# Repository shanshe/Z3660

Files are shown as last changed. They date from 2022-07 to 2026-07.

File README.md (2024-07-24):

# Z3660 by sHaNsHe (Double H Tech)

<br>Z3660 is an Amiga 4000 CPU accelerator board based on A3660 and Z-turn FPGA board.
<br>
<br>Compared to A3660, Z3660 has some key differences:
<br><p style="margin-left:1em;">
<br><b>1</b>. Z3660 accelerator board can only use 060 CPUs. This could be changed in the future, but at this time, only 060 is supported.
<br>
<br><b>2</b>. If Z-turn FPGA board is <b>NOT</b> used, then you get a simple A3660. The only difference is that all A3660 PLDs are replaced by a XC95144XL-10TQ144 CPLD. It could be possible to use 060 up to 100MHz, but only 50 MHz and 64 MHz has been tested. A board with 128 MB of CPU RAM is in the works (to be connected at Z-turn sockets).
<br>
<br><b>3</b>. If you <b>use a Z-turn FPGA board</b>, then you can add 128 MB of CPU RAM (DMA compatible), 256 MB of Z3 RAM (not DMA compatible), RTG 16bit, Ethernet, AHI and MHI. Also there is a SD to SCSI emulation for using raw RDB disk images (USB storage maybe in the future). And of course, you can use a 68060 rev6 at 100 MHz.
<br><p style="margin-left:0em;">
<br><b>Main branch. Z3660 with Z-turn FPGA</b>
<br>
<br>This main branch has everything you need to build a Z3660 with Z-turn FPGA.
<br>If you want to build Z3660 without Z-turn FPGA, please go to wo_FPGA branch. The board is the same, but the CPLD firmware and BOM are obviously different.
<br>
<br>Current version of Schematics is v021. It has all fixes needed by v02 to have DMA compatibility (tested with ReA4091 as bus master), so you can build it.
<br>
<br>The exact model of Z-Turn board you will need is: MYS-7Z020-V2 ( [mouser](https://www.mouser.com/c/?q=MYS-7Z020-V2-0E1D-766-C) (C or C-S. C-S has restrictions on EU - UK) ).

<br>
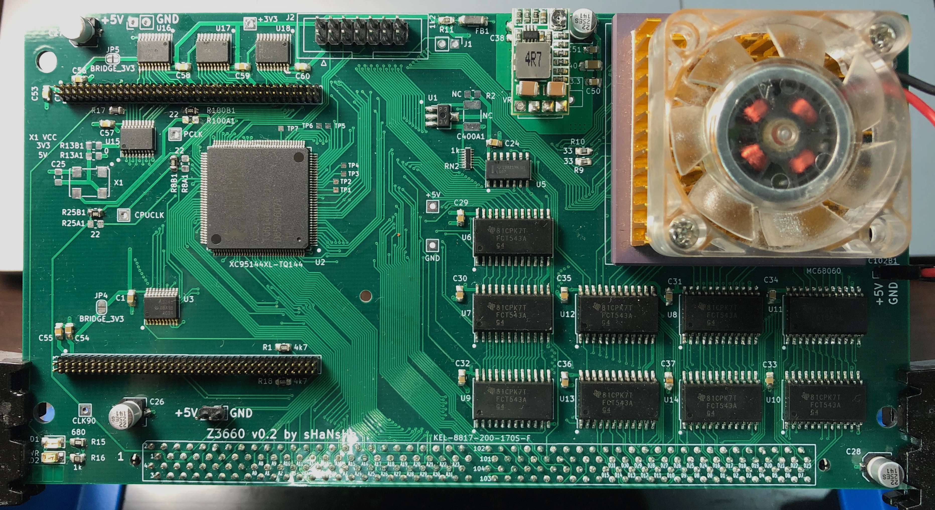
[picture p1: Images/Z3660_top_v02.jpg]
<br><p style="text-align:center;"><br>v0.2 Z3660 without FPGA</br></p>
<br>
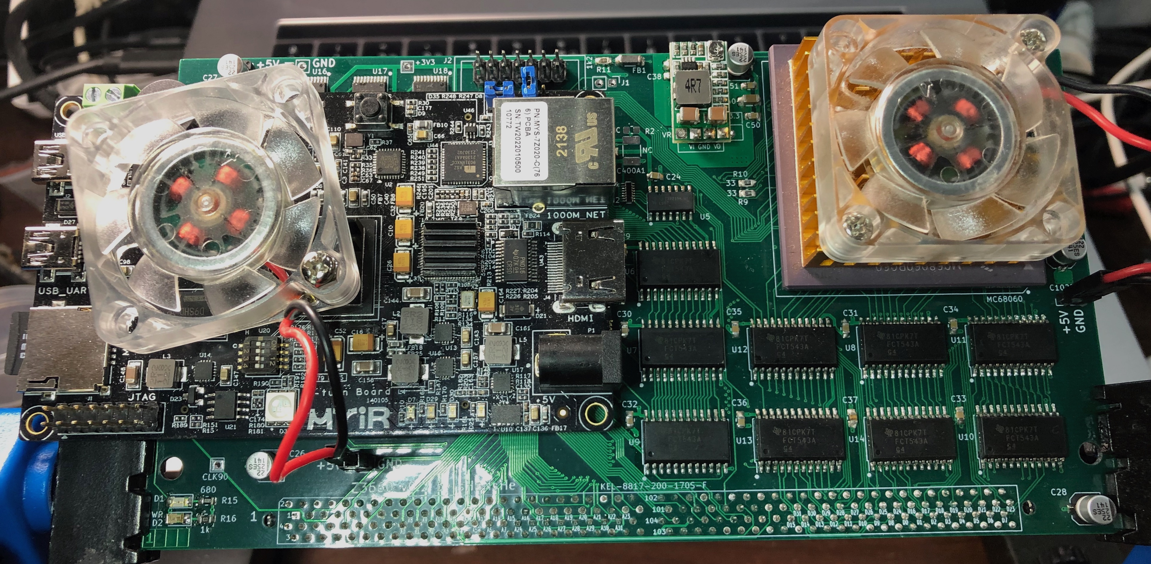
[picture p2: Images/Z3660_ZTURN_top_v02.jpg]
<br><p style="text-align:center;"><br>v0.2 Z3660 with FPGA</br></p>
In this version you can see that I have used a 3V3 DCDC converter, instead of old linear regulator on VR1. Board has both footprints in one. Please be careful with its connection.
<br>
<br>Note on RTG status: RTG is full working now. It has all features that ZZ9000 has (except obviously scandoubler). Due limitations of Z-turn, output video is limited to 16 bit.
<br>Manufacturer ID was asigned to 5195 decimal, 0x144B hexadecimal (thanks to Olaf Barthel).
<br>All RTG, AHI and MHI are based on [ZZ9000 RTG](https://source.mnt.re/explore).
It has the same band-pass filters as the AX module, but made in software by one of the ARMs.
<br>
<br><b>And finally, a checkmate move...</b>
<br>
<br><i>Don't have a 060 rev6 CPU, and still want to try Z3660 with a Z-turn?</i>
<br><i>sHaNsHe to the rescue!!! :P</i>
<br>
<br>One of the Z-turn ARM CPU can run the emulation code of a 68040 CPU with JIT that reaches up to 120 MIPS!!!<br>It is based on Amiberry CPU code (for 32bit ARM). (And yes, I know, but Emu68 no longer supports 32 bit ARM).
<br>You can even switch between the real 060 CPU and the emulation by clicking on an app (and rebooting).
<br>
<br><b>Discord channel link:</b>
<br><br>https://discord.gg/ua4u6SzyHf
<br>
<br><b>Documents to read before using your Z3660</b><br>
<br> You should read the "KNOWN_ISSUES.md" and "CHANGES.md" files to know the latest news.
<br> Thanks to ByteMavericks we have now the [wiki](https://github.com/shanshe/Z3660/wiki)

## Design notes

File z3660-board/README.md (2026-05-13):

# Z3660 PCB

In this folder are the fabrication files (Gerber) I have sent to JLCPCB.

I have built the first prototype of version v0.21 and it is working as expected.

# BOM revisions
v0.21
 * 08/04/2023: First version uploaded.

 * 08/11/2023: C27 capacitor has been removed from BOM because it is under Z-turn and there is no enough space for an electrolytic capacitor. You can use another 10uF SMD capacitor, or simply ignore it, we have a lot of capacitors in this board...

 * 08/13/2023: Updated BOM with I2C LTC2990 (tested today). It measures 5V, 3V3 and 060 THERM resistor.

v0.21a
 * 01/07/2024: Updated resistor network footprints to 4x (instead of 8x).
 * 01/07/2024: Updated electrolytic capacitor footprints to bigger ones.
 * 01/08/2024: Updated led values to differentiate green and red.
 * 01/08/2024: Uploaded BOM and CPL files for JLCPCB (thanks to @kavanoz64).
 
 v0.21b
 * 09/02/2024: Updated 060 footprint to 18x18 array pins (full 4 rows and columns).
 
 v0.21c
 * Invalid version - this was a misnamed upload during v0.21a release and should be disregarded.
 
 v.021d
 * 03/03/2024 Changed the footprints for two fans to 3-pin right-angle connectors.
 * 04/10/2024 Z3660_CPLD_prog is a tiny PCB to provide a CPLD programmer for v0.21x versions.
 
 v.022
 * 04/10/2024 Added an I2C gpio expander (PCF8574) to program the CPLD from the ARM.
 * 04/10/2024 Added optional onboard voltage regulator based on torsti76's <span>&#181;</span>VRM v0.1 design.
 
 v.023 (Contributed by @kavanoz)
 * 05/13/2026 Connected BOSS to DBG3 to allow motherboard CPU option.
 * 05/13/2026 Moved ZTurn 5mm towards the 060.
 * 05/13/2026 Removed voltage detector alternatives to save space for moving components.
 * 05/13/2026 Added a shunt for 3.34V solder jumper to set it as default. It needs to be cut before changing the onboard voltage regulator output.

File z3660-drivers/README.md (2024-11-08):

# Z3660 drivers

To build all these drivers, you will need vbcc and m68k-amigaos-gcc compilers. Also you will need a NDK (I'm using NDK from OS3.9).
<br>To build ZTop app you will need SASC under vamos emulation.
<br>See Makefile in order to adjust your paths.
<br>With the command line:
<br>`make all`
<br>you will compile all necessary drivers.
<br>If you have xdftool installed, then you can create an adf file that contains all drivers to be copied to your Amiga:
<br>`make adf`
<br>This will create an adf file called "0_Z3660.adf".
<br>The "z3660_scsi.rom" file (scsi directory) must be copied to the second partition of the SD (the exFAT formatted partition).

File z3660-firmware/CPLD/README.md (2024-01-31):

# Z3660 CPLD

Two versions here:

 * <b>DMA_WIP</b> is a "work in progress" (WIP) version, which works with Z3 DMA masters. Right now has some problems to boot, as it may need some reset before boot (maybe even power off-on cycles). This version only works with real cpus. CPU emulation has nothing to do with DMA (need some missing functions on emulation and a lot of test), so don't even try it...

 * <b>MASTER_no_DMA</b> version works with both, 060 and CPU emulation. Real cpu should be a 060 rev 6 as all firmware here is working only at 100 MHz. I have tried other frequencies, but only some "magic" frequencies work. ZTop app (z3660-drivers) will have some kind of frequency adjusment but right now this adjusment is internally disabled in this application. WIP.
 
Version History:
 * <b>v1.01</b>: First "official" version
 * <b>v1.02</b>: Update no_DMA version to get close to DMA branch (but still is a no_DMA version).
<br>
<br>

Important Note:
<br>
<br>You <b><i>should</i></b> use the vX.XX version with the same version numbers of BOOT.bin and drivers!!!

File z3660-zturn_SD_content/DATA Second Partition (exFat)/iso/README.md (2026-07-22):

# SCSI - CDROM Image files
Put in this directory all iso images that you want to mount with SD SCSI emulation (you can use up to 7 hdfs/isos).

Remember their names, you will need to name them exactly (with path: iso/image.iso) in the z3660cfg.txt file.

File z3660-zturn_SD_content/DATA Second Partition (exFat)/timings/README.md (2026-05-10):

# TIMING FILES
## Beta 18 and beta 19 versions:
The <b>timings.txt</b> is a text file with the name of the timings file that the ARM of the ZTurn board will use to generate all clocks needed for the Z3660.<br>

For now, we have only two sets of timings: A4000 and AA3000 (the systems that I own).<br>
The idea is that those files can be adapted to different systems, and if a user discovers that some different phases work better than others, the user can share those files and more users can benefit from it.
<br>
Starting version 1.03 BETA 18, the clock system has been changed so when an EMU is used, then the 060 is clocked to 50 MHz or less. For this reason the CPLD now needs to be programmed with the jed BETA 18 version.
<br>
## Beta 20 version:
The <b>timings.txt</b> is a text file with the name of the timings file that the ARM of the ZTurn board will use to generate all clocks needed for the Z3660.<br>

In this beta 20 version, we go back to CPLD beta 12 timings. We have a default timings file that work for A4000 and AA3000 (the systems that I own).<br>
The user can adapt the timings to different systems using the Ztop ARM app.<br>

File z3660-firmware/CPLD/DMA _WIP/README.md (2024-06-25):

# Z3660 CPLD

To build CPLD XC95144XL, I use ISE 13.1. Also I use IMPACT to flash the device, with a platform cable from Xilinx (use "JTAG" labeled connector of the PCB).
<br>Optionally, there are people flashing these CPLDs using a Raspberry Pi... google for it if you need it.
<br>The "z3660.jed" file is what you flash into the CPLD.

## NOTE WIP
This is a WIP version that is compatible with Z3 DMA devices. As it stated here, this firmware is under construction. WIP.

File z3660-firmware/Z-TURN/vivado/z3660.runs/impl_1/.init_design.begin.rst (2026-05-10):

<?xml version="1.0"?>
<ProcessHandle Version="1" Minor="0">
    <Process Command=".planAhead." Owner="shanshe" Host="COREBOX-X" Pid="1084">
    </Process>
</ProcessHandle>

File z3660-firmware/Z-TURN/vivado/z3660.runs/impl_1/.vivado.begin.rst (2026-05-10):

<?xml version="1.0"?>
<ProcessHandle Version="1" Minor="0">
    <Process Command="vivado.bat" Owner="shanshe" Host="COREBOX-X" Pid="10788" HostCore="4" HostMemory="017054048256">
    </Process>
</ProcessHandle>
<?xml version="1.0"?>
<ProcessHandle Version="1" Minor="0">
    <Process Command="vivado.bat" Owner="shanshe" Host="COREBOX-X" Pid="11004" HostCore="4" HostMemory="017054048256">
    </Process>
</ProcessHandle>
<?xml version="1.0"?>
<ProcessHandle Version="1" Minor="0">
    <Process Command="vivado.bat" Owner="shanshe" Host="COREBOX-X" Pid="15328" HostCore="4" HostMemory="017054048256">
    </Process>
</ProcessHandle>

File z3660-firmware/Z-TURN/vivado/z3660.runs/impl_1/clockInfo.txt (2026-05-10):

-------------------------------------
| Tool Version : Vivado v.2023.2
| Date         : Wed May  6 09:28:42 2026
| Host         : CoreBox-X
| Design       : design_1
| Device       : xc7z020-clg400-3--
-------------------------------------

For more information on clockInfo.txt clock routing debug file see https://support.xilinx.com/s/article/000035660?language=en_US

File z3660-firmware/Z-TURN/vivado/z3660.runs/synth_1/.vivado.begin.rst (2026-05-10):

<?xml version="1.0"?>
<ProcessHandle Version="1" Minor="0">
    <Process Command="vivado.bat" Owner="shanshe" Host="COREBOX-X" Pid="13924" HostCore="4" HostMemory="017054048256">
    </Process>
</ProcessHandle>

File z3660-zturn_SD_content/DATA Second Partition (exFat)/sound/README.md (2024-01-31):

# SOUND FILES
These are mp3 files with Siri/Alexa voices-like, to be played when you maintain reset more than 4 seconds.
<br>Just copy all these files.
<br>When you maintain reset you will hear, at the HDMI audio output, a voice telling you what is selected in this moment. The 4 files are for "060 CPU", "MUSASHI EMULATION", "UAE EMULATION" and "UAE JIT EMULATION" (in this order).
<br>
<br>Important Note:
<br>
<br>Right now only the "spa" (spanish voice) directory is played (it is hard coded in the ARM sources), so if you want to play the "eng" (english voice) files you should copy them to the "spa" directory.

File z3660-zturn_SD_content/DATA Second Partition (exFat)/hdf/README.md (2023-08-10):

# SCSI - Hard Disk Image files
Put in this directory all hdf images that you want to mount with SD SCSI emulation (you can use up to 7 hdfs).

Remember their names, you will need to name them exactly (with path: hdf/image.hdf) in the z3660cfg.txt file.

SD SCSI emulation <b>DO NOT</b> work with UAE single partition disk images. You can check what type the disk image is using a hex editor: if it starts with "RDSK", it is a full drive RDSK/RDB image and will work here. If it starts with "DOS" it is most likely a UAE single partition disk image and will not work.

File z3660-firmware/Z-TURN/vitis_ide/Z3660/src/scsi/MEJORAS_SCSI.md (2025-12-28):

# Mejoras del módulo SCSI (Z3660/src/scsi)

Fecha: 2025-08-24
Ámbito: scsi.c, scsi.h, hunk-reloc.c, hunk-reloc.h, z3660_scsi_enums.h

Objetivo: Recopilar y priorizar mejoras de robustez, seguridad, rendimiento y mantenibilidad en el subsistema SCSI del proyecto Z3660.

Resumen de prioridades
- Alta: correcciones que previenen fallos, desbordamientos, fugas y corrupción de datos.
- Media: robustez, validaciones, consistencia de API, tratamiento de errores y límites.
- Baja: rendimiento fino, ordenamiento del código, mejoras de logging y observabilidad.

Prioridad alta (bugs y riesgos)
1) Índice de unidad fuera de rango
- Problema: en piscsi_map_drive(), el control usa if (index > NUM_SCSI_UNITS_MAX). Permite index == NUM_SCSI_UNITS_MAX, fuera de rango.
- Mejora: cambiar a if (index >= NUM_SCSI_UNITS_MAX) y devolver error claro.
- Ficheros: scsi.c

2) Valor inválido de piscsi_cur_drive (255) y accesos no validados
- Problema: PISCSI_CMD_DRVNUM puede asignar 255; varias lecturas usan devs[piscsi_cur_drive] sin validar.
- Mejora: no asignar valores inválidos; si la entrada es inválida, conservar el valor actual y devolver 0/ERR. Alternativamente, validar piscsi_cur_drive >= NUM_SCSI_UNITS_MAX en cada uso y abortar segura/rápidamente.
- Ficheros: scsi.c

3) Fugas de memoria en piscsi_find_filesystems()
- Problema: se hace malloc de fhb_block en el bucle y no siempre se libera (leak); sólo algunas copias se guardan en filesystems[].fhb.
- Mejora: usar un buffer de escaneo único (malloc una vez), y cuando se deba persistir un FSHD, copiarlo explícitamente a filesystems[i].fhb (malloc + memcpy). Liberar el buffer de escaneo al final.
- Ficheros: scsi.c

4) Tamaño y límites de relocalización (HUNK_RELOC)
- Problema: piscsi_hreloc es 2048 pero filesystems[i].relocs es 4096; hunk-reloc no limita el número de entradas y puede sobrescribir memoria si hay muchas relocs.
- Mejora: definir una constante global MAX_HUNK_RELOCS (por ejemplo, 4096) y:
  - Dimensionar piscsi_hreloc a MAX_HUNK_RELOCS.
  - En HUNKTYPE_HUNK_RELOC32, cortar si se supera MAX_HUNK_RELOCS y devolver error.
  - Propagar el error a quien llama.
- Ficheros: scsi.c, hunk-reloc.c, scsi.h (si se expone la constante)

5) Validación de block_size
- Problema: d->block_size proviene del RDB sin validar y se usa en malloc y lecturas.
- Mejora: validar 0 < block_size <= PISCSI_MAX_BLOCK_SIZE y que sea múltiplo de 512. Si no, decidir política: fijar 512 o abortar.
- Ficheros: scsi.c

6) Persistencia tras escrituras (f_sync)
- Problema: tras f_write no se llama a f_sync; riesgo de pérdida de datos en reset/cortes.
- Mejora: llamar a f_sync(d->fd) al finalizar operaciones de escritura de alto nivel o según umbral de bytes acumulados; opcionalmente controlable por configuración.
- Ficheros: scsi.c

7) Lecturas/escrituras RAW SD no alineadas a bloque
- Problema: en backend RAW (disk_read/disk_write) se calcula blocks = bytes / block_size y se ignora el resto.
- Mejora: definir política clara: o rechazar tamaños no alineados con error, o manejar el remanente con buffer temporal.
- Ficheros: scsi.c

8) Límite de particiones
- Problema: d->pb[16]; al seguir la lista enlazada PARTITIONLIST no se corta explícitamente tras 16.
- Mejora: si cur_partition alcanza 16, dejar de cargar y avisar.
- Ficheros: scsi.c

Robustez y corrección
1) Inclusión circular innecesaria
- Problema: hunk-reloc.h incluye scsi.h y scsi.h incluye hunk-reloc.h.
- Mejora: eliminar include de scsi.h en hunk-reloc.h (no es necesario); si se requieren tipos, reubicar typedefs o usar forward declarations.
- Ficheros: hunk-reloc.h

2) Firmas const-correct
- Mejora: io_cmd_name() y scsi_cmd_name() deben devolver const char*.
- Ficheros: scsi.c

3) Límite de filesystems
- Problema: piscsi_num_fs puede exceder NUM_FILESYSTEMS si hay demasiados FSHD.
- Mejora: comprobar y dejar de cargar (con log) al alcanzar NUM_FILESYSTEMS.
- Ficheros: scsi.c

4) Control de errores más consistente
- Observación: a veces se imprime error tras f_read/f_write/disk_read pero no se propaga y se continúa.
- Mejora: unificar estrategia: si un acceso a disco falla, propagar el error y abortar la operación (evitar relocalizaciones/copias con datos incompletos). Añadir códigos de retorno o enum de errores.
- Ficheros: scsi.c, hunk-reloc.c

5) Validación de punteros mágicos en backend
- Problema: se usa (FIL*)1 para distinguir RAW SD vs archivo.
- Mejora: añadir campo backend en PISCSI_DEV (FILE/HDF vs RAW_SD) y evitar comparaciones de punteros. Centralizar lógica de IO.
- Ficheros: scsi.h (enum/flag), scsi.c

6) Nombres de partición y límites de buffer
- Problema: al renombrar particiones duplicadas se puede exceder pb_DriveName[32].
- Mejora: usar snprintf y validar longitud; no exceder 31 chars + NUL. Actualizar pb->pb_DriveName[0] coherentemente.
- Ficheros: scsi.c

7) Validación de punteros/offsets de FSHD
- Mejora: validar que fhb->fhb_Next y rdb->rdb_FileSysHeaderList estén dentro del tamaño del dispositivo. Si se sale, abortar con aviso.
- Ficheros: scsi.c

8) Valores CHS fabricados
- Mejora: al inventar CHS en falta de RDB, evitar overflow y documentar el cálculo. Considerar 255 heads/63 secs si el tamaño es grande (compatibilidad común), o usar LBA puro en capas superiores.
- Ficheros: scsi.c

Rendimiento
1) Flushing/invalidating por rango
- Mejora: usar Xil_L1DCacheFlushRange/InvalidateRange con puntero + tamaño cuando se conoce el buffer, en lugar de flush global. Reduce latencias.
- Ficheros: scsi.c

2) Reutilización de buffers
- Mejora: reservar buffers reutilizables (p. ej., para bloques de tamaño d->block_size y para FSHD) y evitar malloc/free repetido en bucles.
- Ficheros: scsi.c

3) Tamaño de ráfagas de IO
- Mejora: MAX_BLOCKS_AT_ONCE a una constante configurable en cabecera. Ajustar a límites del controlador y tamaño de caché.
- Ficheros: scsi.c, scsi.h (si procede)

4) memcpy_neon firma y fallback
- Mejora: declarar extern void* memcpy_neon(void* restrict dst, const void* restrict src, uint32_t n); usar memcpy para tamaños pequeños o no alineados. Evitar u32 si no está definido.
- Ficheros: scsi.c (declaración);

Mantenibilidad
1) Helpers de mapeo de memoria
- Mejora: extraer helpers:
  - bool is_fpga_mapped_addr(uint32_t a, const CONFIG* cfg)
  - uint32_t translate_fpga_to_arm(uint32_t a)
  - bool in_cpu_ram_range(uint32_t a), bool in_autoconfig_ram_range(uint32_t a)
- Beneficio: eliminar duplicación y errores (p. ej. restar 0x20000000 para 0x40000000–0x4fffffff).
- Ficheros: scsi.c (nuevas funciones estáticas)

2) API de backend de IO unificada
- Mejora: crear piscsi_seek_bytes(), piscsi_read_bytes(), piscsi_write_bytes(), piscsi_read_blocks(), piscsi_write_blocks() que internen la diferencia FILE vs RAW SD.
- Beneficio: simplifica el manejo de errores, f_sync y métricas.
- Ficheros: scsi.c, scsi.h (si se expone)

3) Tipos y casts explícitos
- Mejora: usar size_t/FSIZE_t donde corresponda; añadir casts explícitos 32↔64 para offsets.
- Ficheros: scsi.c, hunk-reloc.c

4) Logging y rutas del usuario
- Mejora: centralizar DEBUG/printf bajo función que permita, opcionalmente, volcar a archivos de log del usuario:
  - /Volumes/datos/log.txt
  - /Volumes/datos/log_arm.txt
  - /Volumes/datos/log_trident.txt
- Añadir niveles (INFO/WARN/ERR/DEBUG) y toggles vía debug_console.
- Ficheros: scsi.c (envoltorio de logging)

5) Unificación de macros endian
- Mejora: unificar BE, BE16, etc., en una cabecera común y usar consistentemente.
- Ficheros: scsi.c, hunk-reloc.c, scsi.h

Calidad de parsing (RDB/FS)
1) Verificación de checksums
- Mejora: comprobar rdb_ChkSum/pb_ChkSum/fhb_ChkSum cuando sea viable para detectar corrupción.
- Ficheros: scsi.c

2) Límites de recorrido
- Mejora: límite superior en RDB_BLOCK_LIMIT configurable; detener si se encuentran valores improbables.
- Ficheros: scsi.h (const), scsi.c

3) Manejo de errores en LSEG
- Mejora: en load_lseg/process_hunks, propagar errores de I/O y truncar con mensajes claros.
- Ficheros: hunk-reloc.c

Quick wins (bajo riesgo, alto valor)
- [ ] Cambiar if (index > NUM_SCSI_UNITS_MAX) por if (index >= NUM_SCSI_UNITS_MAX) en piscsi_map_drive().
- [ ] Validar piscsi_cur_drive antes de acceder a devs[]. Si inválido, devolver 0/ERR y log.
- [ ] io_cmd_name()/scsi_cmd_name() → const char*.
- [ ] Eliminar include de scsi.h en hunk-reloc.h (evitar inclusión circular).
- [ ] Unificar MAX_HUNK_RELOCS a 4096 y dimensionar piscsi_hreloc con ese valor.
- [ ] Añadir guardas en HUNKTYPE_HUNK_RELOC32 para no exceder MAX_HUNK_RELOCS.
- [ ] Llamar a f_sync(d->fd) tras escrituras grandes o al finalizar comandos de escritura.
- [ ] Validar y normalizar block_size tras parsear RDB (múltiplo de 512 y ≤ PISCSI_MAX_BLOCK_SIZE); fallback a 512 o abortar.
- [ ] Límite de 16 particiones: cortar recorrido y avisar si se excede.
- [ ] Comprobar piscsi_num_fs contra NUM_FILESYSTEMS en piscsi_find_filesystems().
- [ ] Rechazar o manejar remanentes en RAW SD si bytes % block_size != 0.

Observabilidad (opcional pero útil)
- [ ] Contadores: bytes leídos/escritos, errores de I/O, tiempos por operación (medidos), número de flushes de caché.
- [ ] Traces de comandos: BeginIO, SCSICMD, READ/WRITE con tamaños y tiempos cuando el debug esté activo.

Plan sugerido de adopción por fases
Fase 1 (1–2 commits rápidos)
- Quick wins anteriores (validaciones, límites, const-correct, include, MAX_HUNK_RELOCS + guardas, block_size, f_sync). Riesgo bajo.

Fase 2 (robustez de I/O y parsing)
- Backend explícito en PISCSI_DEV y helpers de I/O.
- Reutilización de buffers + corrección de fugas en piscsi_find_filesystems().
- Validaciones extra de RDB/FS (offsets, checksums, límites de partición/FS).

Fase 3 (rendimiento y limpieza)
- Cache flush por rango, unificación de macros endian, logging configurable, métricas.

Notas de implementación y ubicación
- Validaciones de índice/cur_drive: scsi.c (handlers de lectura/escritura y piscsi_map_drive()).
- f_sync: scsi.c (ruta de WRITE/WRITE64/WRITEBYTES; un posible “end of command” natural tras completar la escritura).
- MAX_HUNK_RELOCS: definir en scsi.h o nueva cabecera; usar en scsi.c y hunk-reloc.c.
- Guardas en relocalización: hunk-reloc.c (HUNKTYPE_HUNK_RELOC32, cortar y retornar error si se excede el límite).
- Backend explícito: añadir enum/flag en PISCSI_DEV (scsi.h) y setearlo en piscsi_map_drive().
- Reutilización de buffers: scsi.c (buffers estáticos o miembros en PISCSI_DEV si conviene).
- Eliminación de include circular: hunk-reloc.h (quitar include de scsi.h).

Fragmento clave (selección del usuario)
- Control de errores más consistente
  • A veces se imprime error tras f_read/f_write/disk_read pero no se propaga el fallo ni se aborta la operación. Conviene unificar: si un acceso a disco falla, devolver error hacia arriba y no continuar con copias/relocs.

Checklist global
- [ ] Validar índices y estados antes de acceder a devs[] (incluyendo piscsi_cur_drive).
- [ ] Normalizar block_size y rechazar valores inválidos.
- [ ] Límite de particiones y filesystems respetados.
- [ ] Guardas de relocalización implementadas y tamaño de buffers consistente.
- [ ] Fugas de memoria eliminadas (buffers de escaneo FSHD, devs[i].pb[j]).
- [ ] Política de I/O RAW para tamaños no alineados decidida e implementada.
- [ ] f_sync aplicado donde corresponda.
- [ ] Cache flush por rango aplicado donde es posible.
- [ ] Backend explícito y helpers de I/O creados.
- [ ] Logging centralizado con niveles y posibilidad de volcar a rutas del usuario.

Notas finales
- Estas mejoras están pensadas para minimizar riesgos en datos y facilitar diagnóstico, manteniendo la compatibilidad.
- Las “quick wins” son seguras y recomendadas para aplicar primero.
- Las fases 2 y 3 pueden hacerse de forma incremental con pruebas entre cada cambio.

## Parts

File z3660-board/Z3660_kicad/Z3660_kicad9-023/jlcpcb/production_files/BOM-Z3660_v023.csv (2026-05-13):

Comment | Designator | Footprint | LCSC | Quantity
100k | R31 | R_0603_1608Metric_Pad0.98x0.95mm_HandSolder | C25803 | 1
100nF | C67 | C_0603_1608Metric_Pad1.08x0.95mm_HandSolder | C14663 | 1
100nF | C1,C10,C11,C12,C13,C14,C15,C16,C17,C18,C19,C2,C20,C21,C22,C23,C24,C25,C29,C3,C30,C31,C32,C33,C34,C35,C36,C37,C38,C4,C44,C45,C46,C47,C48,C49,C5,C50,C51,C52,C53,C54,C55,C56,C57,C58,C59,C6,C60,C63,C64,C7,C8,C9 | C_0805_2012Metric_Pad1.18x1.45mm_HandSolder | C49678 | 54
10k | R34 | R_0603_1608Metric_Pad0.98x0.95mm_HandSolder | C25804 | 1
10nF | C65 | C_0603_1608Metric_Pad1.08x0.95mm_HandSolder | C57112 | 1
10uF | C39,C40,C42,C43 | C_1206_3216Metric_Pad1.33x1.80mm_HandSolder | C13585 | 4
10uF | C68 | C_0805_2012Metric_Pad1.18x1.45mm_HandSolder | C440198 | 1
10uH | L1 | L_Bourns_SRP7028A_7.3x6.6mm | C128692 | 1
120 | R19 | R_0805_2012Metric_Pad1.20x1.40mm_HandSolder | C17437 | 1
1k | R14,R16,R20,R21,R5,R6,R7,R8 | R_0805_2012Metric_Pad1.20x1.40mm_HandSolder | C17513 | 8
1k | RN1,RN11,RN12,RN13,RN14,RN15,RN16,RN17,RN18,RN19,RN2,RN20,RN21,RN22 | R_Array_Convex_4x0603 | C20197 | 14
1k 0.1% | R23,R24,R25 | R_0805_2012Metric_Pad1.20x1.40mm_HandSolder | C110774 | 3
1k2 | R11 | R_0805_2012Metric_Pad1.20x1.40mm_HandSolder | C17379 | 1
22 | RN10,RN3,RN4,RN5,RN6,RN7,RN8,RN9 | R_Array_Convex_4x0603 | C12008 | 8
22uF | C27 | CP_Elec_6.3x3.9 | C2761583 | 1
22uF | C26,C28,C41,C61,C62 | CP_Elec_6.3x5.4 | C445045 | 5
22uF | C69 | C_0805_2012Metric_Pad1.18x1.45mm_HandSolder | C45783 | 1
26.1k* | R32 | R_0603_1608Metric_Pad0.98x0.95mm_HandSolder | C23356 | 1
27.0k | R35 | R_0603_1608Metric_Pad0.98x0.95mm_HandSolder | C22967 | 1
27.4k | R36 | R_0603_1608Metric_Pad0.98x0.95mm_HandSolder | C2933186 | 1
28.0k | R37 | R_0603_1608Metric_Pad0.98x0.95mm_HandSolder | C22989 | 1
3.9nF | C66 | C_0603_1608Metric_Pad1.08x0.95mm_HandSolder | C1618 | 1
33 | R10,R28,R29,R9 | R_0805_2012Metric_Pad1.20x1.40mm_HandSolder | C17634 | 4
4k7 | R1,R13,R17,R18,R3 | R_0805_2012Metric_Pad1.20x1.40mm_HandSolder | C17673 | 5
6.8k | R33 | R_0603_1608Metric_Pad0.98x0.95mm_HandSolder | C23212 | 1
680 | R15 | R_0805_2012Metric_Pad1.20x1.40mm_HandSolder | C17798 | 1
7407 | U5 | SOIC-14_3.9x8.7mm_P1.27mm | C40481 | 1
74FCT543A | U10,U11,U12,U13,U14,U6,U7,U8,U9 | SOIC-24W_7.5x15.4mm_P1.27mm | C2863309 | 9
9k 0.1% | R22,R26,R27,R30 | R_0805_2012Metric_Pad1.20x1.40mm_HandSolder | C868262 | 4
BU4942 | U1B1 | TSOP-5_1.65x3.05mm_P0.95mm | C2067989 | 1
Conn_02x40_Odd_Even | CN2,CN3 | PinHeader_2x40_P1.27mm_Vertical | C7470095 | 2
Ferrite_Bead_Small | FB1 | Fuse_1806_4516Metric_Pad1.57x1.80mm_HandSolder | C88998 | 1
JTAG | J2 | PinHeader_1x06_P2.54mm_Vertical | C6332199 | 1
Jumper_2_Open | J1 | PinHeader_1x02_P2.54mm_Vertical | C358684 | 1
Jumper_3_Open | JP2,JP6,JP7 | PinHeader_1x03_P2.54mm_Vertical | C429954 | 3
Jumper_NO_Small | JP1,JP3 | PinHeader_1x03_P2.54mm_Horizontal | C722746 | 2
LED_Small_Green | D1 | LED_1206_3216Metric_Pad1.42x1.75mm_HandSolder | C434442 | 1
LED_Small_Red | D2 | LED_1206_3216Metric_Pad1.42x1.75mm_HandSolder | C434438 | 1
LTC2990 | U1 | MSOP-10_3x3mm_P0.5mm | C683931 | 1
MC68060 | U4 | PGA226 | C9900095602 | 1
MP2307 | U20 | SOIC-8-1EP_3.9x4.9mm_P1.27mm_EP2.514x3.2mm | C18921 | 1
PCF8574TS | U19 | TSSOP-20_4.4x6.5mm_P0.65mm | C57790 | 1
SN74CB3T3245PW | U15,U16,U17,U18,U3 | TSSOP-20_4.4x6.5mm_P0.65mm | C15298 | 5
XC95144XL-TQ144 | U2 | TQFP-144_20x20mm_P0.5mm | C1521137 | 1

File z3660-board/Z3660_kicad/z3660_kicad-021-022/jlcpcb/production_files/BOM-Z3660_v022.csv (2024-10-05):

Comment | Designator | Footprint | LCSC
LTC2990 | U1 | MSOP-10_3x3mm_P0.5mm | C107804
1k 0.1% | R23,R24,R25 | R_0805_2012Metric_Pad1.20x1.40mm_HandSolder | C110774
22 | RN10,RN3,RN4,RN5,RN6,RN7,RN8,RN9 | R_Array_Convex_4x0603 | C12008
Conn_02x40_Odd_Even | CN2,CN3 | PinHeader_2x40_P1.27mm_Vertical | C124356
Conn_02x07_Odd_Even | J2 | IDC-Header_2x07_P2.54mm_Vertical | C132432
10uF | C39,C40,C42,C43 | C_1206_3216Metric_Pad1.33x1.80mm_HandSolder | C13585
100nF | C67 | C_0603_1608Metric | C14663
XC95144XL-TQ144 | U2 | TQFP-144_20x20mm_P0.5mm | C1521137
SN74CB3T3245PW | U15,U16,U17,U18,U3 | TSSOP-20_4.4x6.5mm_P0.65mm | C15298
10µF | C68 | C_0805_2012Metric | C15850
3.9nF | C66 | C_0603_1608Metric | C1618
1k2 | R11 | R_0805_2012Metric_Pad1.20x1.40mm_HandSolder | C17379
100 | R13 | R_0805_2012Metric_Pad1.20x1.40mm_HandSolder | C17408
10k | R2 | R_0805_2012Metric_Pad1.20x1.40mm_HandSolder | C17414
120 | R19 | R_0805_2012Metric_Pad1.20x1.40mm_HandSolder | C17437
1k | R14,R16,R20,R21,R5,R6,R7,R8 | R_0805_2012Metric_Pad1.20x1.40mm_HandSolder | C17513
33 | R10,R28,R29,R9 | R_0805_2012Metric_Pad1.20x1.40mm_HandSolder | C17634
4k7 | R1,R17,R18,R3,R4 | R_0805_2012Metric_Pad1.20x1.40mm_HandSolder | C17673
680 | R15 | R_0805_2012Metric_Pad1.20x1.40mm_HandSolder | C17798
MP2307 | U20 | SOIC-8-1EP_3.9x4.9mm_P1.27mm_EP2.514x3.2mm | C18921
1k | RN1,RN11,RN12,RN13,RN14,RN15,RN16,RN17,RN18,RN19,RN2,RN20,RN21,RN22 | R_Array_Convex_4x0603 | C20197
BU4942 | U1B1 | TSOP-5_1.65x3.05mm_P0.95mm | C2067989
10µH | L1 | L_Bourns_SRP7028A_7.3x6.6mm | C208101
27.0k | R35 | R_0603_1608Metric | C22967
28.0k | R37 | R_0603_1608Metric | C22989
6.8k | R33 | R_0603_1608Metric | C23212
26.1k* | R32 | R_0603_1608Metric | C23356
100k | R31 | R_0603_1608Metric | C25803
10k | R34 | R_0603_1608Metric | C25804
22uF | C27 | CP_Elec_6.3x3.9 | C2761583
9k 0.1% | R22,R26,R27,R30 | R_0805_2012Metric_Pad1.20x1.40mm_HandSolder | C2828721
74FCT543A | U10,U11,U12,U13,U14,U6,U7,U8,U9 | SOIC-24W_7.5x15.4mm_P1.27mm | C2863309
27.4k | R36 | R_0603_1608Metric | C321828
Jumper_2_Open | J1 | PinHeader_1x02_P2.54mm_Vertical | C358684
7407 | U5 | SOIC-14_3.9x8.7mm_P1.27mm | C40481
Jumper_NO_Small | JP2,JP6,JP7 | PinHeader_1x03_P2.54mm_Vertical | C429954
LED_Small_Red | D2 | LED_1206_3216Metric_Pad1.42x1.75mm_HandSolder | C434438
LED_Small_Green | D1 | LED_1206_3216Metric_Pad1.42x1.75mm_HandSolder | C434442
22uF | C26,C28,C41,C61,C62 | CP_Elec_6.3x3.9 | C445045
22µF | C69 | C_0805_2012Metric | C45783
100nF | C1,C10,C11,C12,C13,C14,C15,C16,C17,C18,C19,C2,C20,C21,C22,C23,C24,C25,C29,C3,C30,C31,C32,C33,C34,C35,C36,C37,C38,C4,C44,C45,C46,C47,C48,C49,C5,C50,C51,C52,C53,C54,C55,C56,C57,C58,C59,C6,C60,C63,C64,C7,C8,C9 | C_0805_2012Metric_Pad1.18x1.45mm_HandSolder | C49678
10nF | C65 | C_0603_1608Metric | C57112
PCF8574TS | U19 | TSSOP-20_4.4x6.5mm_P0.65mm | C57790
Jumper_NO_Small | JP1,JP3 | PinHeader_1x03_P2.54mm_Horizontal | C722746
Ferrite_Bead_Small | FB1 | Fuse_1806_4516Metric_Pad1.57x1.80mm_HandSolder | C88998
MC68060 | U4 | PGA226 | C9900095602
RH5VA43A | U1A1 | SOT-89-3_Handsoldering
IQXO-70 | X1 | Oscillator_SMD_IQD_IQXO70-4Pin_7.5x5.0mm
MountingHole | H1 | MountingHole_4mm
MountingHole | H2 | MountingHole_4mm
MountingHole | H4 | MountingHole_4mm
MountingHole | H5 | MountingHole_2.2mm_M2
MountingHole | H6 | MountingHole_2.2mm_M2
MountingHole | H3 | MountingHole_4mm
+3V3 | TP1 | TestPoint_THTPad_2.0x2.0mm_Drill1.0mm
GND | TP8 | TestPoint_THTPad_2.0x2.0mm_Drill1.0mm
PCLK | TP9 | TestPoint_THTPad_2.0x2.0mm_Drill1.0mm
CLK90 | TP10 | TestPoint_THTPad_2.0x2.0mm_Drill1.0mm
CPUCLK | TP11 | TestPoint_THTPad_2.0x2.0mm_Drill1.0mm
BRIDGE_3V3 | JP4 | SolderJumper-2_P1.3mm_Open_RoundedPad1.0x1.5mm
SolderJumper_3_Bridged12 | JP9 | SolderJumper-3_P1.3mm_Bridged12_RoundedPad1.0x1.5mm_NumberLabels
SolderJumper_3_Bridged12 | JP10 | SolderJumper-3_P1.3mm_Bridged12_RoundedPad1.0x1.5mm_NumberLabels
PCLK | DBG2 | TestPoint_THTPad_2.0x2.0mm_Drill1.0mm
SolderJumper_3_Bridged12 | JP8 | SolderJumper-3_P1.3mm_Bridged12_RoundedPad1.0x1.5mm_NumberLabels
SolderJumper_3_Bridged12 | JP11 | SolderJumper-3_P1.3mm_Bridged12_RoundedPad1.0x1.5mm_NumberLabels
MountingHole | H7 | MountingHole_2.2mm_M2
MountingHole | H8 | MountingHole_2.2mm_M2
PCLK | DBG3 | TestPoint_THTPad_2.0x2.0mm_Drill1.0mm
LT1084-3.3_EXTENDED | VR1 | Regulador_DCDC
BRIDGE_3V3 | JP5 | SolderJumper-2_P1.3mm_Open_RoundedPad1.0x1.5mm
PCLK | DBG1 | TestPoint_THTPad_2.0x2.0mm_Drill1.0mm
+5V | TP4 | TestPoint_THTPad_2.0x2.0mm_Drill1.0mm
KEL-8817-200-170S-F | CN1 | xIP-200
SolderJumper_3_Bridged12 | JP12 | SolderJumper-3_P1.3mm_Bridged12_RoundedPad1.0x1.5mm_NumberLabels
NC | R12 | R_0805_2012Metric_Pad1.20x1.40mm_HandSolder
SolderJumper_2_Open | JP13 | small_SolderJumper-2_P1.3mm_Open_RoundedPad1.0x1.5mm
SolderJumper_2_Open | JP16 | small_SolderJumper-2_P1.3mm_Open_RoundedPad1.0x1.5mm
SolderJumper_2_Open | JP14 | small_SolderJumper-2_P1.3mm_Open_RoundedPad1.0x1.5mm
SolderJumper_2_Open | JP15 | small_SolderJumper-2_P1.3mm_Open_RoundedPad1.0x1.5mm

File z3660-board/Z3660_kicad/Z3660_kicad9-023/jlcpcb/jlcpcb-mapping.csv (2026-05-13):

Footprint | Part Value | LCSC Part
0603@3 | 100nF | C14663
0805 | 0Ohm | C17477
0805 | 100nF | C49678
0805 | 100Ohm | C17408
0805 | 1k | C17513
0805 | 22Ohm | C17561
0805 | 33Ohm | C17634
0805 | 3k16 | C52603
1206 | 40R 6A | C357018
1206 | 48R 6A | C357018
BGA-169_11.0x11.0mm_Layout13x13_P0.8mm_Ball0.5mm_Pad0.35mm_NSMD | 10M02SCU169C8G | C1521951
C1210K | 22uF/10V | C2918510
C1210K | 22uF/16V | C2918510
CP_Elec_6.3x3.9 | 22uF | C2761583
CP_Elec_6.3x5.4 | 22uF | C445045
C_0603_1608Metric_Pad1.05x0.95mm_HandSolder | 0.01uF | C57112
C_0603_1608Metric_Pad1.05x0.95mm_HandSolder | 0.1uF | C14663
C_0603_1608Metric_Pad1.08x0.95mm_HandSolder | 100nF | C14663
C_0603_1608Metric_Pad1.08x0.95mm_HandSolder | 10uF | C96446
C_0603_1608Metric_Pad1.08x0.95mm_HandSolder | 1uF | C15849
C_0603_1608Metric_Pad1.08x0.95mm_HandSolder | 3.9nF | C1618
C_0603_1608Metric_Pad1.08x0.95mm_HandSolder | 4.7uF | C19666
C_0805_2012Metric_Pad1.15x1.40mm_HandSolder | 0.1uF | C49678
C_0805_2012Metric_Pad1.15x1.40mm_HandSolder | 1uF | C28323
C_0805_2012Metric_Pad1.18x1.45mm_HandSolder | 100nF | C49678
C_0805_2012Metric_Pad1.18x1.45mm_HandSolder | 10µF | C15850
C_0805_2012Metric_Pad1.18x1.45mm_HandSolder | 22µF | C45783
C_1206_3216Metric | 100uF | C24497
C_1206_3216Metric_Pad1.33x1.80mm_HandSolder | 10uF | C13585
C_1206_3216Metric_Pad1.42x1.75mm_HandSolder | 10uF | C13585
C_Elec_5x5.4 | 22uF | C401783
Fuse_1806_4516Metric_Pad1.57x1.80mm_HandSolder | Ferrite_Bead_Small | C88998
IDC-Header_2x07_P2.54mm_Vertical | Conn_02x07_Odd_Even | C132432
LED_1206_3216Metric_Pad1.42x1.75mm_HandSolder | LED_Small | C434438
LED_1206_3216Metric_Pad1.42x1.75mm_HandSolder | LED_Small_Green | C434442
L_0603_1608Metric_Pad1.05x0.95mm_HandSolder | FerriteBead | C88974
L_Bourns_SRP7028A_7.3x6.6mm | 10µH | C208101
MINIMELF | 1N4148 | C183025
MSOP-10_3x3mm_P0.5mm | LTC2990 | C107804
MSOP10 | LTC 2990 | C107804
PGA226 | MC68060 | C9900095602
PinHeader_1x02_P2.54mm_Vertical | Jumper_2_Open | C358684
PinHeader_1x03_P2.54mm_Horizontal | Jumper_NO_Small | C722746
PinHeader_1x03_P2.54mm_Vertical | Jumper_3_Open | C429954
PinHeader_1x06_P2.54mm_Vertical | JTAG | C6332199
PinHeader_2x20_P2.54mm_Horizontal | A500 MEM EXP | C22373943
PinHeader_2x40_P1.27mm_Vertical | Conn_02x40_Odd_Even | C7470095
R-NETZ@2 | 1k | C160614
R-NETZ@2 | 33Ohm | C25508
R0805 | 1.0K 0 1% | C309081
R0805 | 1.0K 0,1% | C309081
R0805 | 10.0K 0 1% | C406725
R0805 | 10.0K 0,1% | C406725
R0805 | 470Ohm | C17710
R0805 | 470Ohm 0 1% | C706281
R0805 | 470Ohm 0,1% | C706281
RESCAF80P320X160X60-8N | 10k | C29718
R_0603_1608Metric_Pad0.98x0.95mm_HandSolder | 100k | C25803
R_0603_1608Metric_Pad0.98x0.95mm_HandSolder | 10K | C25804
R_0603_1608Metric_Pad0.98x0.95mm_HandSolder | 26.1k* | C23356
R_0603_1608Metric_Pad0.98x0.95mm_HandSolder | 27.0k | C22967
R_0603_1608Metric_Pad0.98x0.95mm_HandSolder | 27.4k | C321828
R_0603_1608Metric_Pad0.98x0.95mm_HandSolder | 28.0k | C22989
R_0603_1608Metric_Pad0.98x0.95mm_HandSolder | 6.8k | C23212
R_0805_2012Metric_Pad1.20x1.40mm_HandSolder | 33 | C17634
R_0805_2012Metric_Pad1.20x1.40mm_HandSolder | 100 | C17408
R_0805_2012Metric_Pad1.20x1.40mm_HandSolder | 120 | C17437
R_0805_2012Metric_Pad1.20x1.40mm_HandSolder | 680 | C17798
R_0805_2012Metric_Pad1.20x1.40mm_HandSolder | 10k | C17414
R_0805_2012Metric_Pad1.20x1.40mm_HandSolder | 1k | C17513
R_0805_2012Metric_Pad1.20x1.40mm_HandSolder | 1k 0.1% | C110774
R_0805_2012Metric_Pad1.20x1.40mm_HandSolder | 1k2 | C17379
R_0805_2012Metric_Pad1.20x1.40mm_HandSolder | 4k7 | C17673
R_0805_2012Metric_Pad1.20x1.40mm_HandSolder | 9k 0.1% | C2828721
R_Array_Convex_4x0603 | 22 | C12008
R_Array_Convex_4x0603 | 68 | C458667
R_Array_Convex_4x0603 | 1k | C20197
SO-8 | ICS570A/B | C9900074873
SO-8 | ICS570BLFT | C9900074873
SOIC-14_3.9x8.7mm_P1.27mm | 7407 | C40481
SOIC-24W_7.5x15.4mm_P1.27mm | 74FCT543A | C2863309
SOIC-8-1EP_3.9x4.9mm_P1.27mm_EP2.514x3.2mm | MP2307 | C18921
SOJ-42 | 1MX16_DRAM_SOJ-42 | C9900245332
SOJ-42 | 1MX16_DRAMJ | C9900245332
SOT-223 | LM1117-3.3 | C6186
SOT-223-3_TabPin2 | AMS1117-3.3 | C6186
SOT23-5 | 74AHCT1G04DBV | C30326
SOT23-5 | SN74AHCT1G04DBVR | C30326
TQFP-100 | XC95144XL-TQ100-10 | C45126
TQFP-100_14x14mm_P0.5mm | XC95144XL-TQ100 | C45126
TQFP-144_20x20mm_P0.5mm | XC95144XL-TQ144 | C1521137
TQFP144 | XC95288XL-TQ144-10 | C569037
TSOP-5_1.65x3.05mm_P0.95mm | BU4942 | C2067989
TSOP-II-40 | MSM514260C-60TK | C9900240804
TSOP2-54@2 | WINBOND W9825G6KH-5 | C62246
TSOP2-54@2 | WINBOND W9825G6KH-6 | C62246
TSSOP-20_4.4x6.5mm_P0.65mm | PCF8574TS | C57790
TSSOP-20_4.4x6.5mm_P0.65mm | SN74CB3T3245PW | C15298
TSSOP-48_6.1x12.5mm_P0.5mm_padLength_1mm | SN74CBTD16210 | C2674762
TSSOP56@2 | 74LVTH16543 | C2867248

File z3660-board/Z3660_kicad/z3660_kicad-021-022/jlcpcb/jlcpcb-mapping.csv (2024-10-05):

Footprint | Part Value | LCSC Part
0603-ARC-LONG | 180 | C11998
6410-04 | 22-27-2041 | C2935910
C0603 | 1uF | C15849
CP_Elec_6.3x3.9 | 22uF | C445045
CP_Elec_8x10 | 150uF/16V | C3274604
C_0603_1608Metric | 3.3nF | C1613
C_0603_1608Metric | 10nF | C57112
C_0603_1608Metric | 3.9nF | C1618
C_0603_1608Metric | 100nF | C14663
C_0805_2012Metric | 100nF | C49678
C_0805_2012Metric | 470pF | C1743
C_0805_2012Metric | 1uF | C28323
C_0805_2012Metric | 22pF | C1804
C_0805_2012Metric | 10µF | C15850
C_0805_2012Metric | 22µF | C45783
C_0805_2012Metric_Pad1.18x1.45mm_HandSolder | 100nF | C49678
C_1206_3216Metric | 10uF | C13585
C_1206_3216Metric_Pad1.33x1.80mm_HandSolder | 10uF | C13585
C_Elec_5x5.4 | 22uF | C401783
FanPinHeader_1x04_P2.54mm_Vertical | FAN 12V PWM | C240840
Fuse_1806_4516Metric_Pad1.57x1.80mm_HandSolder | Ferrite_Bead_Small | C88998
Fuse_1812_4532Metric_Pad1.30x3.40mm_HandSolder | Fuse | C516067
IDC-Header_2x07_P2.54mm_Vertical | Conn_02x07_Odd_Even | C132432
ISA-16_S | ~ | C2922447
JTAG-Header_2x05_P2.54mm_Vertical | 2x05 | C429962
LED_1206_3216Metric_Pad1.42x1.75mm_HandSolder | LED_Small | C434438
LED_1206_3216Metric_Pad1.42x1.75mm_HandSolder | LED_Small_Green | C434442
LED_1206_3216Metric_Pad1.42x1.75mm_HandSolder | LED_Small_Red | C434438
L_Bourns_SRP7028A_7.3x6.6mm | 10µH | C208101
MSOP-10_3x3mm_P0.5mm | LTC2990 | C107804
MSOP-10_3x3mm_P0.5mm | LTC 2990 | C107804
Molex_Mini-Fit_Jr_5566-24A_2x12_P4.20mm_Vertical | ATX Power | C492538
Molex_Mini-Fit_Jr_5566-24A_2x12_P4.20mm_Vertical | ATX Power (alt) | C492538
Oscillator_SMD_EuroQuartz_XO91-4Pin_7.0x5.0mm | 12MHz / 5V | C386965
PGA226 | MC68060 | C9900095602
PinHeader_1x01_P2.54mm_Vertical | /FAIL | C492400
PinHeader_1x02_P2.54mm_Vertical | TEMP1 | C358684
PinHeader_1x02_P2.54mm_Vertical | 5V | C358684
PinHeader_1x02_P2.54mm_Vertical | 12V | C358684
PinHeader_1x02_P2.54mm_Vertical | Disable_ICY | C358684
PinHeader_1x02_P2.54mm_Vertical | PS_ON | C358684
PinHeader_1x02_P2.54mm_Vertical | Jumper_2_Open | C358684
PinHeader_1x03_P2.54mm_Horizontal | Jumper_NO_Small | C722746
PinHeader_1x03_P2.54mm_Vertical | POWER_I2C1 | C7430359
PinHeader_1x03_P2.54mm_Vertical | POWER_I2C2 | C7430359
PinHeader_1x03_P2.54mm_Vertical | PWR_SW_Select | C7430359
PinHeader_1x03_P2.54mm_Vertical | Jumper_NO_Small | C429954
PinHeader_1x03_P2.54mm_Vertical | Jumper_3_Open | C429954
PinHeader_2x40_P1.27mm_Vertical | Conn_02x40_Odd_Even | C124356
PinHeader_2x40_P1.27mm_Vertical_CN3 | Conn_02x40_Odd_Even | C124356
QSOP-16_3.9x4.9mm_P0.635mm | MAX31760 | C3031567
R_0603_1608Metric | 100k | C25803
R_0603_1608Metric | 26.1k* | C23356
R_0603_1608Metric | 6.8k | C23212
R_0603_1608Metric | 10k | C25804
R_0603_1608Metric | 27.0k | C22967
R_0603_1608Metric | 27.4k | C321828
R_0603_1608Metric | 28.0k | C22989
R_0805_2012Metric | 470 (DNP w/ fixed reg) | C17710
R_0805_2012Metric | 600 (0 w/ fixed reg) | C17777
R_0805_2012Metric | 4.7k | C17673
R_0805_2012Metric | 1k | C17513
R_0805_2012Metric | 30,1k 0,1% | C2984455
R_0805_2012Metric | 10.0k 0.1% | C406725
R_0805_2012Metric | 10k | C17414
R_0805_2012Metric | 20k | C4328
R_0805_2012Metric | 330 | C17630
R_0805_2012Metric | 470 | C17710
R_0805_2012Metric_Pad1.20x1.40mm_HandSolder | 4k7 | C17673
R_0805_2012Metric_Pad1.20x1.40mm_HandSolder | 10k | C17414
R_0805_2012Metric_Pad1.20x1.40mm_HandSolder | 1k | C17513
R_0805_2012Metric_Pad1.20x1.40mm_HandSolder | 33 | C17634
R_0805_2012Metric_Pad1.20x1.40mm_HandSolder | 1k2 | C17379
R_0805_2012Metric_Pad1.20x1.40mm_HandSolder | 100 | C17408
R_0805_2012Metric_Pad1.20x1.40mm_HandSolder | 680 | C17798
R_0805_2012Metric_Pad1.20x1.40mm_HandSolder | 120 | C17437
R_0805_2012Metric_Pad1.20x1.40mm_HandSolder | 9k 0.1% | C2828721
R_0805_2012Metric_Pad1.20x1.40mm_HandSolder | 1k 0.1% | C110774
R_1206_3216Metric | 60Ohm@100Mhz | C74489
R_Array_Concave_4x0603 | 4.7k | C1980
R_Array_Concave_4x0603 | 180 | C102652
R_Array_Concave_4x0603 | 1k | C20197
R_Array_Convex_4x0603 | 1k | C20197
R_Array_Convex_4x0603 | 22 | C12008
R_Array_Convex_4x0603 | 1nF | C62856
SLOTVIDEOAGACN621 | SLOT_36 | C5173302
SLOTVIDEOAGACN622_56Pin | SLOT_54 | C5173309
SLOT_100 | ~ | C5173320
SO-14_3.9x8.65mm_P1.27mm | 74HCT32 | C6781
SOIC-14_3.9x8.7mm_P1.27mm | 7407 | C40481
SOIC-20W_7.5x12.8mm_P1.27mm | PCF8584T | C7442
SOIC-24W_7.5x15.4mm_P1.27mm | 74FCT543A | C2863309
SOIC-8-1EP_3.9x4.9mm_P1.27mm_EP2.514x3.2mm | MP2307 | C18921
SOT-223 | LD117AS33TR | C115288
SOT-23 | MMBT3904 | C20526
SOT-23-5 | VRH2851NTX | C697994
SOT-23-6 | 74LVC2G17 | C7394037
TO-252-3_TabPin2 | NCP1117-2.85/-ADJ | C233409
TQFP-144_20x20mm_P0.5mm | XC95144XL-TQ144 | C1521137
TSOP-5_1.65x3.05mm_P0.95mm | BU4942 | C2067989
TSSOP-20_4.4x6.5mm_P0.65mm | SN74CB3T3245PW | C15298
TSSOP-20_4.4x6.5mm_P0.65mm | PCF8574TS | C57790
TSSOP-8_3x3mm_P0.65mm | 74LVC1G74 | C458768
VQFP64 | XC9572XL-VQ64 | C90569

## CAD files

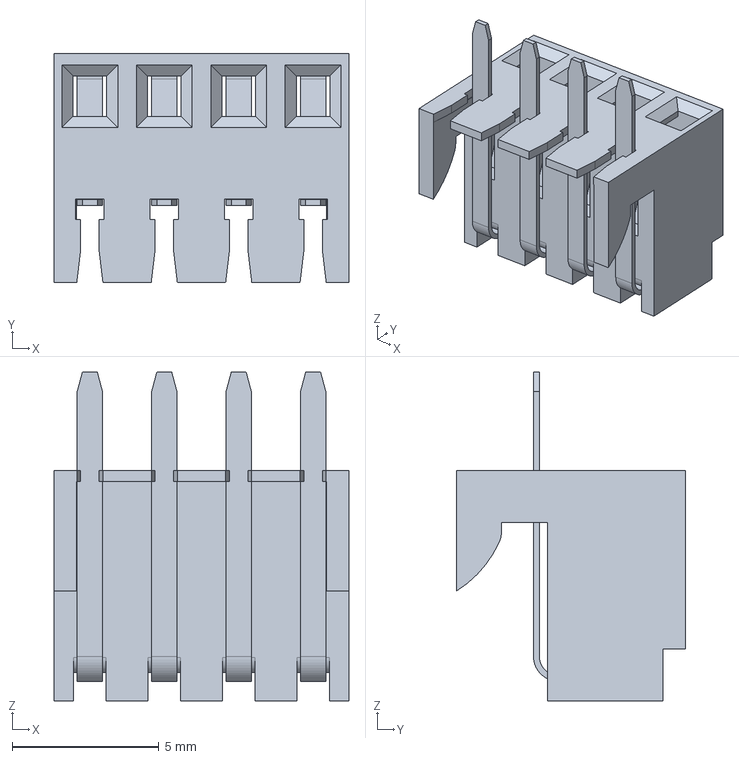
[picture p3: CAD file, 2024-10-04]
z3660-board/Z3660_CPLD_prog/22-14-2044.stp
10.1 x 7.80 x 11.2 mm

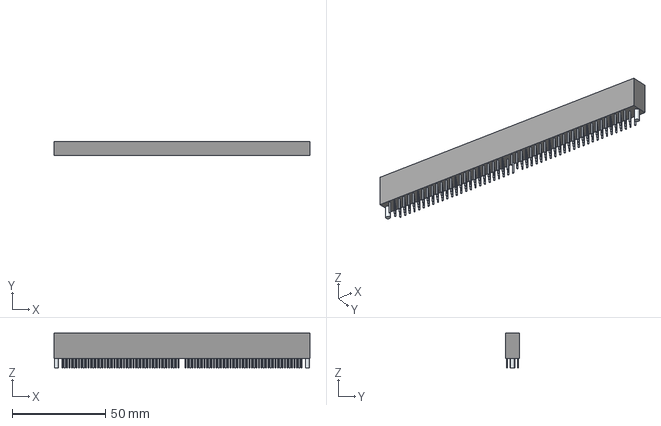
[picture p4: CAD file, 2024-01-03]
z3660-board/Z3660_kicad/z3660_kicad-021-022/8817-200-170S-F.stp
137.3 x 7.70 x 18.5 mm
Leads

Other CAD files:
z3660-board/Z3660_kicad/Z3660_kicad9-023/8817-200-170S-F.stp

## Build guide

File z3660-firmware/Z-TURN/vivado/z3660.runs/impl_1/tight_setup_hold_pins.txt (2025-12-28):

+==============================+===================+=========================================================+
| Launch Setup Clock           | Launch Hold Clock | Pin                                                     |
+==============================+===================+=========================================================+
| AXI_clk_design_1_clk_wiz_0_0 | clk_fpga_1        | design_1_i/z3660_0/inst/nTA_IOBUF_inst_i_1/D            |
| AXI_clk_design_1_clk_wiz_0_0 | clk_fpga_1        | design_1_i/z3660_0/inst/FSM_onehot_RAM_state_reg[26]/CE |
| AXI_clk_design_1_clk_wiz_0_0 | clk_fpga_1        | design_1_i/z3660_0/inst/FSM_onehot_RAM_state_reg[16]/CE |
| AXI_clk_design_1_clk_wiz_0_0 | clk_fpga_1        | design_1_i/z3660_0/inst/FSM_onehot_RAM_state_reg[29]/CE |
| AXI_clk_design_1_clk_wiz_0_0 | clk_fpga_1        | design_1_i/z3660_0/inst/FSM_onehot_RAM_state_reg[2]/CE  |
| AXI_clk_design_1_clk_wiz_0_0 | clk_fpga_1        | design_1_i/z3660_0/inst/FSM_onehot_RAM_state_reg[3]/CE  |
| AXI_clk_design_1_clk_wiz_0_0 | clk_fpga_1        | design_1_i/z3660_0/inst/FSM_onehot_RAM_state_reg[0]/CE  |
| AXI_clk_design_1_clk_wiz_0_0 | clk_fpga_1        | design_1_i/z3660_0/inst/FSM_onehot_RAM_state_reg[7]/CE  |
| AXI_clk_design_1_clk_wiz_0_0 | clk_fpga_1        | design_1_i/z3660_0/inst/FSM_onehot_RAM_state_reg[21]/CE |
| AXI_clk_design_1_clk_wiz_0_0 | clk_fpga_1        | design_1_i/z3660_0/inst/FSM_onehot_RAM_state_reg[10]/CE |
+------------------------------+-------------------+---------------------------------------------------------+

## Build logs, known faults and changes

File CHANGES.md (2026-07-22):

# Z3660 Changes

## v1.01
 * First public version

## v1.02
 * SCSI SD emulation first steps.
 * The CPLD firmware doesn't implement DMA accesses, so you can't use busmaster Zorro III boards (like the A4091).
Also A4000T and A3000(T) will not work with any SCSI attached unit.
<br>A4000T can boot, but not use the internal SCSI, if you use the A4000D kickstart.

## v1.03 beta 1
 * Fixed some troubles with 8 bit modes and miniterm 12 (copy_rect_nomask).
 * Added pre-alfa version of warp3d.library. There is too much work to be done here... but... I want to show you this... Warning: the addresses are hardcoded and you will need to have Z3 RAM enabled (autoconfigured RTG has to be at $50000000)!!!!
 * I2C measures are now controlled by a state machine. If I2C get stuck, then I2c measures are stopped (and don't affect to general behavior...).
 * Added new commands to console, so you can increment or decrement some "adjustment parameters" like EMU read/write delays, and ethernet nag delay.
 * ZTop app adjustments for different fonts. And now shows the Beta version.
 * As RTG driver has changed, you need to delete your devs:Picasso96Settings and start again with p96prefs... 
 * SCSI stability fixes<br>
 * The kickstart load has been changed in z3660cfg.txt. You firstly declare upto 9 different kickstarts, and finaly you select one of them using a index. Now you can change between kickstarts in Ztop application.
 * Also, it has been implemented the extended kistart load, in the same way than current kickstarts (they load at $00F00000).
 * The reset behavor has also changed:
<br> 1. If you maintain the reset for 4 seconds, then the CPU will cycle between 060, Musashi, UAE and UAEJIT. 
<br> 2. But if you maintain the reset for 8 seconds, then all env files will be deleted (the configuration used will be what you declared in z3660cfg.txt file as default).

## v1.03 beta 2
 * New config variable "enable_test". You can force a intensive test to CHIP RAM from ARM bus. This will be useful for testing purposes.
 * Update system. After turning on your Amiga, you can press 'C' in the Amiga keyboard to access to a BOOT.bin update system. It is not silly-proof, so don't expect now too much info for now. The sequence of keys you should press should be: 'C', 'I', 'U', 'R'. That is: enable 'C'onsole on HDMI, connect to 'I'nternet, 'U'pdate the Z3660.bin file, and finally 'R'eboot the system. Please wait until some message appears into the HDMI screen... It can take up to 20 seconds for some timeout (USB serial console shows more info).
Now BOOT.bin will search for the file Z3660.bin to boot from it (instead of BOOT.bin). If Z3660.bin is not correct, damaged or has something wrong, then BOOT.bin should continue to boot from itself. So, this should be somehow secure... but please take in mind that I have tried this only for two days...
For this you will need the new CPLD firmware, if you don't update it, then 060 will not boot because in the previous firmware the SNOOP signal was not activated when ARM makes bus accesses...
I think I haven't to say it but... obviously, you will need to connect an ethernet cable to the z-turn...
 * From serial console, you can select different phase for clocks. The setting can't be stored, this is only for my own tests.
 * Warp3D working in 060 and EMU, you will need the Wazp3D-Prefs and set Renderer to "Soft to Bitmap"

## v1.03 beta 3
 * SCSI SD emulation had two main issues.
<br> 1. The first one was that when copying a lot of data sometines the change between units was no applied, so the destination hdf had a bad write to a unknown block sector... this made the hdf corruption.
<br> 2. The second issue was a bug in the relocation of the filesystems. Even with the fixed code, I had a partition that was not working. When I debugged the problem I could see that the loaded filesystem had a bigger size than it should. It had in the hdf two repeated blocks. When I deleted the filesystem and back to write it (using FSUAE), then the problem went away. So be careful with the filesystems. Corrupted filesystems can't be repaired easily and posibly will make something wrong with the SD...
Finally, I have working and booting several hdf and partitions with PFS3
 * Warp3D should work now with and without Zorro3 RAM. It had some addreses hardcoded in beta 2, now all addresses are calculated in the system boot.
 * I have been working on the reset of 060 and ARM (I always reseted the ARM when Amiga was reseted, and this made that "Boot with no Startup-Sequence" didn't work). Now the reset of ARM is not attached to the reset of the Amiga, but sometimes the ARM doesn't reinit the Amiga autoconfig (that is done in FPGA when using the 060. EMU is not affected) so sometimes you will not see the SCSI, Z3 RAM and RTG boards... WIP...

## v1.03 beta 4
 * Ethernet driver got statistics and then apps like netmon now shows info about your network (thanks to @Stefan R )
 * New Boot screen showing a new logo, and info about version and options loaded. You need a new folder named images in exFAT partition.
 * RTG now has different MMU configurations in its different memory zones. So, the cache activity of the ARM RAM is not seen as RTG glitches, but without loosing the acceleration of the cache.
 
## v1.03 beta 5
 * Ethernet address can be selected from z3660_cfg.fiile. But lwip (BOOT.BIN update tool) refuses the new values, I'm still investigating it...
 * Ethernet amiga driver is now compiled with gcc. Thanks to @Stefan R
 * As the ARM code has been growing a lot, and I needed some more state machines. So I have been translating almost all switch case structures to the pt_thread library
 * Restored the initialization of the LTC chip, so now all analog measures are done.
 * Added to the ARM boot, the ZTop app (you need to press 'Z' after power ON). It seems an Amiga app, but it is not... :)
 * Added an icon to the ZTop app, that has the look of the Z3660 logo. 

## v1.03 beta 6
 * [EMU] Restored mother board RAM access
 * [EMU] Defaulting bank adresses with no RAM zones to invalid zones
 * [ZTOP ARM] Fix all resolutions (only 800x600 was tested before). 

## v1.03 beta 7
 * Restored Mother Board RAM access on EMU.
 * Added to env and Ztop ARM the configuration of MAC address in a new tab. (Amiga ZTop hasn't this new tab).
 * Slightly modified the ethernet driver (Amiga and ARM), with double space for incoming frames, and some fix so it seems that it doesn't stops suddenly
 * Added some more video modes (1280x800, 1920x1200 not tested, 1600x900 and 1680x1050). Added a p96 configuration file "p96-z3660-hdmi". Monitor file points to this file in devs:
 * Reworked the IPL read interrupt (it could interfere with other read/writes to other ARM registers). 

## v1.03 beta 8
 * Added more video resolutions 1280x800 1920x1200 1600x900 1680x1050
 * CPU frequency is now selectable between 50 and 100 MHz in 5 MHz steps. (Please report, as I only tested all frequencies on AA3000 and mobo SCSI)

## v1.03 beta 9
 * Added MHI support to OGG and FLAC files (using miniaudio library). AmigaAMP needs 1/2secs of buffer to play ogg files. Also ogg files are fully scanned so they are delayed when startinng playing (probably MHI or AmigaAMP issue)
 * Added a patch to the httpclient autoupdate code (thanks to @apolkosnik ). Under test. 

## v1.03 beta 10
 * Now the RTG autoconfig has two options (selected by a new checkbox in ZTop's Boot tab):
    Option 1 checkbox "AUTOC RTG enabled" checked. This configuration is as it was before this beta 10 (RTG is mapped first, before any autoconfig board, )
    Option 2 checkbox "AUTOC RTG enabled" NOT checked. This will make RTG to appear at $10000000, but it will not make z3660 scsi bootable. For making z3660 scsi bootable, you will need the ext rom kick060_scsi.rom. This will create a tiny Zorro II board of 64 kB, and it will make the z3660 scsi bootable.
 * Hopefully update system from "ARM console" (press 'C' after power on your Amiga) will work finally after beta 10... (thanks to @apolkosnik )

## v1.03 beta 11
 * Fix in the scsi refresh (used when resetting with 060, it shouldn't throw more ARM Data Aborts)
 * Beeper simulates SCSI activity sound. Configurable with ARM Ztop (Amiga Ztop still under development)
 * Changed the timing constraints in the FPGA. Please report your working CPU/EMU bus frequencies.
 * Env files will be replaced by Presets files (only for ARM Ztop). Please see my 4 preset examples I have included in the exFAT_files_and_folders.zip file.
 * Musashi should work again. 
 * I'm still investigating some weird reset made by UAEJIT Emulator (It tries to access to the address 0x6f043004, but in my system in that space, there is nothing. After the reboot, it works fine, so I suspect something about ARM CACHE). 

## v1.03 beta 12
 * A new hardware version (0.22) has been developed. It contains a cpld programmer using the ARM via I2C. For those with 0.21x there is a small PCB that uses two jumpers JP2 and JP1 as I2C pins.
 * A new preset has been added to ARM ZTop for using the z3660cfd.txt file as default.
 * SCSI emulation has been improved so it can make accessible a SD partition to the Amiga. As other systems make (pistorm/WinUAE/...) it will mount 0x76 partitions as a LUN. Normally, now you will have a BOOT FAT partition, hdfs in an exFAT partition, and now a new 0x76 partition. Then the SD will have 3 partitions, the last one will be mounted as SCSI unit 2 LUN 1 (internally unit number 12)
WARNING: make backup of your SDs, I have seen that the bug that makes hdfs to grow is back... 

## v1.03 beta 13
 * Reworked the CPLD programmer for v021x hardware with a tiny delay between I2C transitions.
 * CPLD programmer support for 0.v22 hardware
 * SCSI SD emulation now renames the hdfs/sd partition names if they exists previously in the system (for example from scsi.device).
 * Fix in Ethernet buffers so now it will be faster when receiving data.

## v1.03 beta 14
 * FIX: SCSI SD emulation now doesn't make the hdfs to grow up...
 * Added to ZTop for Amiga the tabs MISC and PRESET. (The mac address still CAN'T be modified, it will in a new version).
 * Added to ZTop (both ARM and Amiga) a button to delete the selected preset (it will delete the current selected preset, reboot the machine and select the default preset).
 * Temporarily fixed a bug in the EMU write words, that make CLUT video modes (8 bit, 256 colors) to not see some icons (for example in WBDOCK2). It is not fixed really, what I do is not use UAE direct access from JIT for writing words (16 bit). It makes this accesses slower. This will be in this way until I discover a JIT compiler solution for this... 

## v1.03 beta 15
 * Fix in xcs3prog (cpld programmer): more time to have more compatibility with different Amiga models. Better CPLD version identification.
 * New: Scsi emulation now can read hybrid MBR+RDB SDs (you now can use the same SD with z3660, with emu68 and winUAE)
 @Crumb instructions:<br>
 "I have installed emu68 on a hybrid MBR+RDB SDHC card and it works nicely. The steps were:<br>
-create 3 MBR partitions: first partition space will be used for native amiga rdb partitions space so make It big. second one must be fat32 and small (e.g. 200MB), It will store z3660 boot.bin (and emu68k files). The third one will keep z3660 data partition (config, hardfiles...)<br>
-delete de first one (It Will be the space used by our amiga partitions)<br>
-download from aminet hdinsttools<br>
On Amiga side:<br>
-set RDBLOW=2 in hdinsttools tooltypes<br>
-create a bootable WB partition at the beginning (I would create a second one with lower priority as a system backup, work partitions...).<br>
-create a work partition or the ones you want but remember to avoid reaching the point where the mbr partitions begin, so leave space at the end (the fat32 size + data partition size and some megabytes as safety net) for example 250MB.<br>
-remember that hdinsttools adds some zeros at the end of maxtransfer so remember to change maxtransfer with hdtoolbox if you plan to share the sdcard with other amigas.<br>
-format the WB partition and install your favourite OS<br>
-Add sd.unit0=rw to emu68 as parameter to be able to write<br>
-Enjoy :-)"<br>
 * ZTop update (both Amiga and ARM): now you can choose to mount ROOT of the SD (MBR+RDB partition) and/or 0x76 partitions. <br>

## v1.03 beta 16
 * SD configurable frequency. AFAIK the Xilinx driver only uses two main frequencies: 25 and 50 MHz. This is configurable only from z3660cfg.txt and has only two options: you have to write a new line with "sd_clock 50" or "sd_clock 25" without quotes. Obviouosly, at 25 MHz the SD access will be slower, but maybe it will work with longer extension wires...
 * SD direct driver (for 0x76 or root partitions) had a maximum limit of data written at once that made read errors. It could be bypassed by setting a lower value in maxtransfer (as the typical value 0x1fe00). Now is fixed a the long writes are made in shorter writes as needed.
 * Doubled sprite cursor or high res cursor, was not totally managed by the hw_srpite function (from ZZ9000) and now the amiga monitor driver and RTG support double and hi res cursors.
 * Monitor switch partially implemented (as you will need the SwitchControl utility in your startup-sequence). In Ztop (only ARM for now) you can select to manage CTS and/or SEL signals, in order to make visible the RTG at boot time. One of these signals can be used with Ratte monitor switch, or one of those cheap HDMI switches modified to accept CTS or SEL signals. Also you can configure the active level of these signals (so virtually you can use any switcher).
 * UAE JIT. While trying to get Amiberry 7 CPU emulation, I have seen that some JIT instructions are not completely emulated. Mainly they are MUL and DIV instructions. I have deactivated them and demos like StateOfTheArt polygons are correct. Also this affected to Shapeshifter text backgrounds (yeah... why is macos using MUL and DIV for the text background???). Also the "jumping" cursor was because ADDX and SUBX instructions are also wrong... The bad thing is that emulation is a bit slower, but more compatible. Also, there was a fix in Amiberry regarding to some FPU operations to unaligned acesses that are fixed. Please report experiencies with JIT emulator. 
	
## v1.03 beta 17
 * A new way to program the CPLD by pressing SW1 on the Zturn board: press the button marked as "USR" after boot, or within the two seconds that boot screen is showed over the HDMI output).
 * Enabled all partitions to Amiga side (now you can mount the first FAT partition. These partitions will start on scsi unit 11. Exfat can't be mounted as we don't have any driver for it (WIP) :) )
 * Monitor switch fully implemented (SwitchControl is not necessary). Please take note that when updating the CPLD the Amiga is reseted and then, the monitor switch will not switch correctly. Wait 5 minutes and then power cycle your Amiga.
 * RTG: some gfx miniterms fixed.
 * Updated miniaudio to version v0.11.22 (AHI/MHI mp3, ogg, flac player)
 * Test Amiga regions on ARM boot. You can select different test zones in the z3660cfg.txt file:<br><br>
```
# Select Test Amiga ranges (test_range0 to test_range7)<br>
# First number is the start in hexadecimal format<br>
# Second number is the length finished with KB or MB (without space, minium unit 1KB)<br>
# Third string is an optional name<br>
test_range0 0x0 2048KB "Chip RAM"<br>
test_range1 0x07800000 8MB "Mother Board RAM"<br>
test_range2 0x08000000 128MB "Cpu Board RAM"<br>
```
<br>
 * Fixed some EMU opcodes: MOVES and MVMLE. I'm using cputest from WINUAE. The emulation will be slower than before as I disabled some "suspicious" opcodes.

## v1.03 beta 18
 * Timings are all redone. 060 and CPLD clocks are now decoupled, so when you run an EMU at 100MHz, the 060 is clocked at 50 MHz (or less). For this, I have used some other pins for the clocks, so the previous timing is not valid anymore.<br>
You will need a new CPLD firmware (1.03 BETA 18). And also you will need a new folder in your SD, that contains all the timings. What I have seen is that the timing is system dependent so I have included two files, one for each machine I have.
 * The update system have been updated and now accepts https connections, so after this version you will update from GitHub instead of my NAS server. For emergencies, you can still update from my NAS, changing the server with 'S' in the update console.
 
## v1.03 beta 19
 * Added a system to detect wrongly configured jumpers in the mother board. The detection system is very simple: before the FPGA generates CPUCLK and CLK90, those signals are measured as inputs. If a clock is detected on those pins (mother board jumpers set to INT) then the ARM doesn't apply the clocks to CPUCLK and CLK90 and stops showing a message in HDMI. Probably in next version the buzzer will be used to alarm to the user.
 * As a consequence of the jumper detection, CPUCLK and CLK90 are applied with a three-state buffer, and the timings of both signals will be different from beta 18. So, it is expected that you should subtract around 20 degrees to your previous CPUCLK and CLK90 phase values.
 * Inspired in what pistorm/emu68 did before, with a double buffer for writing to the Amiga side, I have included a new scheme: a write pipeline to the EMU so in this version, write speed is the maximum it can be in an A4000 (bustest 7 MB/s). Reads are different, they can't be buffered (you have to wait to the read to finish, before launching a new read/write), even you can see slightly lower values in bustest reads.
 * RTG can now generate any video mode from p96prefs. All parameters are adjustable, but with restrictions. Video modes below 640x400 are fixed to 320x200, 320x240 and 320x256. These modes are scandoubled and with a sync of 800x600 (not configurable). Another restriction comes from big video modes (for example 1600x1200). These modes work perfectly at 8 or 16 bit and 60 Hz, but 32 bit video mode is limited to 30 Hz. In this specific case, as Zturn can't show more than 16 bit video, is not really a problem.
As video modes have changed, first time you boot your Amiga with the new drivers/settings, you will not have RTG. Select your new video mode with Prefs/ScreenMode.
 * Added to the console a TFTP server. Please take into account that this is not a FTP server, but a TFTP that is a more much limited server. Enough to download/upload some file from to the SD (using a TFTP client in your PC). You will need the USB serial debug to see the contents of the SD folders.
 * ZTop has a new Timings tab. Here you can edit the timings selected for your machine. Remember that you need a "timings" folder in your exFAT partition of the SD, containing a "timings.txt" file that points to your timings file. Now this file can be managed from ZTop app. You don't get any advice in the ZTop app, but you NEED to click on Apply Timings button to save your timings file. If you click on "Apply All" your timings will NOT be saved.
In this tab you can select the timing frequency you are editing, and the first Clock you see is the Clock Base, calculated as 200 MHz x MUL / DIV, being MUL and DIV two adjustable parameters. Correct values of this clock base is from 800 MHz to 1600 MHz. This frequency is the base clock for the generated clocks (pclk, clken, bclk, cpuclk and clk90).
Each generated clock has two parameters: phase and divider. The generated clock frequency is calculated as Clock Base / DIV2, being DIV2 the divider of each clock.
You should always generate cpuclk and clk90 as 25 MHz or less (to not overclock your Amiga)
bclk is the CPLD clk and works better by design when its frequency is x4 cpuclk.
pclk is the 060 clock, and clken should be always 1/2 of pclk.<br>
How to adjust phases: try to modify only one value, and see if your Amiga boots. Normally pclk should be some negative value, and clken should be +90 from pclk phase.
bclk is generated to clock the CPLD, should be 0, but sometimes it needs to be positive, sometimes negative.
cpuclk is the Amiga clock, but CPLD receive a delayed version of it. It should be 180 degrees, but normally we need a higher value. (If you come from beta 18, probably you need to subtract about 20 degrees to this value).
clk90, as its name says, is a clock 90 degrees delayed from cpuclk, it can be +90, but if you measure it with an oscilloscope you see that it needs to be +100.
And finally emu_extra. This value can be modified in the future (probably not to be used because it should be 0). There are differences in the read/write timings if you compare the EMU to the real 060, and seems that this value helps to make EMU to work at some frequencies (anyway, I always recommend to run EMU with 100 MHz of timing frequency as this maximize the read/write speed to chip).
 * USB serial debug can be used on console update and ZTop ARM as keyboard and mouse. Mouse is emulated with terminal cursor keys, and the mouse left click is emulated with the space key
 
 ## v1.03 beta 20
 
 * Beta 20 CPLD returns to beta 12 timings. This means that 060 will be clocked with the PCLK clock that you select on timings, the mother board is clocked at BCLK clock, and the CPLD is clocked at BCLK instead of CLK_RECEIVED (received back from the mother board).
So you will need to update the timing files manually at the same time than the BOOT.BIN (remember to remove FAILSAFE.BIN and Z3660.BIN files).<br>
YES, you have read correctly, you should copy the files manually, because your machine will not boot, and even respond to your keyboard, if you update the BOOT.BIN and use your previous timing files.
The timing files are the default timings used in my machines (A4000CR and AA3000+), and after you update to beta 20 version, you can modify the timings as in beta 19, but if something goes wrong you can reset to the default values (they are saved in the BOOT.BIN) using the console 'C' and then 'G'.
 * USB: there is a new USB driver ported from the new @MiDWaN's ZZ9000 versions. You have to install poseidon stack and use the driver provided in the adf file. For now, it is only working when using the EMU.
 * MPEG: there is a builtin decoder (pl_mpeg.h library) than can decode mpeg 1 files (with mpeg 2 audio). In the c drawer of the adf you have a cli command called mpeg_streamer that feeds the mpeg data to the pl_mpeg.h library. It is also working with EMU, and it has some troubles with the memory managements (it hangs the Amiga after one or two videos). It uses a new PIP feature implemented on the FPGA, so it can be used in 8 bit, 16 bit and 32 bit modes (internally, it uses 32 bit (16 bit limited by the zturn HDMI hardware)).<br>
  The MPEG player supports playback of MPEG files at 640x480 resolution but struggles with high bitrates.<br>
 * Mother Board CPU: a new feature for the big Amigas with 030 installed on their mother board. It needs a small wire patch to the current hardware version: remove the R13 resistor and add a wire from DBG3 pin to one of the R13 pads:
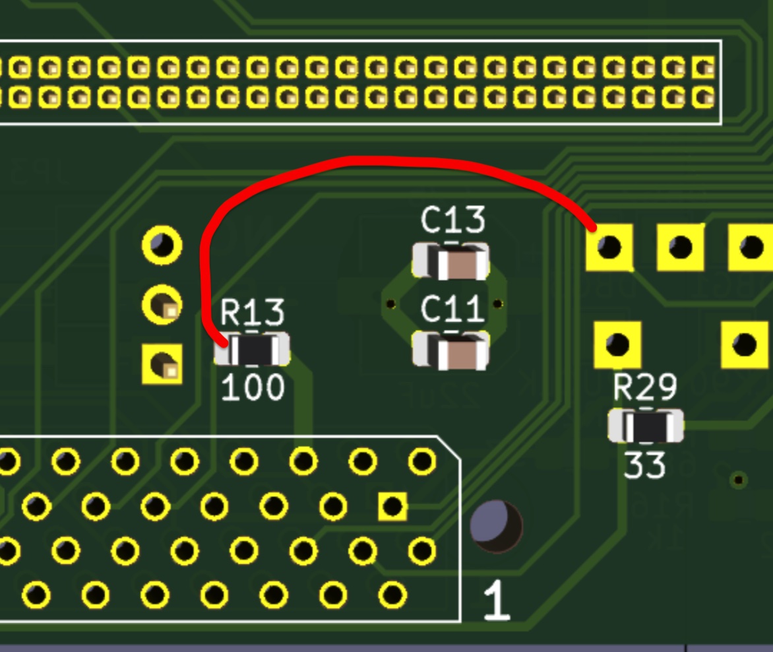
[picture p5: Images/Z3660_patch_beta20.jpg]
<br><p style="text-align:center;"><br>Z3660 patch wire to use the mother board 030</br></p>
<br>
In the Ztop app you can choose now "Mother Board CPU". The 060 and the EMU will not be used, and the 030 of the mother board will take the control of the Amiga. But the CPU RAM (128 Mbytes) will be available to the 030. Here, I discovered a hardware problem in my AA3000+ the high data bus (D31-D16). There are some READ errors on these bits.<br>
But it is working perfectly on my A4000CR that have a 030 at 25 MHz. Please notify me if your AA3000 works correctly.<br>
The RAM will be autoconfigured but the RTG (and AHI, MHI, ETH, SCSI, etc) will not. This is because the z3660 is not in the autoconfig chain (when you use 060 and EMU the FPGA intercepts the autoconfig calls and autoconfig the RTG, buut when using the 030 we don't control anything...).<br>
Then, can we use the RTG with the 030? Yes, we can with a small utility called z3660_autoconfig (see the adf), that has to be run in your S:Startup-Sequence before the LoadMonDrvs command line. Can I use AHI, MHI, SCSI, etc? No, until I can modify the drivers to support this special mode. Anyway, we don't expect any increase of speed... we are using really a 25 MHz 030... with a lot of RAM and RTG, but still a 25MHz 030.<br>
Also, @kavanoz has been modifying the board and he has now a new version that has this mod included ,and also he moved the zturn some more millimeters to the right.<br>
 * Update system: ethernet connection is now faster and more efficient (ARM caches are now enabled), so for the next versions, we will have a faster update system.
 * ARM speed. Almost all Zturn version I have seen, they have installed a rev 3 Z7020 chip. The Vivado project defaulted the speed to rev 1 that is 667 MHz. Rev 3 silicon versions can run 867 MHz nominal. But... in all my zturn's the ARM can be clocked at 1100 MHz !!!!! I have to say that I always used a small fan over the Z7020 chip. Now in the ZTop ARM app, you can choose the ARM speed (from 667 to 1300 MHz. I know that others zturn can be clocked at 1133 MHz, but I don't know the limit). Running at 1100 MHz and EMU gives 230 MIPS in sysinfo !!!! Games like Diablo or Settlers2 are now perfectly playable!!! In the other hand, I have been reported that Darkforces runs abnormally slow (like 15 FPS) and seems to be a common problem with ZZ9000 and Z3660 RTGs
 
 ## v1.03 beta 21
 
 * USB: Now it is working when using the EMUs and the 060.<br>
 * MPEG: Now it is also working with the EMUs and the 060. It has been optimized with some ARM NEON/SIMD instruction so now it can play files at 800x600 resolution (but struggles with high bitrates).<br>
 * ADF mount support. An adf floppy emulator has been added (adfs are not available at boot time yet. I need a proper ROM to do this).<br>
 * SCSI ISO support. In z3660cfg.txt file isoX can replace hdfX for ISO CDROM emulation.<br>
 * SD card file manager (DIR/COPY/REN/DEL/MKDIR/CRC/FREE) by @Jusii.<br>
 * Replaced TFTP server by a httpd server (WIP).<br>

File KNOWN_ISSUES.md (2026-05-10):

# Z3660 Known Issues / Limitations

##Clock configuration
 * upto v1.02 CPLD and FPGA/ARM versions<br>
The frequency of 060 is limited to 50 and 100 MHz.
<br>When using EMU (MUSASHI, UAE or UAEJIT) then the 060 frequency affects to the emulation chip speed access. So the maximum chip speed is reached when clocking the system at 100 MHz (060 receives the same clock).
<br>

* v1.03 beta 4 and later FPGA/ARM versions<br>
The frequency of the 060 can be selected between 50 and 100 MHz, in 5 Mhz steps. 90 MHz and 95 MHz are a bit unstable on my systems (A4000 and AA3000). All other frequencies seems to work fine (again, on my systems).

* v1.03 beta 18 and later FPGA/ARM versions
The 060 frequency and the CPLD frequency are noe decoupled, so when using an EMU, the 060 will get 50 MHz or less.

##SCSI SD emulation
 * v1.01 CPLD and FPGA/ARM versions<br>
There is a bug in hunk relocation code that makes that one hdf grows upto fill the SD. Please don't use this version of firmware with SCSI SD emulation.
 <br><br>
 * v1.02 CPLD and FPGA/ARM versions<br>
 1) Copying data between partitions of different hdf files, will result in an unformatted partition and all data will be lost (on the written partition).
<br> Copying data between partitions on the same hdf file, doesn't seem to be affected by this issue.
<br>
 2) The only working filesystem is FFS (DOSx identifiers). Others are not working due a bug in hunk relocation code.
<br><br>
 * v1.03 beta 4 FPGA/ARM versions<br>
 The issues in v1.02 has been fixed. You can copy between partitions and use any filesystems.
 But still please use with caution, make always a backup of your files...
<br><br>
 * v1.03 beta 14 FPGA/ARM versions<br>
 After beta 14, you can make a third partition in the SD with type 0x76 (like you do with pistorm/emu68). It will be automounted by the SCSI SD emulation. (beta 12 and beta 13 had a bug that made some hdfs to grow up, and it was fixed in beta 14).
 
##DMA and Zorro III bus bastmer
 * v1.02 CPLD and FPGA/ARM versions<br>
The CPLD firmware doesn't implement DMA accesses, so you can't use busmaster Zorro III boards (like the A4091).
Also A4000T and A3000(T) will not work with any SCSI attached unit.
<br>A4000T can boot, but not use the internal SCSI, if you use the A4000D kickstart.
<br><br>
 * v1.03 beta 2 CPLD and FPGA/ARM versions<br>
The CPLD firmware implement DMA accesses, but EMU has not been implemented yet. So you can use DMA boards only with a 060 CPU.

##Mpeg player and USB only usable with EMU
 * v1.03 Beta 20<br>
 Starting this beta 20 version, we have a mpeg library in the ARM (pl_mpeg.h) and a PIP system to decode and play mpeg 1 files in RTG modes. (See pl_mpeg.h for file limitations). The driver needs to be adapted to apply cache coherency between 060 and ARM system.<br>
 The same applies to USB: the driver needs to apply cache coherency.<br>

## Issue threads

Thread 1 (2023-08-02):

Suggestion for next hardware iteration

tkurbad, 2023-08-02:
Hi @shanshe,

First of all, thank you very much for this cool project!

I ordered some PCBs and two of the Z-Turn boards yesterday. I will report back on how everything goes. I'm curious how this will perform in comparison to the BFG 9060. ;-)

I have a suggestion for the next PCB iteration: Would it be possible to place the headers for the Z-Turn module closer to the 68060's socket? This opens up the possibility of putting the card in an A3000.

Thank you, and best regards
Torsten

shanshe, 2023-08-02:
Hi @tkurbad,

Right now, BFG 9060 has superior performance on RAM data transfers. BFG 9060 uses every 060's clock cycle to talk with the DRAM (through a DRAM controller implemented on the big CPLD).

Z3660 uses 1 of each 2 clock cycles to talk directly to a state machine on the FPGA, and FPGA talks with ARMs RAM through an AXI interface. This process has a relatively high initial latency, but it can serve burst of data at 200MHz. So right now, Z3660 has a slower RAM, but it will go faster when I can use every single 060 clock cycle. (It needs more debugging on FPGA, but due to the latency it will never go as fast as BFG, maybe close, but always slower).

But... although it is slower, we are talking about 50 MB/s right now (with the 060 at 100 MHz, and the bus at 50MHz). The best Z3 RTG board can support data transfers about 13 MB/s (limited by buster and other logic). So with Z3660 you get a very fast RTG, as it uses the same fast path (it is like a very fast ZZ9000).

Thanks for the suggestion but I think that even moving the headers, I think there is no space, since Z-Turn grows a lot upwards. I don't have a A3000 to test... so... could you be the first one to test it? :)
Also, 060 is very close to ethernet and HDMI connectors, so we can't move the headers so much...

I think that the evolution of this Z3660 v021 should be using the same CPU module that ZZ9000 uses (not as tall as Z-turn), but then we have to add ethernet, HDMI, SD, USB etc headers to the main board... hummm... it reminds me to the Warp 4060!!!

Thank you, and please read the schematics carefully, there are some options to choose from. Ask me please...
My boards are also in transit. I'll take some photos and will post a build guide here on the wiki.
The first thing you should pay close attention to, is the ultra-tiny resistor packs... Even when you see them soldered (using a microscope)... maybe they're not!!!... So you should test for continuity with a continuity tester... (from PCB pad to terminal of the resistor).

Best regards,
shanshe

tkurbad, 2023-08-03:
Thank you for replying so quickly.

Yes, I can see the problem with the connector placement on the Z-turn board vs. the 060 socket.

What I really like about your project is that you don't try to reinvent the wheel. The A3660 and the ZZ9000 are well tested by now, and the ZZ9000 drivers and software are getting mature over time.

I also like that you develop everything so openly and even chose GPL3 as your license. Being a Linux user for decades, I can totally relate to that.

I also like the idea of using the same Zynq module as the ZZ9000. This will be to the mutual benefit of both projects. Don't know how short the supply of those is, though.

Regarding the connectors: How about placing FCP connectors? There are already several solutions using those, e.g. the Pistorm32 lite for CM4. If you choose the right pinout you can stay compatible to all those Chinese breakout boards thar convert FCP back to HDMI, USB and whatnot. This would also reduce the height of the card assembly significantly and make it even more A3000 friendly...

Just a thought. ;)

Btw., I'm no stranger to soldering. You've probably seen me as torsti76 on various Amiga forums...

shanshe, 2023-08-04:
> What I really like about your project is that you don't try to reinvent the wheel. The A3660 and the ZZ9000 are well tested by now, and the ZZ9000 drivers and software are getting mature over time.

Thanks for your comments. One of the reasons that made me to start this project was to use the know-how I acquired when working with ZZ9000 software. I never used Vivado before that, and Lukas explained me a lot of things. Another source of inspiration was _Bnu. He did a lot of work on graphics functions of ZZ9000. Then we moved to Pistorm... another good source of inspiration hehehe. So yes, all is yet invented, we need "only" to solve this big puzzle...
My first attempt was to add some RAM to the A3660. But someone in another project told me... I can send addresses and data from the FPGA to the Amiga... hummm... I tried it and Musashi cpu emulation worked after some days. Then, I saw Amiberry cpu code for ARM7... and so on...

> Regarding the connectors: How about placing FCP connectors? There are already several solutions using those, e.g. the Pistorm32 lite for CM4. If you choose the right pinout you can stay compatible to all those Chinese breakout boards thar convert FCP back to HDMI, USB and whatnot. This would also reduce the height of the card assembly significantly and make it even more A3000 friendly...
>
> Just a thought. ;)

That's a fantastic idea!!!

> Btw., I'm no stranger to soldering. You've probably seen me as torsti76 on various Amiga forums...

Oh, ok. Then your feedback on PCB building will be highly appreciated!!!

tkurbad, 2023-08-10:
My PCBs arrived today. Looking good! Before I can start building the first sample, we'll have our family vacation. Assembly will start at the beginning of September.

shanshe, 2023-08-13:
I have built one prototype. All working and fine, except C27, there is no space for this electrolytic capacitor. But we have enough capacitors in the board, hahaha.

ottifant011, 2023-11-05:
Good day,

Thank you very much for this great project.
I finished soldering my card yesterday except for the resistor networks. Everything is easy to solder :).
The commissioning was a bit bumpy. At the beginning it had a 68060 Rev1 on it. Of course it didn't work because the clock rate is 100MHz. After swapping it to a 68060 Rev6, that also worked.
CPU emulation worked straight away, graphics part also works and Fastram is also integrated.
Network not yet tested, what doesn't work yet is the SCSI emulation, I have set up an HDF file with Winuae and formatted everything, but the image is integrated as soon as you access it, there are bad sectors.
A setup with the HDToolbox is also not successful, it acts as if the config is saving but when it is opened again everything is empty again.
I think I'm doing something wrong, maybe it's possible to provide an empty hdf file.
File system used FFS with Amigaos 3.2.2.1
What I also noticed is that if you do a reset several times you switch between the emulations and the real CPU.
How do you connect the AX sound module?

Is there a forum where you can find out more about this map or a Discord channel?

Thanks and keep it up

Can we also support you through a donation?

Many greetings from German
Klaus
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
ottifant011, 2023-11-21:
sorry, you misunderstood me, I didn't mean your part from the SD to SCSi, but the onboard SCSI from the Amiga3000D

shanshe, 2023-11-21:
Ah ok, sorry... So, finally I think that I will need some A3000 to test it... Someone from here (Spain) told me about to send me one to test... but he is a bit far from my home, and I don't want to damage an A3000 with a shipment... hehehe
The alternative is that one that has an A3000 can measure some signal from the bus with a cheap logic analyzer... or even measure it with the FPGA... hummm that would be very interesting... it would be like transform to the Amiga into a logic analyzer hehehe

ottifant011, 2023-11-22:
Hi, a general question: how is the jumper on the mainboard internal or external?

shanshe, 2023-11-22:
> Hi, a general question: how is the jumper on the mainboard internal or external?

External, like A3660.

ottifant011, 2023-12-21:
@shanshe Hi, could you please send an email to ottifant011@gmx.de

TurricanA1200, 2023-12-25:
Good day

I also wanted to get in touch about the great card.

I built two of them and so far I'm thrilled with how stable the card works in this stadium.

I tested the z3660 on my TX1.1 and found that the Zorro3 doesn't work (yet).
Yesterday I wanted to test the RAM and removed it from the TX and had different RAM areas in the system, sometimes 1152MB sometimes 1280MB. But if the onboard RAM is on the TX then the RAM is correct again with 256MB Z3 and 256MB TK RAM.

MFG Daniel

PS:  Sorry for making another post :))
      Is my first message in Github.

shanshe, 2023-12-25:
Hi everyone ( @TurricanA1200 @tkurbad @exocyt0sis @ottifant011 )

If you want we can talk here about Z3660: https://discord.com/invite/EQUTeMb8

I know that today (dec 25th) is not a good day for talking about our hobbies, it's a day for the family... But tomorrow I'm ready to get back to the Z3660 development (at least a week of fun!!!)

shanshe, 2024-01-31:
No, it is nothing about A3000. Nor BFG 9060... do you mean z3660, right?
Well I don't have an A3000, and even I don't have a BFG 9060... but maybe one day... hehehe
This update is about SCSI emulation that is made inside one ARM, the same one that read/write to the SD.
There were some problems (I forgot to enable LBA, and 64 bit) with fatfs library, but the worse part was the filesystem hunk reload from the z3660_scsi.rom. That part (that is a copy from pistorm-musashi) doesn't work properly in the Zturn ARMs, and was making to grow the first hdf you use (fillinng up the SD, and corrupting your hdf files...).
So, I have push those fixes, becuase the systems that we are testing, now are working correctly (mostly A4000 TX and CR from Hese).

exocyt0sis, 2024-02-01:
> No, it is nothing about A3000. Nor BFG 9060... do you mean z3660, right? Well I don't have an A3000, and even I don't have a BFG 9060... but maybe one day... hehehe

So sorry - you are absolutely right. I was so focused on the BFG 9060 I forgot what this Github repository is all about 🤦 . That being said, please excuse me and let me rephrase the question/statement:

The BFG9060 isn't ideal for the Amiga 3000. From what I've read about it so far, it seems to make the system really unstable. The ZZ9000 hasn't really delivered either, unfortunately. For that reason, I hope the Z3660 will be the upgrade solution Amiga 3000 deserve. Despite a lot of people express their like in the A3000, it seems as if the last few years have been all about the A4000.

For all of these reasons, I'm crossing my fingers that the Z3660 will deliever on all accounts. Personally, I have a spare MC68060 I would really like to put to good use in my Amiga 3000, and with a bit of luck the Z3660 is the card I'm looking for.

By the way, do you see any reason it will not be fully hardware compatible with the A3000?

shanshe, 2024-02-02:
Hi, Z3660 is working with A3000 (with both 060 and emulator) as reported by @kavanoz at discord channel. Probably, internal A3000 SCSI is not working as it would require DMA CPLD version (I tried on a separately branch, currently I'm merging it to the main branch).
Finally, Z3660 should be compatible with A3000 in the same way A3660 is... (well, with the exception of SCSI DMA, that A3660 has nothing to do here)

kavanoz64, 2024-02-10:
My Github username is @Kavanoz64
I know it's confusing, but when you refer to Discord name, maybe don't use @ symbol.

shanshe, 2024-02-10:
edited :)

kakemoms, 2024-03-12:
Hi!

I'm going to make a Z3660 and have started ordering a few things (060, CPU connector, DCDC). JLCPCB seems to have the best price at the moment.

Anything I should be aware of before I mush it all together? Can I use pin headers for the CPU or is that a bad idea.

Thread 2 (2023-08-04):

HTML BOM

tkurbad, 2023-08-04:
Hi @shanshe,

from the looks of the schematics I guess that you used KiCAD for the design.

There's a nice plugin available that creates an HTML BOM, where you have a "picture" of the PCB and the list of parts to make placing them much easier. This is helpful with the birdseed in particular.

Would you consider adding such a BOM? One of the nicer features is that you can select to have the PCBs depicted with traces. This helps to see which adjacent pins of buffers, CPLD, etc. are bridged by design...

My PCBs shipped today from China. I'm curious how they will come out.

Thank you, and best regards
Torsten

shanshe, 2023-08-04:
I have been working with KiCAD for many years but never stopped to look at that plugin. It's perfect!!!
Now, I'm generating the html BOM, but I'm erasing some components that are not needed, and others that are yet to be tested.
Thanks a lot for your constructive comments!!!

tkurbad, 2023-08-04:
> but I'm erasing some components that are not needed, and others that are yet to be tested.

Did you see that the plugin has filter options for just that? You can blacklist single components or whole classes (e.g. all resistors, although that probably doesn't make sense :wink:)

shanshe, 2023-08-04:
Yes, I have used it to hide (not erase, hehehe) for example mounting holes, etc. It is a very good plugin!!!

tkurbad, 2023-08-04:
Thanks for the new BOM! This will help a lot.

Closed 2023-08-04.

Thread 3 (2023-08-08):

Need help to improve SCSI emulation

shanshe, 2023-08-08:
SCSI emulation is a translation from "PISCSI", the SCSI emulation of PiStorm.
As PiStorm is so fast, this SCSI emulation doesn't matter if it has interrupts or not... It runs in a thread, and it is fast, really fast.
But here, when we receive a command, then we wait until f_read/f_write function is done.
This could be solved if we use some buffers for reading and writing, some function to manage these buffers, and using interrupts to inform to the Amiga (i.e. to the z3660_sicsi.device driver) that the read or write has finished.
I need help to do this, or to rethink the SCSI emulation, as now, it feels slower than the A4000 internal IDE.

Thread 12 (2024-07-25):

Click/Pop sound when starting AmigAmp

DarrenHD23, 2024-07-25:
When you start AmigaAMP using the MHI driver, you hear a momentary (fairly loud) click or pop sound.  And then if you start to play back an mp3 stream, you hear it again.  Version1.03 Beta 8 and lower are affected.  Tested on AA3000+, Z3660 in 060 mode.  It is not *always present* but most of the time you hear it.

shanshe, 2024-07-25:
Thanks @DarrenHD23, probably my audio bar system has an anti pop/click filter, as I don't hear it. I will look for some old speakers...
I replaced the ZZ9000 AX DSP, by a few band filters. All of them have buffers to implement the IIR filters. I will review them and see if they are cleared before used.
Also there is a double line buffer that should be cleared (but in this case I clear it at the init of the ARM), so I will see if it is necessary to clear it after stop playing audio (or before start playing audio).
I will write here the progress in this issue...

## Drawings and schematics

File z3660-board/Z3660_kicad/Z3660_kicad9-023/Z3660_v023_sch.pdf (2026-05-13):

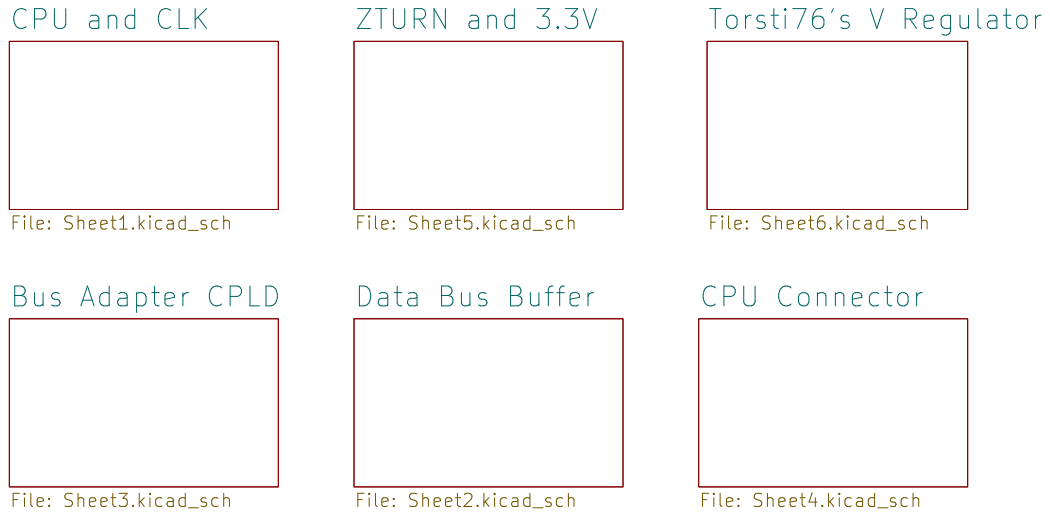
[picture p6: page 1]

v0.21e no changes in schematics

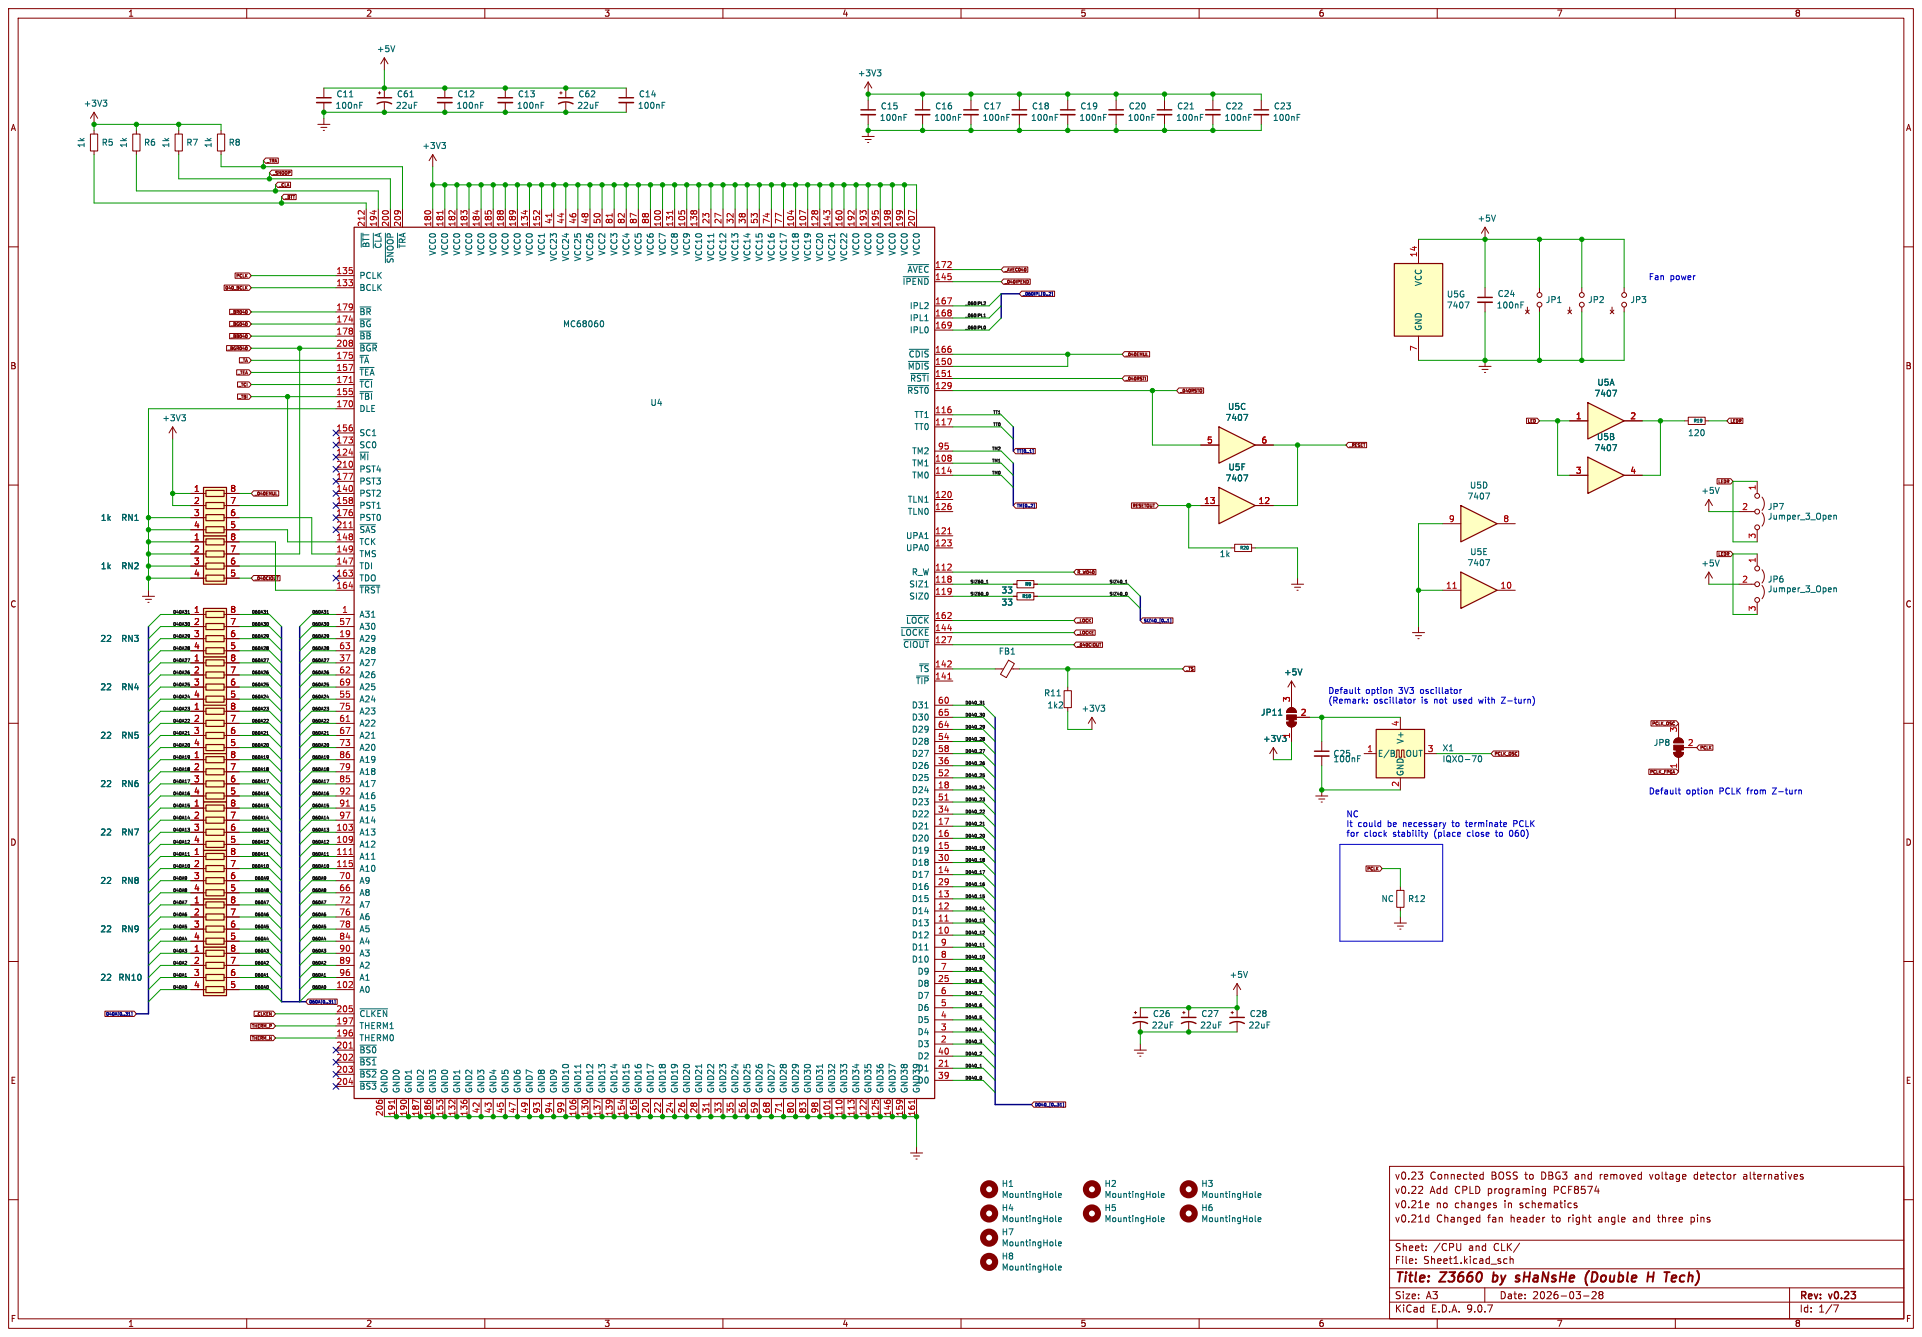
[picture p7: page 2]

Jumper_3_Open C23
Fan power Default option PCLK from Z-turn

v0.21e no changes in schematics

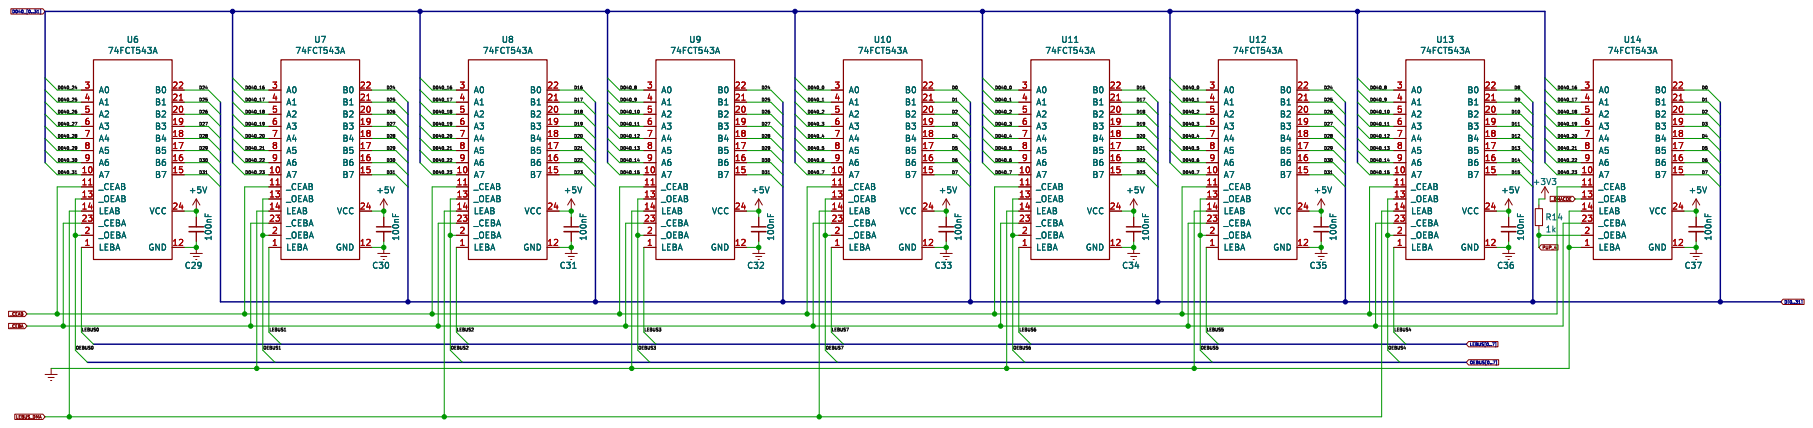
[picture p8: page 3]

v0.21e no changes in schematics

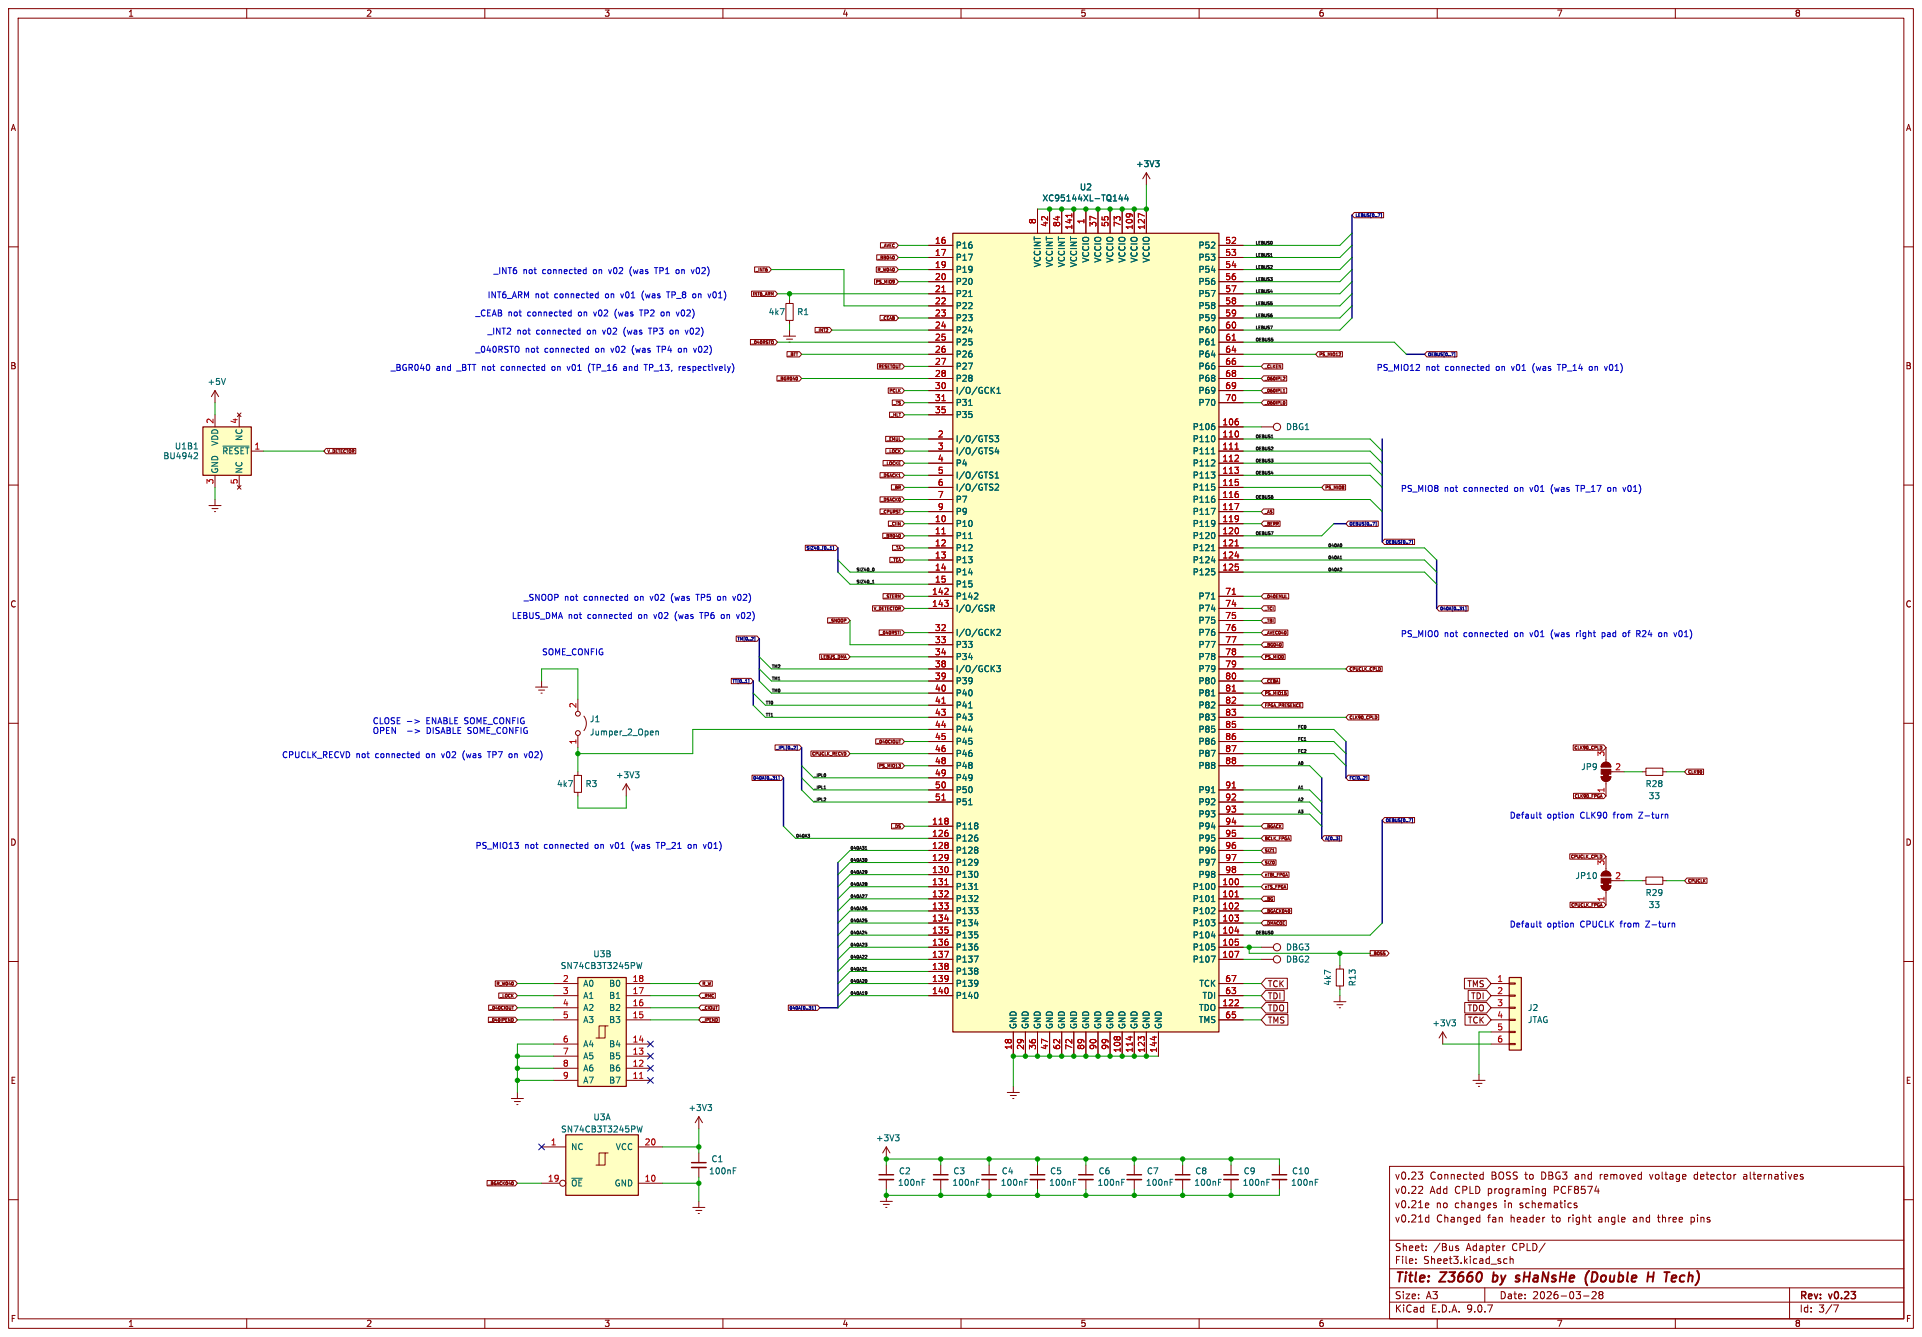
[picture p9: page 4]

8 GND 36 VCCINT 42 GND 47 VCCINT 84 GND 62 VCCINT 141 GND 72 VCCIO

1 GND 89 VCCIO 37 GND 90 VCCIO 55 GND 99 VCCIO 73 GND 108 VCCIO 109 GND 114 VCCIO 127 GND 123 GND 144 P52 52 P53 53 P54 54 P56 56 P57 57 P58 58 P59 59 P60 60 P61 61 P64 64 P66 66 P68 68 P69 69 P70 70 P106 106 P110 110 P111 111 P112 112 P113 113 P115 115 P116 116 P117 117 P119 119 P120 120 P121 121 P124 124 P125 125 P71 71 P74 74 P75 75 P76 76 P77 77 P78 78 P79 79 P80 80 P81 81 P82 82 P83 83 P85 85 P86 86 P87 87 P88 88 P91 91 P92 92 P93 93 P94 94 P95 95 P96 96 P97 97 P98 98 P100 100 P101 101 P102 102 P103 103 P104 104 P105 105 P107 107 TCK 67 TDI 63 TDO 122 TMS 65

v0.21e no changes in schematics

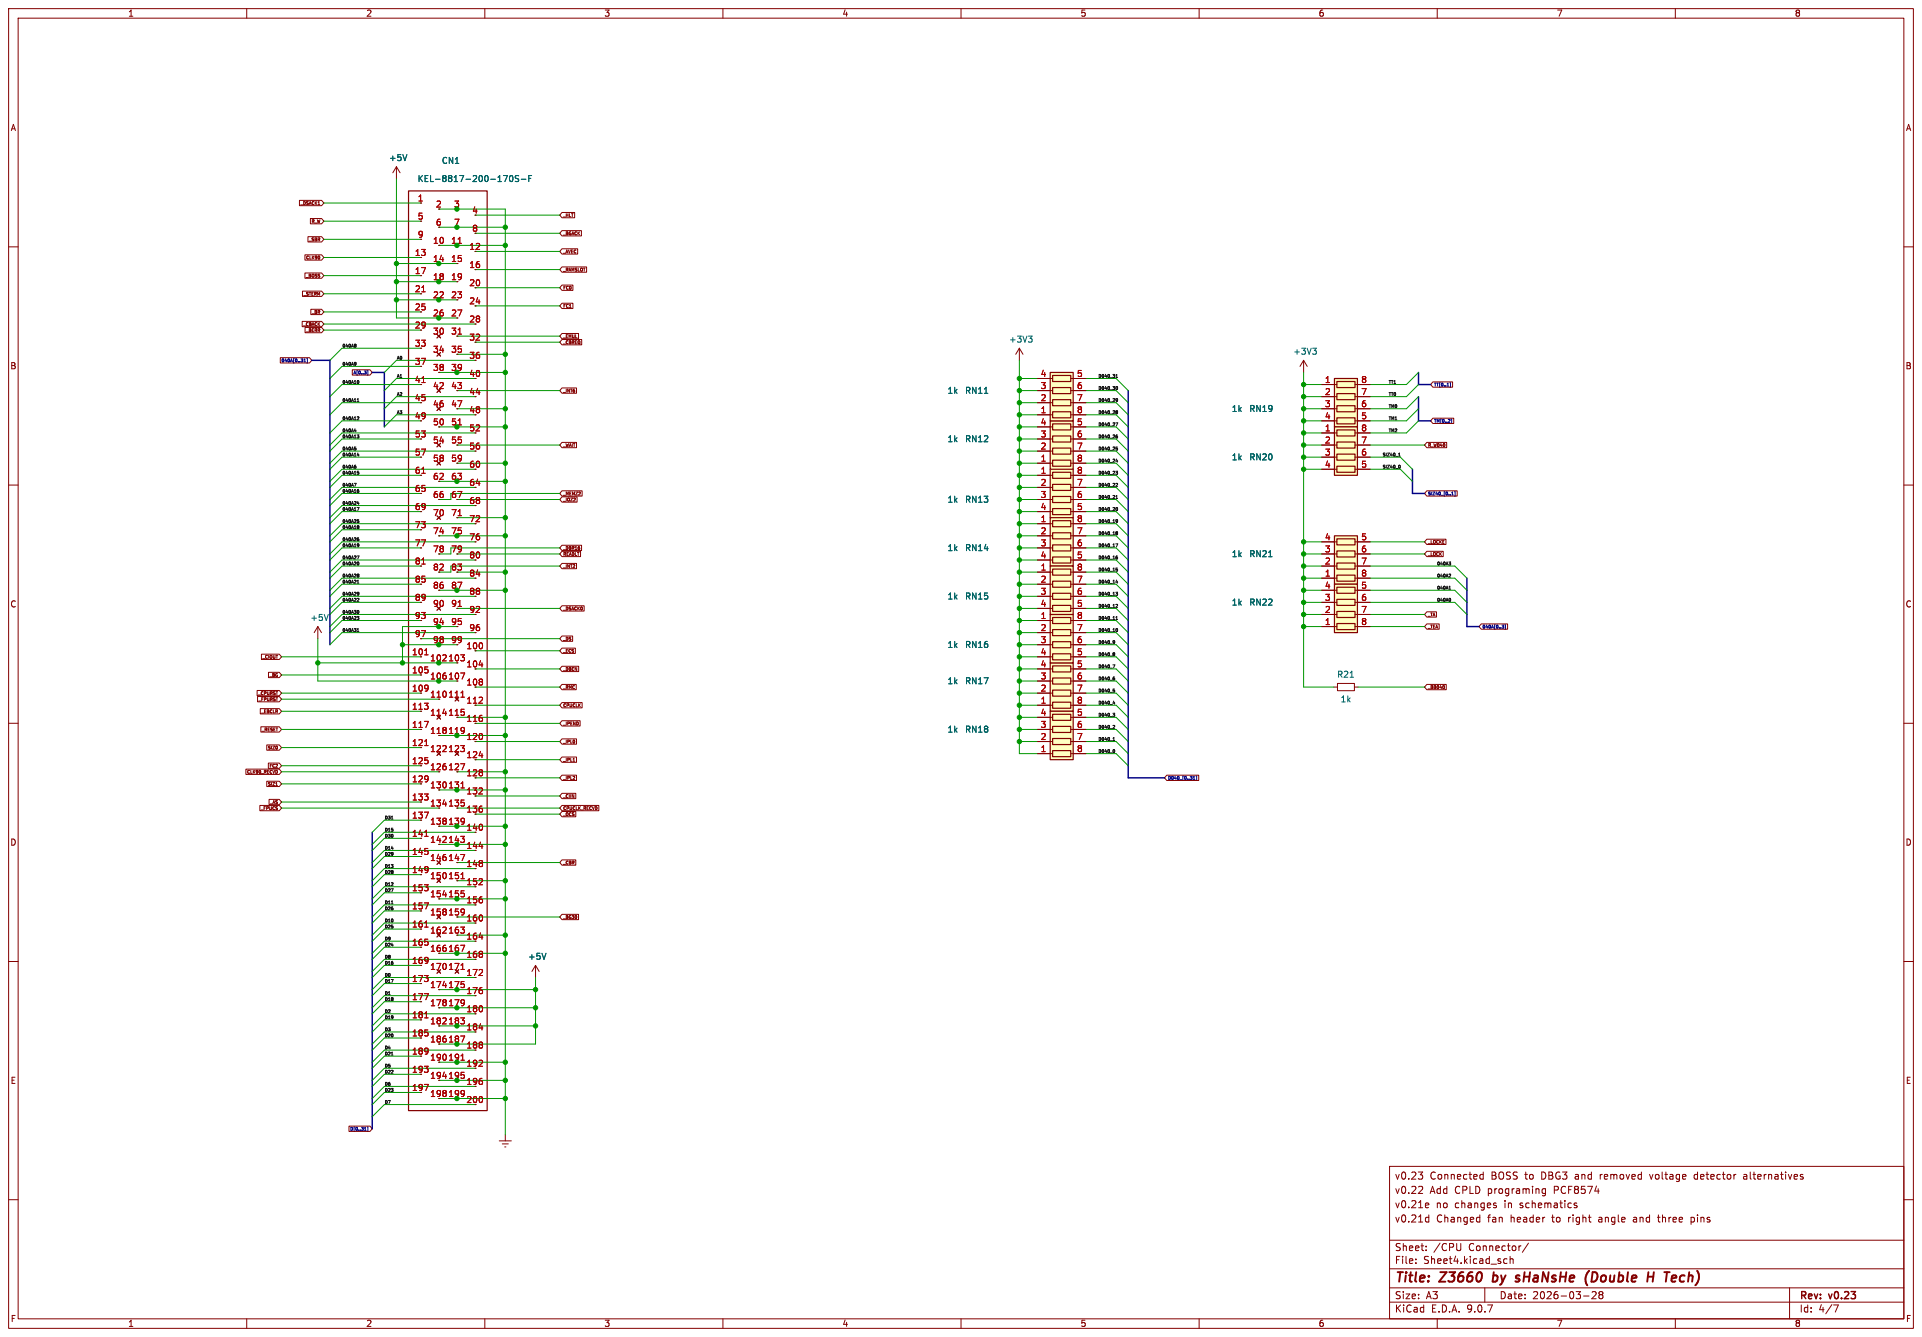
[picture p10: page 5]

v0.21e no changes in schematics

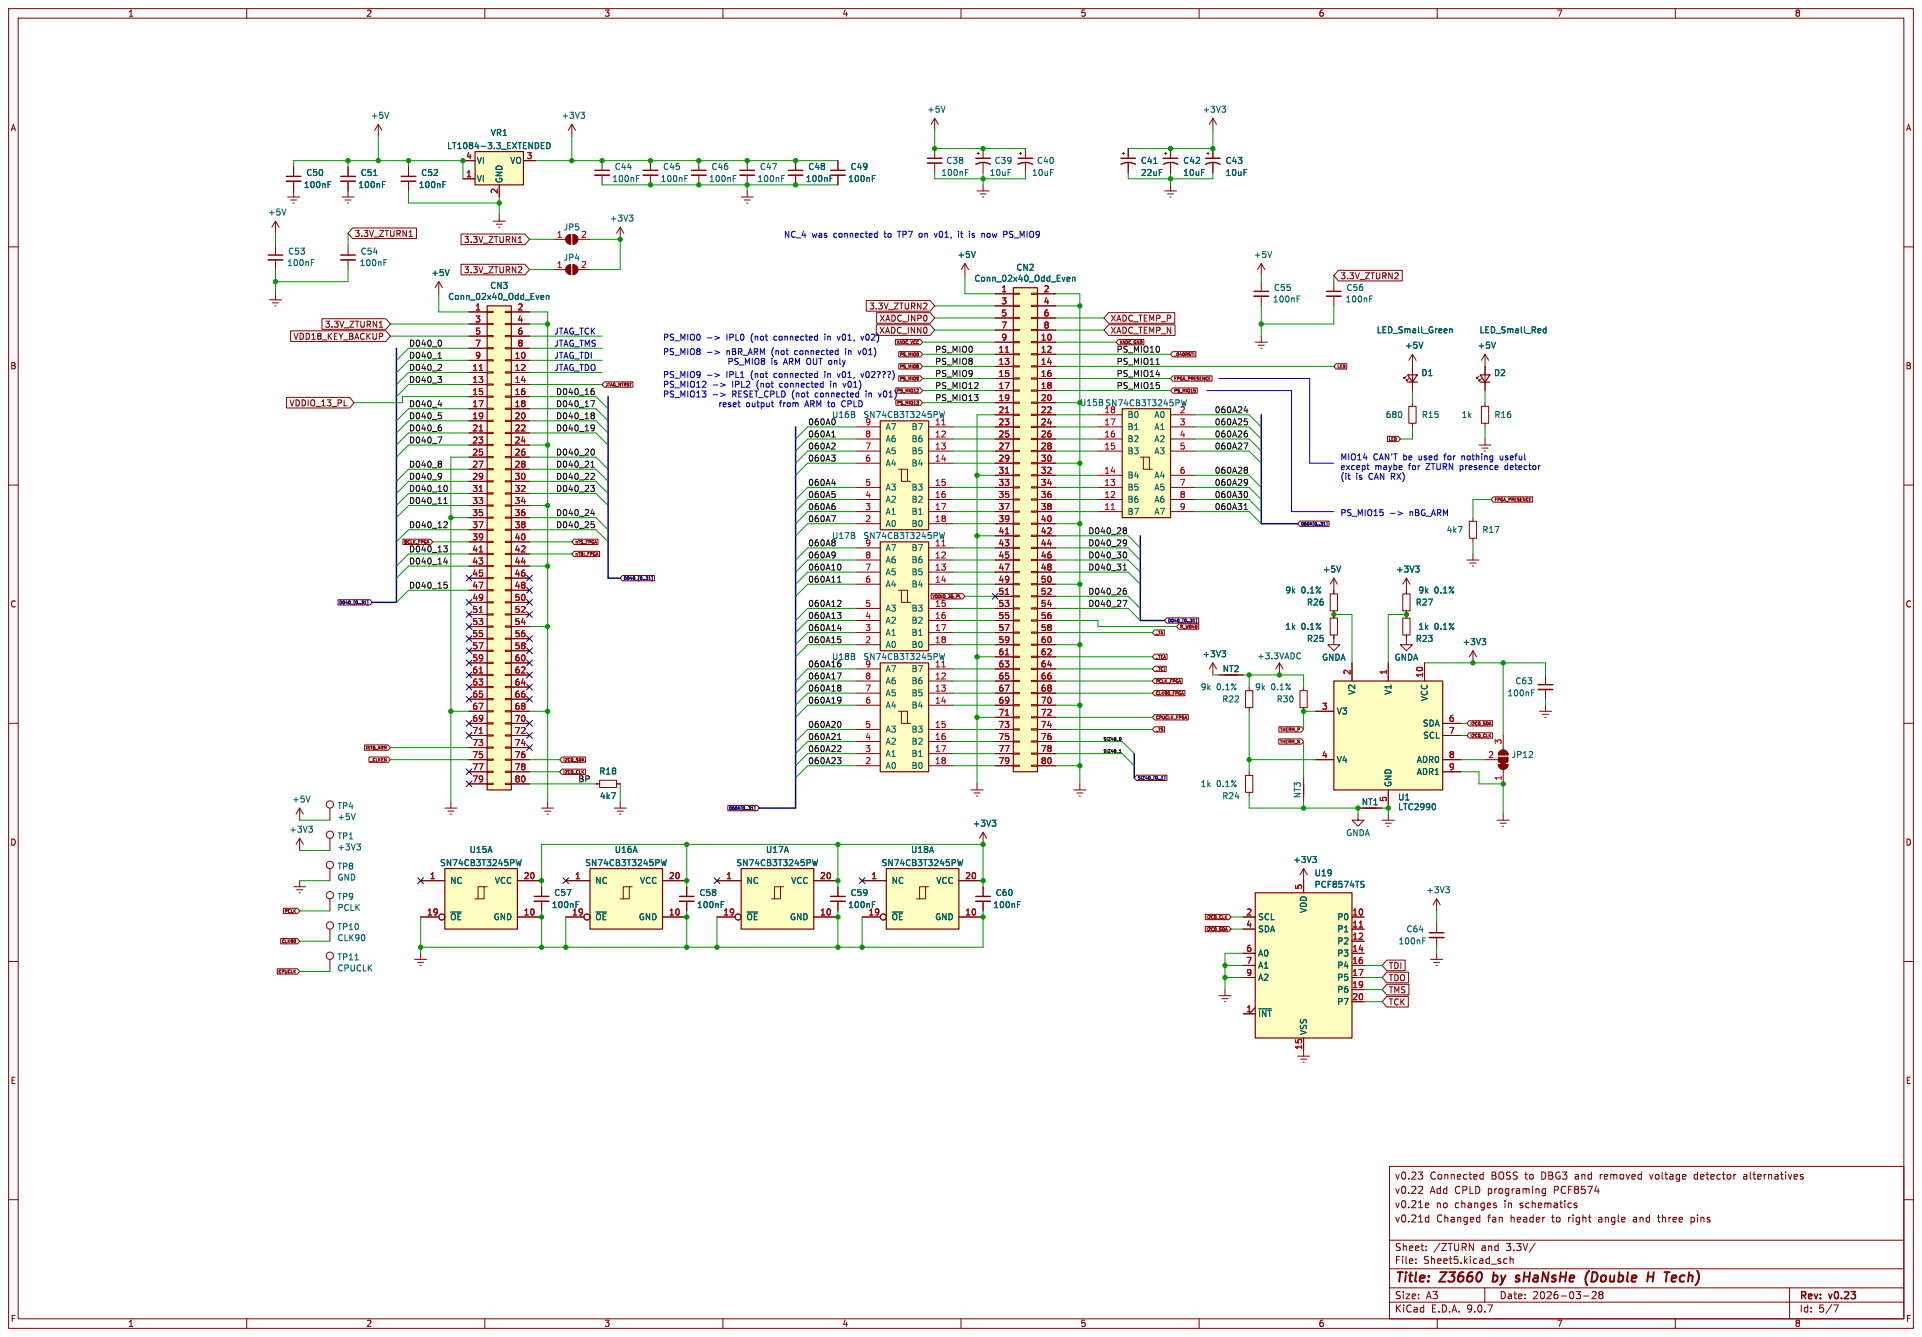
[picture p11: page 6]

reset output from ARM to CPLD

MIO14 þÿCAN T be used for nothing useful except maybe for ZTURN presence detector

(it is CAN RX) U17A

v0.21e no changes in schematics

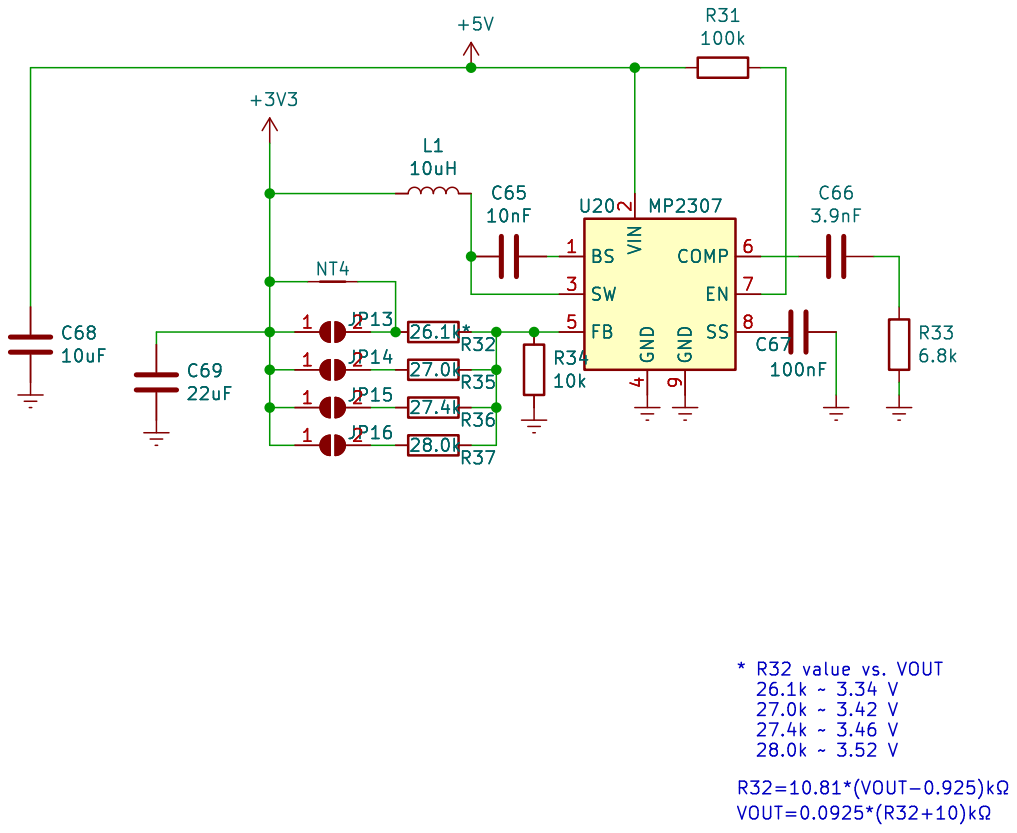
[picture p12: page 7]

9 BS 1 SW 3 FB 5 VIN

v0.21e no changes in schematics

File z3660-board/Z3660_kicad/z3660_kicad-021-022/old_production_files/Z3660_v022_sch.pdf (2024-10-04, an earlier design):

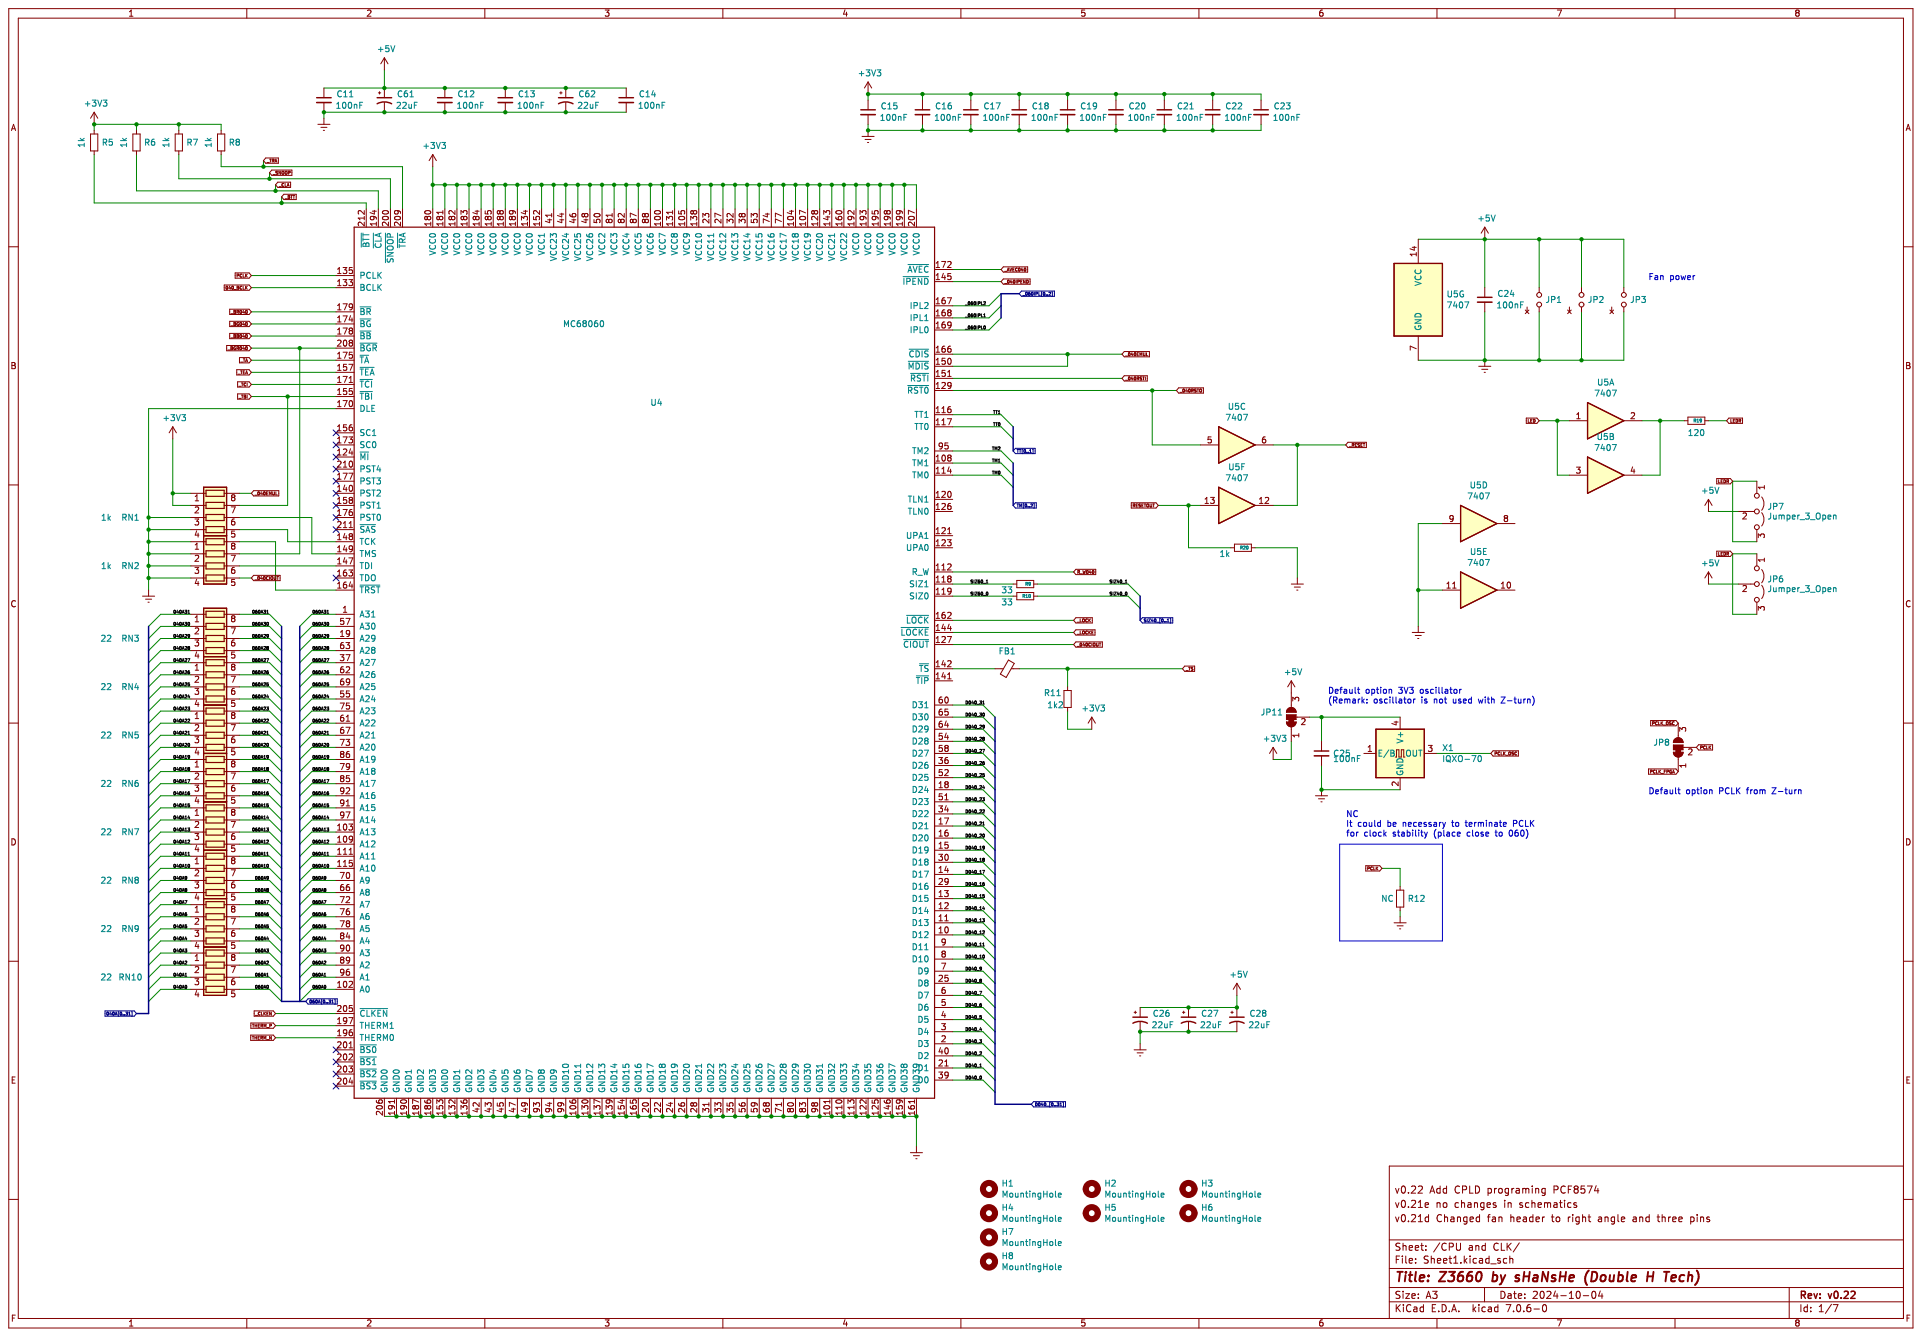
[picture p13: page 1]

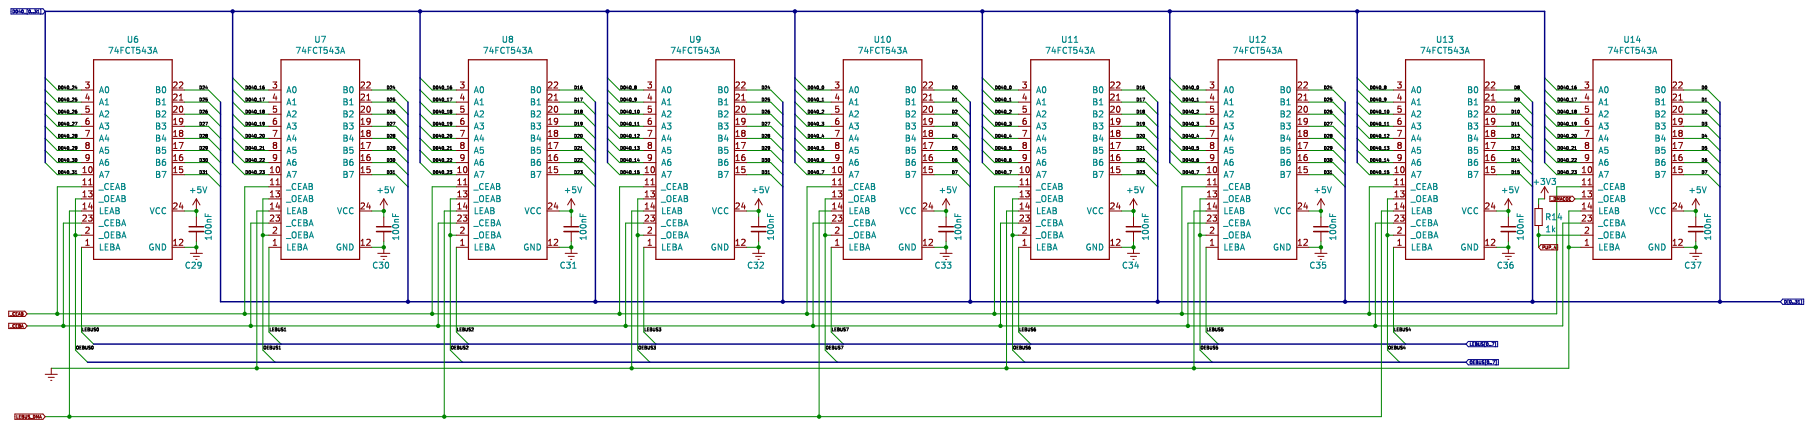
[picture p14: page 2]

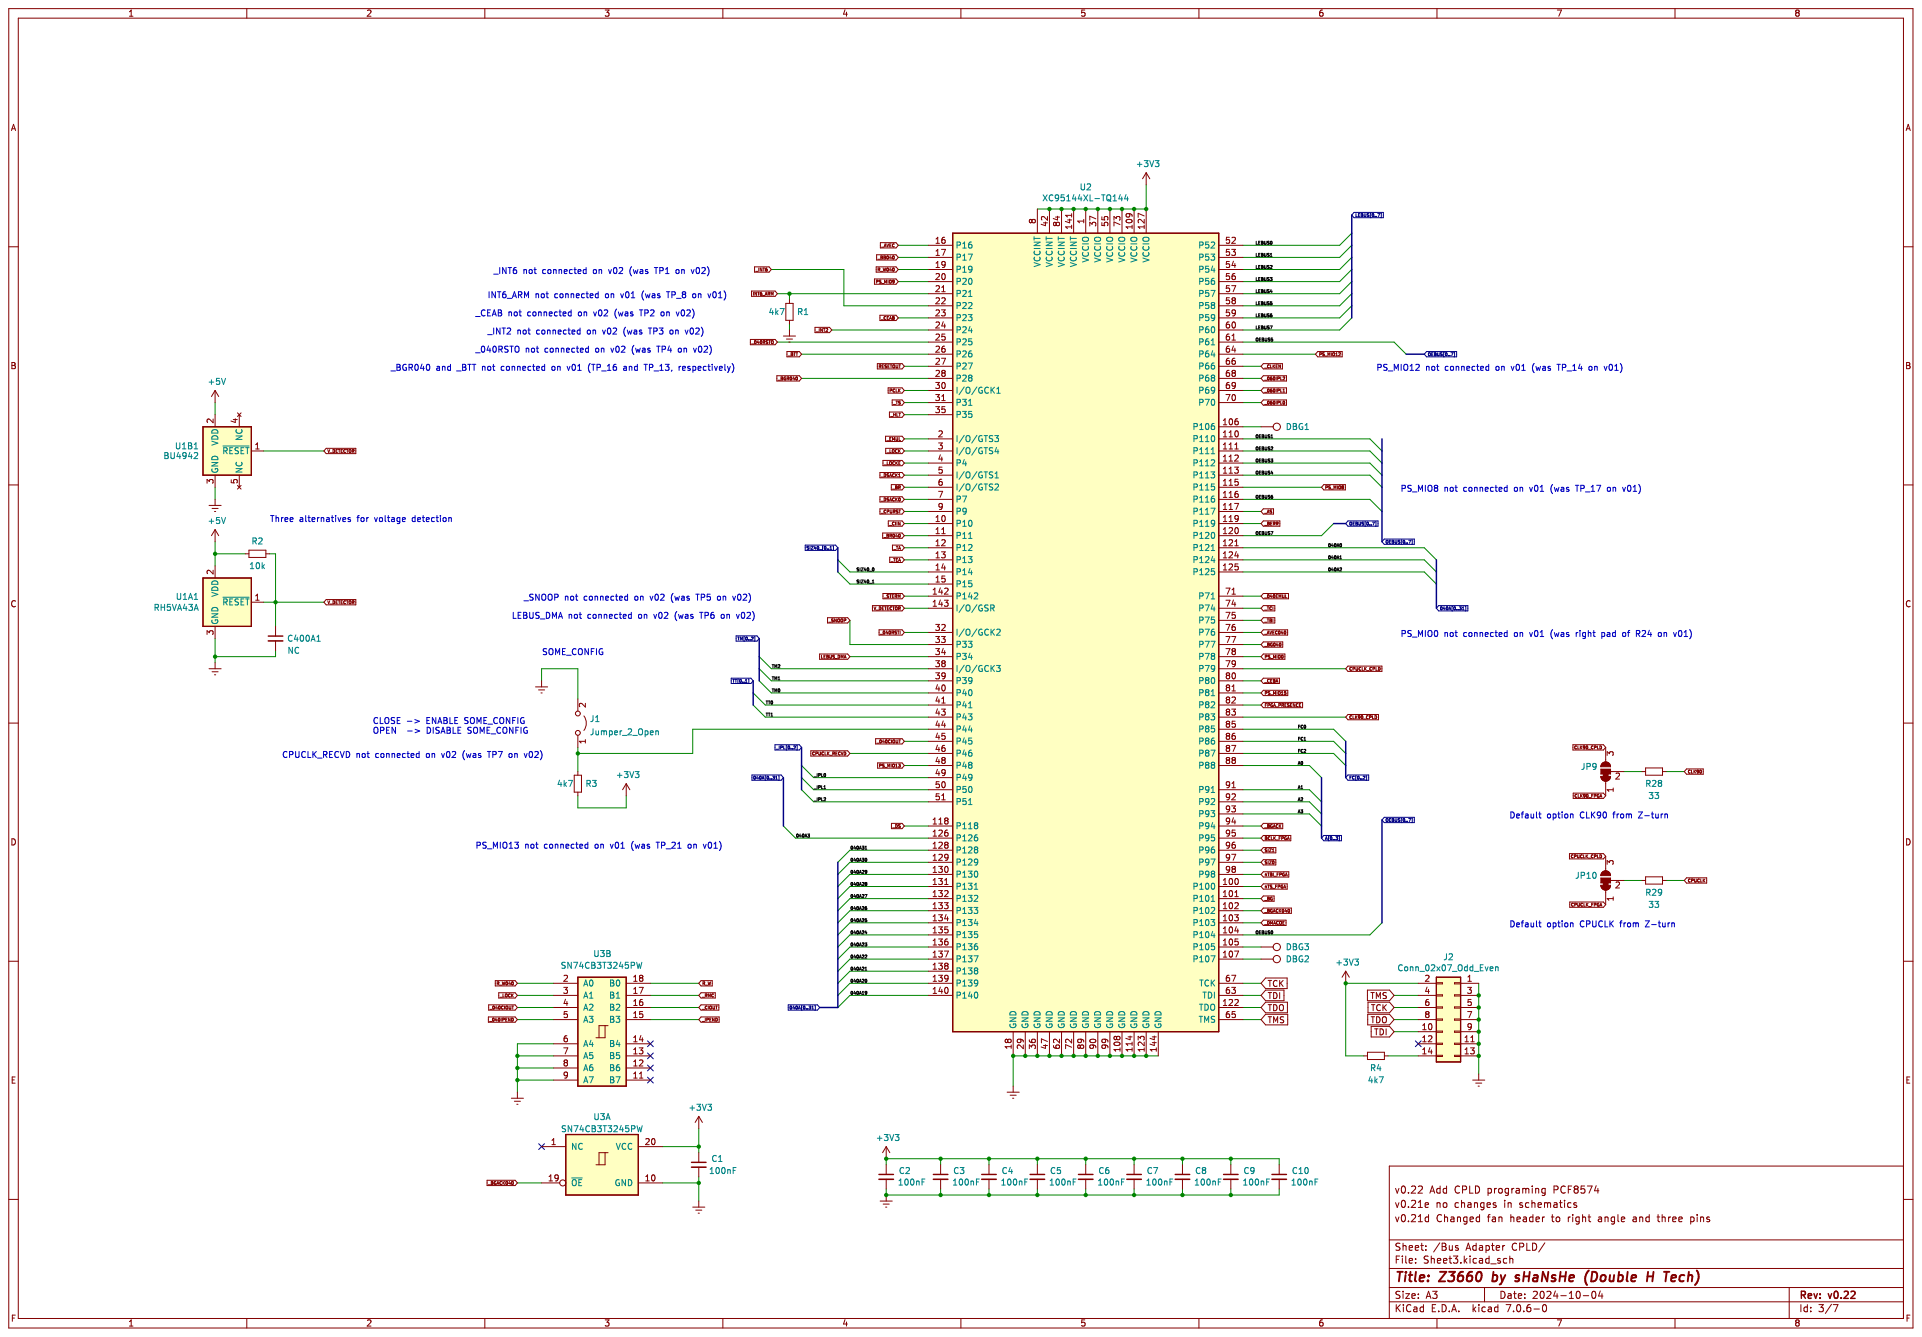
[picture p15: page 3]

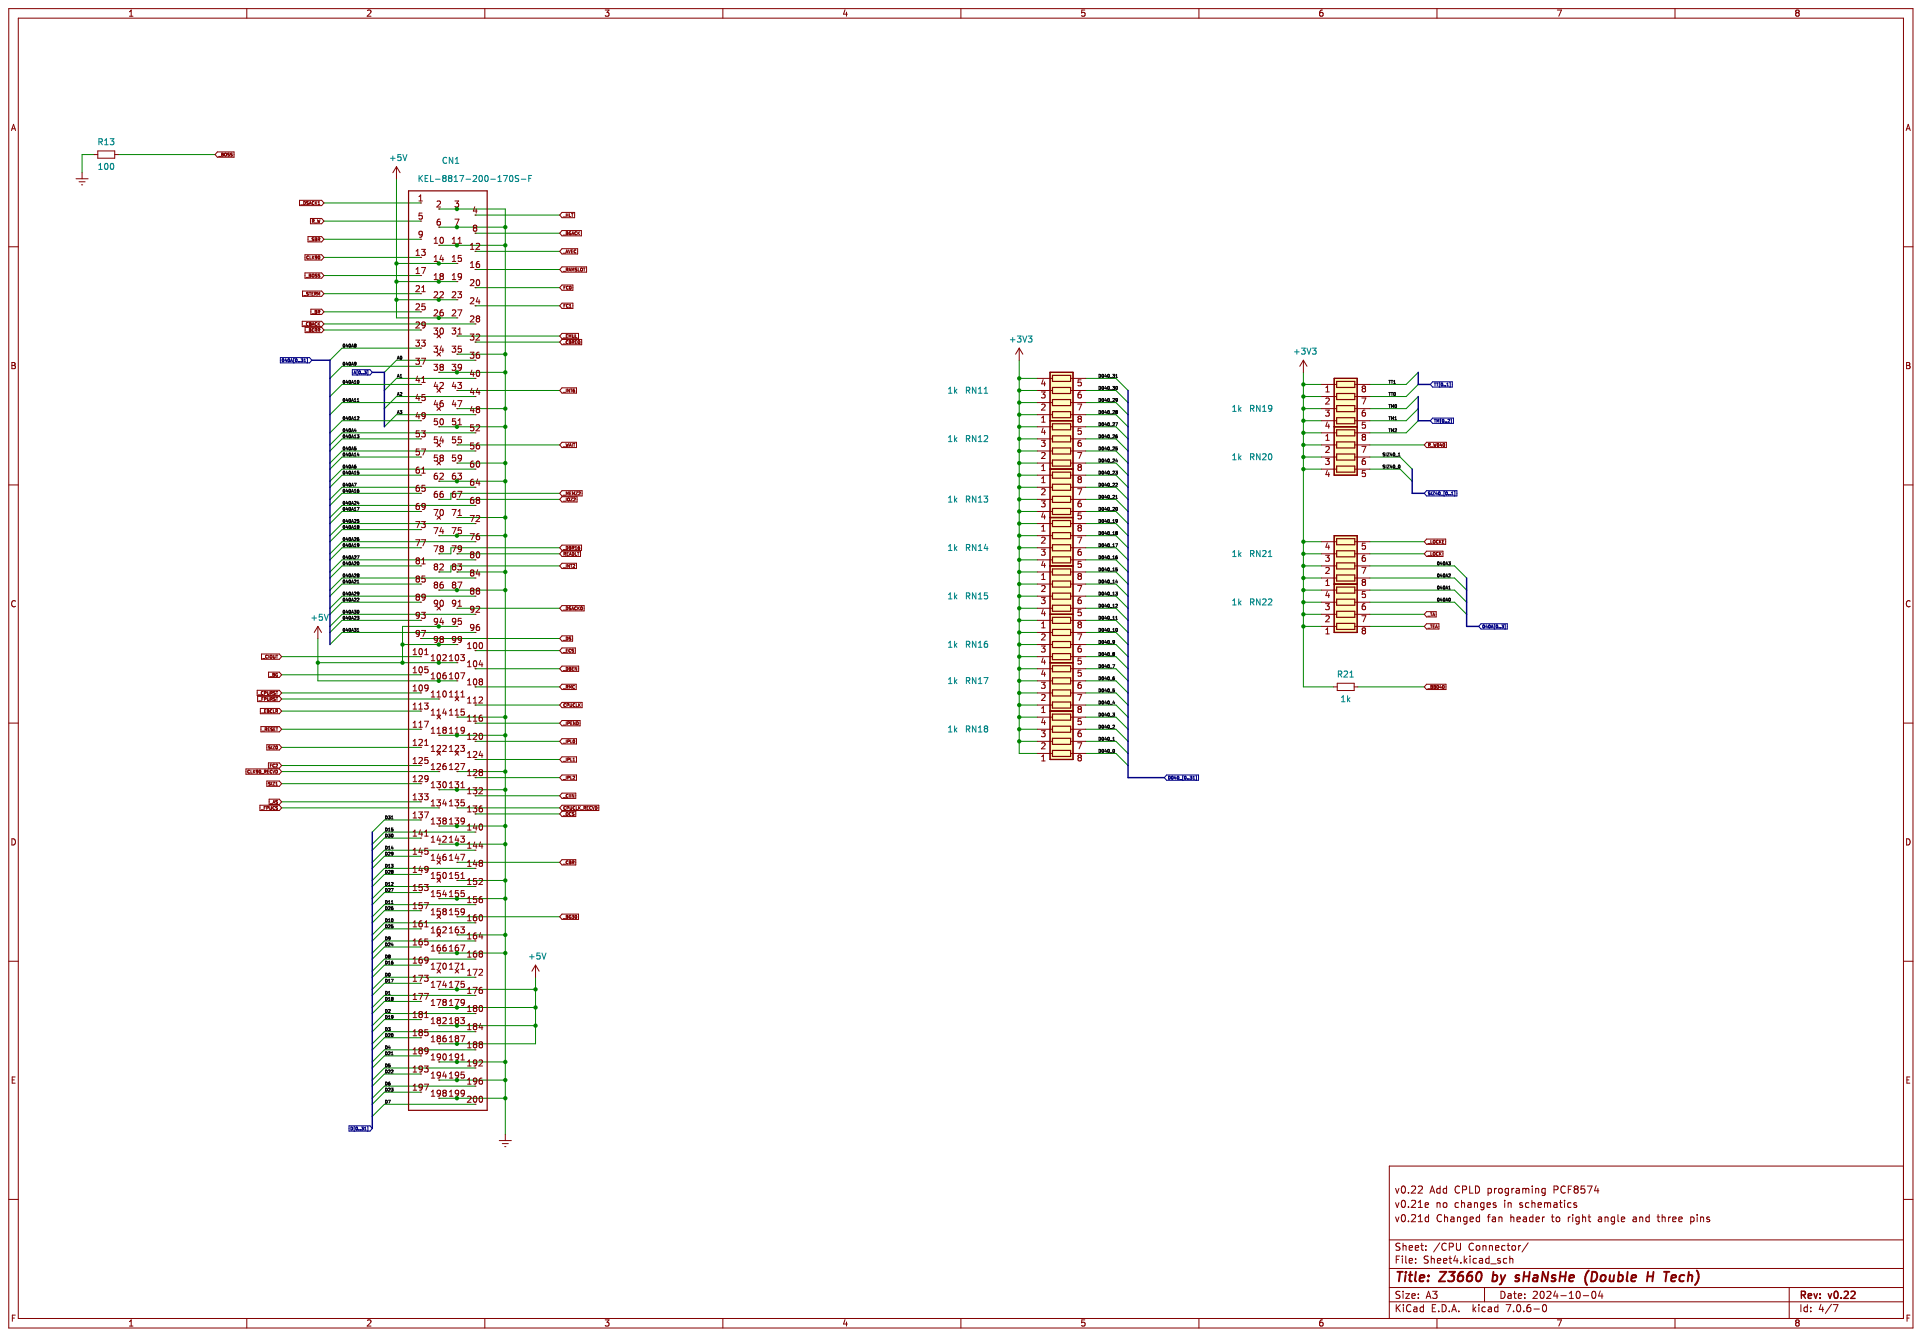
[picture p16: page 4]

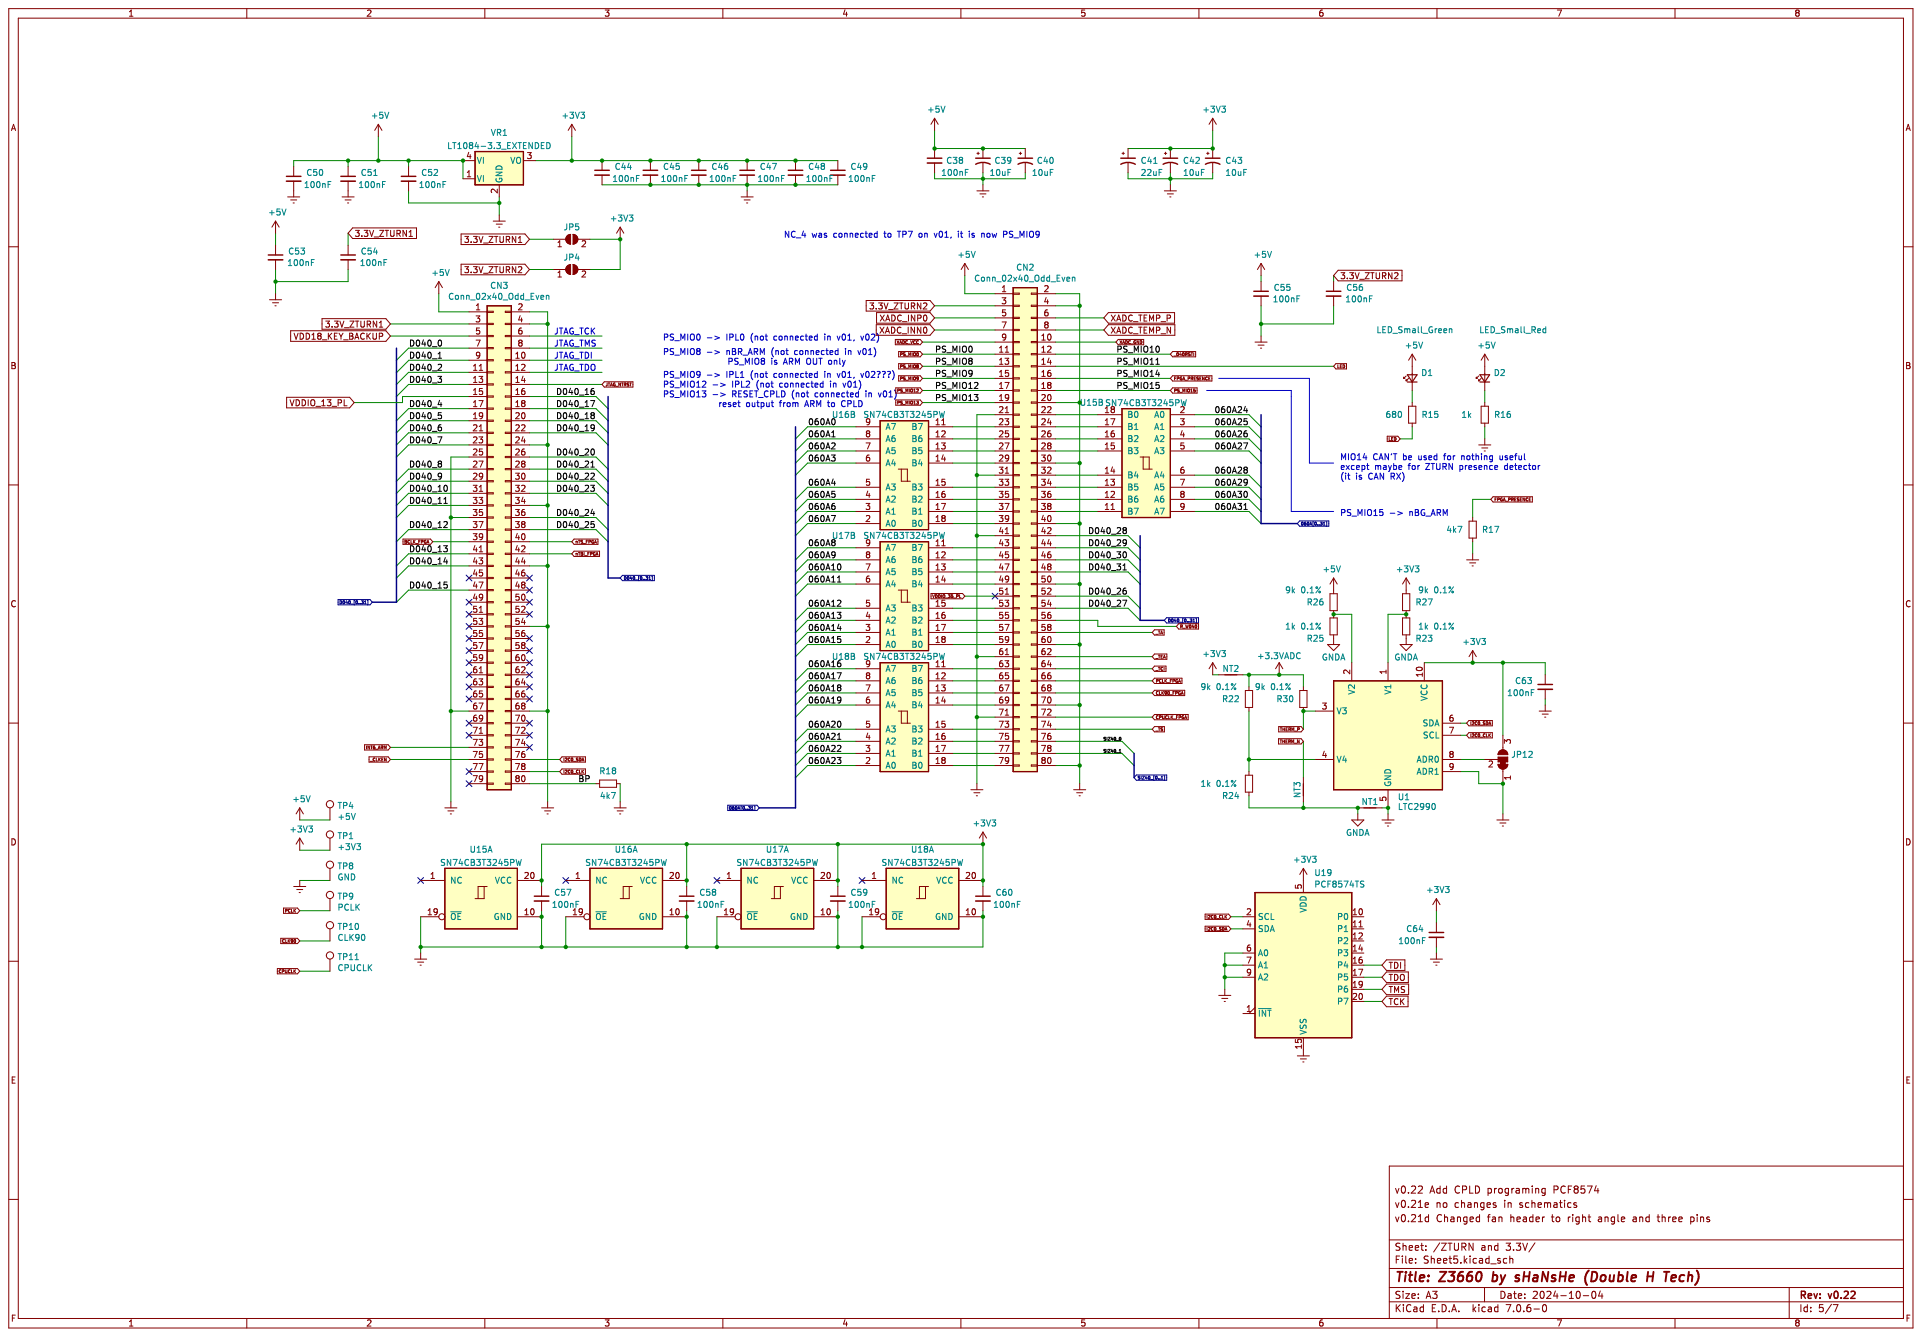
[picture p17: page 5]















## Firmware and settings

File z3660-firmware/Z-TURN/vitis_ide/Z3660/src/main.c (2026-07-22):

/******************************************************************************
 *
 * Copyright (C) 2009 - 2014 Xilinx, Inc.  All rights reserved.
 *
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
 * Use of the Software is limited solely to applications:
 * (a) running on a Xilinx device, or
 * (b) that interact with a Xilinx device through a bus or interconnect.
 *
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
 * Except as contained in this notice, the name of the Xilinx shall not be used
 * in advertising or otherwise to promote the sale, use or other dealings in
 * this Software without prior written authorization from Xilinx.
 *
 ******************************************************************************/

#include <stdio.h>
#include "main.h"
#include "config_clk.h"
#include "mobotest.h"
#include "xil_misc_psreset_api.h"
#include "config_file.h"
#include "scsi/scsi.h"
#include "floppy/floppy.h"
#include "ltc2990/ltc2990.h"
#include "../../Z3660_emu/src/defines.h"
#include "ARM_ztop/slider.h"
#include "debug_console.h"
#ifdef CPU_EMULATOR
#include "cpu_emulator.h"
#endif
#include "lwip.h"
#include <stdlib.h>
#include "ps7_init_simple.h"
extern SHARED *shared;
extern DEBUG_CONSOLE debug_console;
extern ENV_FILE_VARS env_file_vars_temp[9]; // really size 8

#include "pt/pt.h"
#include "ethernet.h"
#include <xtime_l.h>

#include "usb_proxy.h"

// usb state
// Protocol: 0 = idle/error, 0xFFFF = busy (transfer in progress), other = success (blocks transferred)
#define USB_STATUS_BUSY 0xFFFF
uint16_t usb_status = 0;
uint16_t usb_proxy_status = 0;
uint32_t usb_read_write_num_blocks = 1;
volatile int usb_read_pending = 0;
volatile int usb_write_pending = 0;
volatile int usb_proxy_pending = 0;

extern uint32_t revision_alfa;
int rtg_thread(struct pt *pt);
int ethernet_thread(struct pt *pt);
int usb_thread(struct pt *pt);
int debug_thread(struct pt *pt);
int reset_thread(struct pt *pt);
int measures_thread(struct pt *pt);
int emulator_thread(struct pt *pt);
int emulator_reset_thread(struct pt *pt);
int interrupt_thread(struct pt *pt);
uint32_t arm_read_amiga_byte(uint32_t address);
void arm_write_amiga_byte(uint32_t address, uint32_t data);
int read_timings(void);

static struct pt pt_rtg;
static struct pt pt_ethernet;
static struct pt pt_usb;
static struct pt pt_debug;
static struct pt pt_reset;
struct pt pt_measures;
static struct pt pt_emulator;
static struct pt pt_emulator_reset;
static struct pt pt_interrupt;
extern int eth_backlog_nag_counter_max;

void hard_reboot(void);
void z3660_printf(const TCHAR *format, va_list args)
{
   while(shared->uart_semaphore!=0);
   shared->uart_semaphore=1;
   vprintf(format, args);
   shared->uart_semaphore=0;
}
void init_shared(void);
#define DEBUG(...)
//#define DEBUG printf

//#define LED_HDD

XGpioPs GpioPs;
XGpioPs_Config *GpioPsConfigPtr;
//XGpio Gpio;
//XGpio_Config *GpioConfigPtr;

extern uint32_t clken;
#define ENABLE_TSCONDITION(A) do{   DiscreteSet(REG0, A);\
      }while(0)

#define ENABLE_ENCONDITION_PCLK0_CLKEN0 do{   DiscreteSet(REG0, FPGA_ENCONDITION_PCLK0_CLKEN0);\
      }while(0)
#define ENABLE_ENCONDITION_PCLK1_CLKEN0 do{   DiscreteSet(REG0, FPGA_ENCONDITION_PCLK1_CLKEN0);\
      }while(0)
#define ENABLE_ENCONDITION_PCLK0 do{   clken=0;DiscreteSet(REG0, FPGA_ENCONDITION_PCLK0);\
      }while(0)
#define ENABLE_ENCONDITION_PCLK1 do{   clken=0;DiscreteSet(REG0, FPGA_ENCONDITION_PCLK1);\
      }while(0)

#define ENABLE_FPGA_ADVANCED_BURST do{   DiscreteSet(REG0, FPGA_ADVANCED_BURST);\
      }while(0)
#define DISABLE_FPGA_ADVANCED_BURST do{   DiscreteClear(REG0, FPGA_ADVANCED_BURST);\
      }while(0)

#define ENABLE_FPGA_PREFETCH_ENABLE do{   DiscreteSet(REG0, FPGA_PREFETCH_ENABLE);\
      }while(0)
#define DISABLE_FPGA_PREFETCH_ENABLE do{   DiscreteClear(REG0, FPGA_PREFETCH_ENABLE);\
      }while(0)

#define ENABLE_CPUCLK_OUPUT_FPGA do{   DiscreteSet(REG0, FPGA_ENABLE_CPUCLK_OUTPUT);\
      }while(0)
#define DISABLE_CPUCLK_OUTPUT_FPGA do{ DiscreteClear(REG0, FPGA_ENABLE_CPUCLK_OUTPUT);\
      }while(0)

#define ENABLE_CPU_RAM_FPGA do{   DiscreteSet(REG0, FPGA_RAM_EN);\
      }while(0)
#define DISABLE_CPU_RAM_FPGA do{ DiscreteClear(REG0, FPGA_RAM_EN);\
      }while(0)
#define ENABLE_MAPROM_FPGA do{   DiscreteSet(REG0, FPGA_MAPROM_EN);\
      }while(0)
#define DISABLE_MAPROM_FPGA do{ DiscreteClear(REG0, FPGA_MAPROM_EN);\
      }while(0)
#define ENABLE_MAPROMEXT_FPGA do{   DiscreteSet(REG0, FPGA_MAPROMEXT_EN);\
      }while(0)
#define DISABLE_MAPROMEXT_FPGA do{ DiscreteClear(REG0, FPGA_MAPROMEXT_EN);\
      }while(0)

#define ENABLE_256MB_AUTOCONFIG do{DiscreteSet(REG0, FPGA_256MB_AUTOCONFIG_EN);\
      }while(0)
#define DISABLE_256MB_AUTOCONFIG do{DiscreteClear(REG0, FPGA_256MB_AUTOCONFIG_EN);\
      }while(0)

#define ENABLE_RTG_AUTOCONFIG do{DiscreteSet(REG0, FPGA_RTG_AUTOCONFIG_EN);\
      }while(0)
#define DISABLE_RTG_AUTOCONFIG do{DiscreteClear(REG0, FPGA_RTG_AUTOCONFIG_EN);\
      }while(0)

#define ENABLE_SCSI_AUTOCONFIG do{DiscreteSet(REG0, FPGA_SCSI_AUTOCONFIG_EN);\
      }while(0)
#define DISABLE_SCSI_AUTOCONFIG do{DiscreteClear(REG0, FPGA_SCSI_AUTOCONFIG_EN);\
      }while(0)

//uint8_t DestinationAddress[10*1024*1024] __attribute__ ((aligned(32)));
//uint8_t SourceAddress[10*1024*1024] __attribute__ ((aligned(32)));

/*
//
// To test logical drive 0, FileName should be "0:/<File name>" or
// "<file_name>". For logical drive 1, FileName should be "1:/<file_name>"
//
static char FileName[32] = DEFAULT_ROOT "Test.bin";
static char *SD_File;
int FfsSdPolledExample(void)
{
   FRESULT Res;
   UINT NumBytesRead;
   UINT NumBytesWritten;
   uint32_t BuffCnt;
//   BYTE work[FF_MAX_SS];
   uint32_t FileSize = (8*1024*1024);


   // To test logical drive 0, Path should be "0:/"
   // For logical drive 1, Path should be "1:/"
   //
   TCHAR *Path = DEFAULT_ROOT;

   for(BuffCnt = 0; BuffCnt < FileSize; BuffCnt++){
      SourceAddress[BuffCnt] = TEST + BuffCnt;
   }

   //
   // Register volume work area, initialize device
   //
   Res = f_clk_mount(&fatfs, Path, 0);

   if (Res != FR_OK) {
      return XST_FAILURE;
   }

   //
   //  Path - Path to logical driver, 0 - FDISK format.
   //  0 - Cluster size is automatically determined based on Vol size.
   //

//   Res = f_mkfs(Path, FM_FAT32, 0, work, sizeof work);
//   if (Res != FR_OK) {
//      return XST_FAILURE;
//   }

   //
   // Open file with required permissions.
   // Here - Creating new file with read/write permissions. .
   // To open file with write permissions, file system should not
   // be in Read Only mode.
   //
   SD_File = (char *)FileName;

   Res = f_open(&fil, SD_File, FA_CREATE_ALWAYS | FA_WRITE | FA_READ);
   if (Res) {
      return XST_FAILURE;
   }

   //
   // Pointer to beginning of file .
   //
   Res = f_lseek(&fil, 0);
   if (Res) {
      return XST_FAILURE;
   }

   //
   // Write data to file.
   //
   Res = f_write(&fil, (const void*)SourceAddress, FileSize,
         &NumBytesWritten);
   if (Res) {
      return XST_FAILURE;
   }

   //
   // Pointer to beginning of file .
   //
   Res = f_lseek(&fil, 0);
   if (Res) {
      return XST_FAILURE;
   }

   //
   // Read data from file.
   //
   Res = f_read(&fil, (void*)DestinationAddress, FileSize,
         &NumBytesRead);
   if (Res) {
      return XST_FAILURE;
   }

   //
   // Data verification
   //
   for(BuffCnt = 0; BuffCnt < FileSize; BuffCnt++){
      if(SourceAddress[BuffCnt] != DestinationAddress[BuffCnt]){
         return XST_FAILURE;
      }
   }

   //
   // Close file.
   //
   Res = f_close(&fil);
   if (Res) {
      return XST_FAILURE;
   }

   return XST_SUCCESS;
}
 */
/*
//char Filename[]=DEFAULT_ROOT "Test.hdf";
//char Filename[]=DEFAULT_ROOT "hd0.img";
char Filename[]=DEFAULT_ROOT "hd0.hdf";
void CreateHdf(void)
{
   TCHAR *Path = DEFAULT_ROOT;
   uint32_t BufferSize = (10*1024*1024);

   //
   // Register volume work area, initialize device
   //
   for(int32_t BuffCnt = 0; BuffCnt < BufferSize; BuffCnt++){
      SourceAddress[BuffCnt] = 0;
   }
   f_clk_mount(&fatfs, Path, 0);
   f_open(&fil, Filename, FA_CREATE_ALWAYS | FA_WRITE | FA_READ);
   UINT len;
   for(int i=0;i<10;i++)
      f_write(&fil, (const void*)SourceAddress, BufferSize, &len);
   f_close(&fil);
}

//static FIL fil;      // File object
//static FATFS fatfs;
void PrepareHdf(void)
{
   TCHAR *Path = DEFAULT_PATH;

   f_clk_mount(&fatfs, Path, 0);
   set_hard_drive_image_file_amiga(0,Filename);
}
 */
ZZ_VIDEO_STATE vs;
XClk_Wiz clkwiz;

void configure_gpio(void)
{
   GpioPsConfigPtr = XGpioPs_LookupConfig(XPAR_XGPIOPS_0_DEVICE_ID);
   XGpioPs_CfgInitialize(&GpioPs, GpioPsConfigPtr, GpioPsConfigPtr->BaseAddr);

   XGpioPs_SetDirectionPin(&GpioPs, n040RSTI, 0);
   XGpioPs_SetOutputEnablePin(&GpioPs, n040RSTI, 0);

   XGpioPs_SetDirectionPin(&GpioPs, JP2_PIN, 0);
   XGpioPs_SetOutputEnablePin(&GpioPs, JP2_PIN, 0);
   XGpioPs_SetDirectionPin(&GpioPs, JP1_PIN, 1);
   XGpioPs_SetOutputEnablePin(&GpioPs, JP1_PIN, 1);
   XGpioPs_WritePin(&GpioPs, JP1_PIN, 0);

   XGpioPs_SetDirectionPin(&GpioPs, USER_SW1, 0);
   XGpioPs_SetOutputEnablePin(&GpioPs, USER_SW1, 0);

   XGpioPs_SetDirectionPin(&GpioPs, LED1, 1);
   XGpioPs_SetOutputEnablePin(&GpioPs, LED1, 1);
   ACTIVITY_LED_OFF; // OFF

   XGpioPs_WritePin(&GpioPs, PS_MIO_13, 0);
   XGpioPs_SetDirectionPin(&GpioPs, PS_MIO_13, 1);
   XGpioPs_SetOutputEnablePin(&GpioPs, PS_MIO_13, 1);

   XGpioPs_WritePin(&GpioPs, PS_MIO_8, 0);
   XGpioPs_SetDirectionPin(&GpioPs, PS_MIO_8, 1);
   XGpioPs_SetOutputEnablePin(&GpioPs, PS_MIO_8, 1);

   XGpioPs_SetDirectionPin(&GpioPs, PS_MIO_0, 0);
   XGpioPs_SetOutputEnablePin(&GpioPs, PS_MIO_0, 0);
   XGpioPs_SetDirectionPin(&GpioPs, PS_MIO_9, 0);
   XGpioPs_SetOutputEnablePin(&GpioPs, PS_MIO_9, 0);
   XGpioPs_SetDirectionPin(&GpioPs, PS_MIO_12, 0);
   XGpioPs_SetOutputEnablePin(&GpioPs, PS_MIO_12, 0);
   XGpioPs_SetDirectionPin(&GpioPs, PS_MIO_15, 0);
   XGpioPs_SetOutputEnablePin(&GpioPs, PS_MIO_15, 0);

   XGpioPs_SetDirectionPin(&GpioPs, PS_MIO51_501, 1);
   XGpioPs_SetOutputEnablePin(&GpioPs, PS_MIO51_501, 1);
   XGpioPs_WritePin(&GpioPs, PS_MIO51_501, 0);
   xc3_usleep(10000);
   XGpioPs_WritePin(&GpioPs, PS_MIO51_501, 1);

   //   GpioConfigPtr = XGpio_LookupConfig(XPAR_AXI_GPIO_0_DEVICE_ID);
   //   XGpio_CfgInitialize(&Gpio, GpioConfigPtr, GpioConfigPtr->BaseAddress);

/*
   DiscreteClear(REG0, FPGA_RAM_EN);
   DiscreteClear(REG0, FPGA_MAPROM_EN);
   DiscreteClear(REG0, FPGA_MAPROMEXT_EN);
   DiscreteClear(REG0, FPGA_RAM_BURST_READ_EN);
   DiscreteClear(REG0, FPGA_RAM_BURST_WRITE_EN);
   DiscreteSet(REG0, FPGA_RESET);
   xc3_usleep(500);
   DiscreteClear(REG0, FPGA_RESET);
*/
   printf("[Core0] Configured GPIO...\n");
}
void fpga_feature_enable(int en_ram,int en_rtg,int en_z3ram,int en_maprom, int en_mapromext)
{
   if(en_ram)
   {
      ENABLE_CPU_RAM_FPGA;
      ENABLE_BURST_READ_FPGA;
      ENABLE_BURST_WRITE_FPGA;
      printf("FPGA CPU RAM ENABLED\n");
   }
   else
   {
      DISABLE_CPU_RAM_FPGA;
      DISABLE_BURST_READ_FPGA;
      DISABLE_BURST_WRITE_FPGA;
      printf("FPGA CPU RAM DISABLED\n");
   }
   if(en_rtg)
   {
      ENABLE_RTG_AUTOCONFIG;
      printf("FPGA RTG AUTOCONFIG ENABLED\n");
   }
   else
   {
      DISABLE_RTG_AUTOCONFIG;
      printf("FPGA RTG AUTOCONFIG DISABLED\n");
   }
   if(en_z3ram)
   {
      ENABLE_256MB_AUTOCONFIG;
      printf("FPGA Z3 RAM AUTOCONFIG ENABLED\n");
   }
   else
   {
      DISABLE_256MB_AUTOCONFIG;
      printf("FPGA Z3 RAM AUTOCONFIG DISABLED\n");
   }
   if(en_maprom)
   {
      ENABLE_MAPROM_FPGA;
      printf("FPGA MAPROM ENABLED\n");
   }
   else
   {
      DISABLE_MAPROM_FPGA;
      printf("FPGA MAPROM DISABLED\n");
   }
   if(en_mapromext)
   {
      ENABLE_MAPROMEXT_FPGA;
      printf("FPGA MAPROMEXT ENABLED\n");
   }
   else
   {
      DISABLE_MAPROMEXT_FPGA;
      printf("FPGA MAPROMEXT DISABLED\n");
   }
}
char Filename[]=DEFAULT_ROOT "Z3660.bin";
//extern uint32_t *frameBuf;
extern ZZ_VIDEO_STATE* video_state;
int state68k=M68K_RUNNING;
#define ARM_NO_BUS_MASTER 0
#define ARM_REQUEST_BUS_MASTER 1
#define ARM_BUS_MASTER 2
#define ARM_RELINQUISH_BUS_MASTER 3
int stateARM=ARM_NO_BUS_MASTER;
int arm_command=0;
int arm_request_bus_master=0;
#include "xil_mmu.h"
void reset_run(int cpu_boot_mode,int counter, int counter_max,int long_reset);
void reset_init(void);
int load_rom(void);
int load_romext(void);

#define AMR1_STARTADDR 0xFFFFFFF0
#define ARM1_BASEADDR 0x30000000
#define NOP __asm(" nop")

int enables=0;
uint32_t data=0;
void arm_write_amiga(uint32_t address, uint32_t data, uint32_t size)
{
   uint32_t bank=(address>>24)&0xFF;
   write_reg_s00(0x18,bank);
   NOP;
   if(size==LONG_)
      write_mem32(address,data);
   else if(size==WORD_)
      write_mem16(address,data);
   else
      write_mem8(address,data);
   NOP;
   while(read_reg_s00(0x14)==0) // read ack
   {}
   ////   write_reg_s00(0x08,address);         // address
   ////   write_reg_s00(0x0C,data);    // data
   //   write_reg64_s00(0x08,(((uint64_t)data)<<32)|address);    // data
   //   write_reg_s00(0x10,0x11|WRITE_|size); // command
   //   while(read_reg_s00(0x14)==0) // read ack
   //   {}
   //   write_reg_s00(0x10,0x01); // confirm ack
}
void arm_write_nowait(uint32_t address, uint32_t data)
{
   uint32_t bank=(address>>24)&0xFF;
   write_reg_s00(0x18,bank);
   NOP;
   write_mem32(address,data);
   NOP;
   //   while(read_reg_s00(0x14)==0) // read ack
   //   {}
   write_reg(REG4,0x0); // Bus Hi-Z
}
uint32_t arm_read_amiga(uint32_t address, uint32_t size)
{
   write_reg_s00(0x08,address);        // address
   write_reg_s00(0x10,0x11|READ_|size); // command
   while(read_reg_s00(0x14)==0) // read ack
   {}
   //   write_reg_s00(0x10,0x01); // confirm ack
   data=read_reg_s00(0x1C); // read data
   return(data);
}
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
int main()
{
#ifndef USE_RTOS
   init_platform();
#endif
   /* Enable VFP/NEON before using any NEON instructions */
   enable_vfp_neon();
   
   printf("[Core0] Starting...\n");
   Xil_ICacheEnable();
#ifdef L1_CACHE_ENABLED
   Xil_L1DCacheEnable();
#else
   Xil_L1DCacheDisable();
#endif
#ifdef L2_CACHE_ENABLED
   Xil_L2CacheEnable();
#else
   Xil_L2CacheDisable();
#endif
   //   Xil_L1DCacheDisable();
   //   Xil_L2CacheDisable();

   //   Xil_DisableMMU();
   Xil_SetTlbAttributes(0xFFFF0000UL,NORM_NONCACHE);//0x14DE2);//STRONG_ORDERED|SHAREABLE);//NORM_WT_CACHE);//0x14de2);//NORM_NONCACHE);
   //   for(int i=0x000;i<0x010;i++)
   //      Xil_SetTlbAttributes(i*0x100000UL,NORM_NONCACHE);
   for(int i=0x080;i<0x180;i++)
      Xil_SetTlbAttributes(i*0x100000UL,RAM_CACHE_POLICY);
   for(int i=0x180;i<0x182;i++) // RTG Registers (2 MB reserved, fb is at 0x200000)
      Xil_SetTlbAttributes(i*0x100000UL,NORM_NONCACHE);
   for(int i=0x1FC;i<0x1FE;i++) // AUDIO
      Xil_SetTlbAttributes(i*0x100000UL,AUDIO_CACHE_POLICY);//NORM_NONCACHE);// NORM_WB_CACHE);//0x14de2);
   for(int i=0x1FE;i<0x200;i++) // ETHERNET
      Xil_SetTlbAttributes(i*0x100000UL,ETHERNET_CACHE_POLICY);//NORM_NONCACHE);// NORM_WB_CACHE);//0x14de2);
   for(int i=0x400;i<0x780;i++)
      Xil_SetTlbAttributes(i*0x100000UL,RESERVED);
   for(int i=0x780;i<0x800;i++) //
      Xil_SetTlbAttributes(i*0x100000UL,STRONG_ORDERED);
   for(int i=0xE00;i<0xE03;i++) //
      Xil_SetTlbAttributes(i*0x100000UL,STRONG_ORDERED);//NORM_NONCACHE);

   for(int i=0;i<0x1200;i++)
      *(uint8_t*)(RTG_BASE+0x06000000+i)=0; // clean audio buffer

   configure_gpio();

//   NBR_ARM(0);
//   xc3_usleep(1000);
//   CPLD_RESET_ARM(0);
   int sw1_is_down=0;
   sw1_is_down|=!XGpioPs_ReadPin(&GpioPs, USER_SW1);

   xc3_usleep(1000);
   DiscreteSet(REG0, FPGA_RESET);

   ENABLE_TSCONDITION(FPGA_TSCONDITION0);

   ENABLE_ENCONDITION_PCLK0_CLKEN0;
   //   ENABLE_ENCONDITION_PCLK1_CLKEN0;
   //   ENABLE_ENCONDITION_PCLK0;
   //   ENABLE_ENCONDITION_PCLK1;

   ENABLE_FPGA_ADVANCED_BURST;
   ENABLE_FPGA_PREFETCH_ENABLE;

//   DISABLE_FPGA_ADVANCED_BURST;
//   DISABLE_FPGA_PREFETCH_ENABLE;

   int clk_config=10; // 50 MHz
   int verbose=0;
   int emu=1; //emu=1 will configure the 060 at 50 MHz or less
   switch(clk_config)
   {
   case 0:
      configure_clk(100,verbose,emu);
      break;
   case 1:
      configure_clk(95,verbose,emu);
      break;
   case 2:
      configure_clk(90,verbose,emu);
      break;
   case 3:
      configure_clk(85,verbose,emu);
      break;
   case 4:
      configure_clk(80,verbose,emu);
      break;
   case 5:
      configure_clk(75,verbose,emu);
      break;
   case 6:
      configure_clk(70,verbose,emu);
      break;
   case 7:
      configure_clk(65,verbose,emu);
      break;
   case 8:
      configure_clk(60,verbose,emu);
      break;
   case 9:
      configure_clk(55,verbose,emu);
      break;
   case 10:
      configure_clk(50,verbose,emu);
      break;
   }

   ACTIVITY_LED_OFF; // OFF
   DiscreteClear(REG0,FPGA_INT6); // set int6 to 0 (active high)

   //   printf("\033[2J");
   printf("Z3660 starting...\n\n");
   printf(" ________   ______   ______   ______   ______ \n");
   printf("|___    /  |____  | |  ____| |  ____| |  __  | a.k.a. PishaStorm\n");
   printf("    /  /    ____| | | |____  | |____  | |  | | a.k.a. N\314\203Storm\n");
   printf("   /  /    |____  | |  __  | |  __  | | |  | |\n");
   printf("  /  /___   ____| | | |__| | | |__| | | |__| |\n");
   printf(" /_______| |______| |______| |______| |______|\n");
   printf("\n");
   printf("FPGA version number 0x%08lX\n",read_reg_s01(REG2));
   printf("ARM IDCODE 0x%08lX\n",*(uint32_t*)0xF8000530);
   unsigned long si_ver = ps7GetSiliconVersion ();

   int pcw_ver = 0;
   float silicon_MHZ=666.666667;
   if (si_ver == PCW_SILICON_VERSION_1) {
      pcw_ver = 1;
      silicon_MHZ=666.666667;
   } else if (si_ver == PCW_SILICON_VERSION_2) {
      pcw_ver = 2;
      silicon_MHZ=766.666667;
   } else {
      pcw_ver = 3;
      silicon_MHZ=866.666667;
   }
   printf("[Core0] ARM Silicon Version %d -> %3.3f MHz Max\n",pcw_ver, silicon_MHZ);
   printf("Current CPU Frequency: %3.3f MHz\n",get_current_cpu_frequency()/1000000.0f);

   // A more robust way to detect if the CPUCLK and CLK90 are connected to the FPGA
   // @kavanoz detected this issue in a board with version 0.23. It always detected the CPUCLK and CLK90 even if the jumpers were in EXT position.
   // The problem was that the CPUCLK output was always enabled or counters were not cleared, so the FPGA detected it.
   // The solution is to disable the CPUCLK output for a while (also reseting the counters).
   DISABLE_CPUCLK_OUTPUT_FPGA;
   usleep(1000);
   ENABLE_CPUCLK_OUPUT_FPGA;
   usleep(10000);

   int register6=read_reg_s01(REG6);
   if(register6&(FPGA_CLK90_DETECTED|FPGA_CPUCLK_DETECTED))
   {
      DISABLE_CPUCLK_OUTPUT_FPGA;
      if((register6&(FPGA_CLK90_DETECTED|FPGA_CPUCLK_DETECTED))==FPGA_CPUCLK_DETECTED)
         printf("\e[31m\e[103mFPGA detected CPUCLK!!! For the love of your Amiga, change it now to EXT position !!!\e[0m\n");
      else if((register6&(FPGA_CLK90_DETECTED|FPGA_CPUCLK_DETECTED))==FPGA_CLK90_DETECTED)
         printf("\e[31m\e[103mFPGA detected CLK90!!! For the love of your Amiga, change it now to EXT position !!!\e[0m\n");
      else
         printf("\e[31m\e[103mFPGA detected CPUCLK and CLK90!!! For the love of your Amiga, change them now to EXT position !!!\e[0m\n");
      init_shared();
      VolToPart[1].pd=0; // point second volume to second partition
      VolToPart[1].pt=2;
      read_config_file(0);
      read_env_files(0);
      show_bootscreen();
      mobo_change_jumpers(register6);
      while(1);
   }
   else
   {
      ENABLE_CPUCLK_OUPUT_FPGA;
   }
   

#if REVISION_BETA > 0
   if(revision_alfa > 0)
      printf("BOOT.bin version number %d.%02d (BETA %d ALFA %ld)\n",REVISION_MAJOR,REVISION_MINOR,REVISION_BETA,revision_alfa);
   else
      printf("BOOT.bin version number %d.%02d (BETA %d)\n",REVISION_MAJOR,REVISION_MINOR,REVISION_BETA);
#else
   printf("BOOT.bin version number %d.%02d\n",REVISION_MAJOR,REVISION_MINOR);
#endif
   int enable_ram=1;       // RAM initial state
   int enable_rtg=0;       // RTG initial state
   int enable_z3ram=1;     // Z3 RAM initial state
   int enable_maprom=1;    // MAPROM initial state
   int enable_mapromext=1; // MAPROM initial state

   fpga_feature_enable(enable_ram,enable_rtg,enable_z3ram,enable_maprom,enable_mapromext);
   sw1_is_down|=!XGpioPs_ReadPin(&GpioPs, USER_SW1);

   init_shared();

   VolToPart[1].pd=0; // point second volume to second partition
   VolToPart[1].pt=2;

   read_config_file(1);

   read_env_files(1);

   switch(config.arm_frequency)
   {
      case FREQ_667:
         counts_per_second=666666687 / 2;
         break;
      case FREQ_767:
         counts_per_second=766666687 / 2;
         break;
      case FREQ_867:
         counts_per_second=866666687 / 2;
         break;
      case FREQ_900:
         counts_per_second=900000021 / 2;
         break;
      case FREQ_933:
         counts_per_second=933333355 / 2;
         break;
      case FREQ_967:
         counts_per_second=966666689 / 2;
         break;
      case FREQ_1000:
         counts_per_second=1000000023 / 2;
         break;
      case FREQ_1033:
         counts_per_second=1033333355 / 2;
         break;
      case FREQ_1067:
         counts_per_second=1066666689 / 2;
         break;
      case FREQ_1100:
         counts_per_second=1100000000 / 2;
         break;
      case FREQ_1133:
         counts_per_second=1133333333 / 2;
         break;
      case FREQ_1167:
         counts_per_second=1166666667 / 2;
         break;
      case FREQ_1200:
         counts_per_second=1200000000 / 2;
         break;
      case FREQ_1233:
         counts_per_second=1233333333 / 2;
         break;
      case FREQ_1267:
         counts_per_second=1266666667 / 2;
         break;
      case FREQ_1300:
         counts_per_second=1300000000 / 2;
         break;
      default:
         counts_per_second=666666687 / 2;
         config.arm_frequency=FREQ_667;
   }

   shared->arm_freq_code=config.arm_frequency;
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

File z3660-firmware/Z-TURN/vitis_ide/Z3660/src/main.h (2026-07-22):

/*
 * main.h
 *
 *  Created on: 8 jun. 2022
 *      Author: shanshe
 */

#ifndef SRC_MAIN_H_
#define SRC_MAIN_H_

#include "version.h"

#define INT_IPL_ON_THIS_CORE 0

#define NO_ARM_RESET_ON_AMIGA_RESET
//#define CPU_FIXED_FREQUENCY

#define M_PI 3.14159265358979323846

#include "platform.h"
#include "xgpiops.h"
#include "xil_io.h"
#include "xscugic.h"

#include "xil_cache.h"
#include "xil_cache_l.h"
#include "xil_exception.h"
//#define sleep sleep_seconds
//#define usleep sleep_microseconds
#include "xclk_wiz.h"
//#undef sleep
//#undef usleep
#include "xadcps.h"
#include "xuartps.h"

#include <ff.h>

#include "xaxivdma.h"
#include "sii9022_init/sii9022_init.h"
#include "xil_types.h"
#include "rtg/zz_video_modes.h"

#include "rtg/gfx.h"
#include "video.h"
#include "ethernet.h"
#include "interrupt.h"
#include "adc.h"
#include "ax.h"
#include "usb.h"
#include "xpseudo_asm.h"
#include <xparameters.h>

#define ETH_BACKLOG_NAG_COUNTER_MAX_060 1500
#define ETH_BACKLOG_NAG_COUNTER_MAX_EMU 1500

// comment out if you don't want to compile CPU emulators (Musashi and UAE)
#define CPU_EMULATOR

#define OP_PALETTE 3
#define OP_PALETTE_HI 19

#define PS_MIO_0      0 // MIO  0
#define PS_MIO_4      4 // MIO  4
#define PS_MIO_5      5 // MIO  5
#define PS_MIO_8      8 // MIO  8
#define PS_MIO_9      9 // MIO  9
#define PS_MIO_10    10 // MIO 10
#define PS_MIO_11    11 // MIO 11
#define PS_MIO_12    12 // MIO 12
#define PS_MIO_13    13 // MIO 13
#define PS_MIO_15    15 // MIO 15
#define PS_MIO_50    50 // MIO 50
#define PS_MIO_51    51 // MIO 51

typedef struct {
   volatile uint32_t shared_data;         // 0xFFFF0000
   volatile uint32_t write_rtg;           // 0xFFFF0004
   volatile uint32_t write_rtg_addr;      // 0xFFFF0008
   volatile uint32_t write_rtg_data;      // 0xFFFF000C
   volatile uint32_t core0_hold;          // 0xFFFF0010
   volatile uint32_t core0_hold_ack;      // 0xFFFF0014
   volatile uint32_t irq;                 // 0xFFFF0018
   volatile uint32_t uart_semaphore;      // 0xFFFF001C
   volatile uint32_t jit_enabled;         // 0xFFFF0020
   volatile uint32_t reset_emulator;      // 0xFFFF0024
   volatile uint32_t load_rom_emu;        // 0xFFFF0028
   volatile uint32_t load_rom_addr;       // 0xFFFF002C
   volatile uint32_t int_available;       // 0xFFFF0030
   volatile uint32_t cfg_emu;             // 0xFFFF0034
   volatile uint32_t write_scsi;          // 0xFFFF0038
   volatile uint32_t write_scsi_addr;     // 0xFFFF003C
   volatile uint32_t write_scsi_data;     // 0xFFFF0040
   volatile uint32_t write_scsi_type;     // 0xFFFF0044
   volatile uint32_t read_scsi;           // 0xFFFF0048
   volatile uint32_t read_scsi_addr;      // 0xFFFF004C
   volatile uint32_t read_scsi_data;      // 0xFFFF0050
   volatile uint32_t read_scsi_type;      // 0xFFFF0054
   volatile uint32_t scsiboot_rom_loaded; // 0xFFFF0058
   volatile uint32_t write_scsi_in_progress; // 0xFFFF005C
   volatile uint32_t read_rtg;            // 0xFFFF0060
   volatile uint32_t read_rtg_addr;       // 0xFFFF0064
   volatile uint32_t read_rtg_data;       // 0xFFFF0068
   volatile uint32_t mmu_core1_add;       // 0xFFFF006C
   volatile uint32_t z3_enabled;          // 0xFFFF0070
   volatile uint32_t load_ext_rom_addr;   // 0xFFFF0074
   volatile uint32_t load_romext_emu;     // 0xFFFF0078
   volatile uint32_t nops_write;          // 0xFFFF007C
   volatile uint32_t nops_read;           // 0xFFFF0080
   volatile uint32_t disassemble;         // 0xFFFF0084
   volatile uint32_t musashi_step;        // 0xFFFF0088
   volatile uint32_t reset_emulator_dis;  // 0xFFFF008C
   volatile uint32_t z2_enabled;          // 0xFFFF0090
   volatile uint32_t printhist_dataabort; // 0xFFFF0094
   volatile uint32_t arm_freq_code;       // 0xFFFF0098
   volatile uint32_t write_floppy;        // 0xFFFF009C
   volatile uint32_t write_floppy_addr;   // 0xFFFF00A0
   volatile uint32_t write_floppy_data;   // 0xFFFF00A4
   volatile uint32_t write_floppy_type;   // 0xFFFF00A8
   volatile uint32_t read_floppy;         // 0xFFFF00AC
   volatile uint32_t read_floppy_addr;    // 0xFFFF00B0
   volatile uint32_t read_floppy_data;    // 0xFFFF00B4
   volatile uint32_t read_floppy_type;    // 0xFFFF00B8
} SHARED;
extern SHARED *shared;
#define REG_BASE_ADDRESS XPAR_Z3660_0_BASEADDR
#define write_reg(Offset,Data) (*(volatile uint32_t *)(REG_BASE_ADDRESS+(Offset)))=(Data)
#define read_reg(Offset) (*(volatile uint32_t *)(REG_BASE_ADDRESS+(Offset)))

#define BIT0  (1<<0)
#define BIT8  (1<<8)
#define BIT9  (1<<9)
#define BIT12 (1<<12)
#define BIT13 (1<<13)
#define BIT15 (1<<15)
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

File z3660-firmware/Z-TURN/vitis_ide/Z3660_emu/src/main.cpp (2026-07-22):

/*
 * main.cc
 */

#include <stdio.h>
#include <xil_cache.h>
#include <xil_cache_l.h>
#include <xil_mmu.h>
#include <inttypes.h>
#include "xgpiops.h"
#include "xparameters.h"
#include "main.h"
#include "xil_exception.h"
#include "xdmaps.h"
#include "xscugic.h"
#include "xscutimer.h"
#include "memorymap.h"
#include "ps7_init_simple.h"

#define DEFAULT_NOPS_WRITE 0
#define DEFAULT_NOPS_READ 0

#define MUSASHI_EMULATOR
#define UAE_EMULATOR
#ifdef MUSASHI_EMULATOR
#include "cpu_emulator.h"
#endif
#ifdef UAE_EMULATOR
#include "uae_emulator.h"
#endif

#include "newcpu.h"
#include "custom.h"
#include "defines.h"

SHARED *shared;
extern LOCAL local;
extern "C" void z3660_printf(const TCHAR *format, ...)
{
   va_list args{};
   va_start(args, format);
   while(shared->uart_semaphore!=0);
   shared->uart_semaphore=1;
   vprintf(format, args);
   shared->uart_semaphore=0;
   va_end(args);
}
extern uint32_t MMUTable;
#pragma align 1024
uint32_t MMUL2Table[256] __attribute__ ((aligned (1024)));
void init_shared(void)
{
   shared=(SHARED *)0xFFFF0000;
   shared->mmu_core1_add=(uint32_t)(&MMUTable);
   shared->nops_write=DEFAULT_NOPS_WRITE;
   shared->nops_read=DEFAULT_NOPS_READ;
}
XGpioPs GpioPs;
XGpioPs_Config *GpioPsConfigPtr;
/*
#define TIMEOUT_MAX 20000
uint32_t timeout=TIMEOUT_MAX;
uint32_t timeoutmax=TIMEOUT_MAX;
 */
uint32_t data=0;
extern uint8_t *ROM;
extern uint8_t *EXT_ROM;

extern "C" void load_rom(void)
{
   while(shared->load_rom_emu==0){}
   ROM=(uint8_t *)shared->load_rom_addr;
   printf("load rom emu %d\n",shared->load_rom_emu);
}
extern "C" void load_romext(void)
{
   while(shared->load_romext_emu==0){}
   EXT_ROM=(uint8_t *)shared->load_ext_rom_addr;
   printf("load romext emu %d\n",shared->load_romext_emu);
}
int read_irq=0;
extern "C" int intlev(void)
{
   return(read_irq);
}
#define NOP asm(" nop")

uint16_t last_zaddr=0xFFFF;
uint16_t last_zaddr1=0xFFFF;
uint16_t last_zaddr2=0xFFFF;
uint16_t last_zaddr3=0xFFFF;
uint32_t last_zdata=0xFFFFFFFF;
uint32_t last_zdata1=0xFFFFFFFF;
int last_type1=-1;
int last_type2=-1;

extern "C" void write_rtg_register(uint16_t zaddr,uint32_t zdata)
{
   //    if(zaddr!=last_zaddr)
   shared->write_rtg_addr=zaddr;
   //    if(zdata!=last_zdata)
   shared->write_rtg_data=zdata;
   //    last_zaddr=zaddr;
   //    last_zdata=zdata;
   //    	Xil_L1DCacheFlush();
   shared->write_rtg=1;
   dsb();
   shared->shared_data=1;
   while(shared->write_rtg==1){NOP;}
}
extern "C" uint32_t read_rtg_register(uint16_t zaddr)
{
   //    if(zaddr!=last_zaddr3)
   shared->read_rtg_addr=zaddr;
   //    last_zaddr3=zaddr;
   shared->read_rtg=1;
   dsb();
   //    Xil_L1DCacheInvalidate();
   shared->shared_data=1;
   while(shared->read_rtg==1){NOP;}
   uint32_t data=shared->read_rtg_data;
   //    if(zaddr>=0x1A0 && zaddr<=0x238)
   //    	printf("[EMU] RTG read reg 0x%03X = 0x%08X\n",zaddr,data);
   return(data);
}
enum piscsi_cmds {
   PISCSI_CMD_WRITE        = 0x00,
   PISCSI_CMD_READ         = 0x04,
   PISCSI_CMD_DRVNUM       = 0x08,
   PISCSI_CMD_DRVTYPE      = 0x0C,
   PISCSI_CMD_BLOCKS       = 0x10,
   PISCSI_CMD_CYLS         = 0x14,
   PISCSI_CMD_HEADS        = 0x18,
   PISCSI_CMD_SECS         = 0x1C,
   PISCSI_CMD_ADDR1        = 0x20,
   PISCSI_CMD_ADDR2        = 0x24,
   PISCSI_CMD_ADDR3        = 0x28,
   PISCSI_CMD_ADDR4        = 0x2C,
   PISCSI_CMD_DEBUGME      = 0x30,
   PISCSI_CMD_DRIVER       = 0x50,
   PISCSI_CMD_NEXTPART     = 0x54,
   PISCSI_CMD_GETPART      = 0x58,
   PISCSI_CMD_GETPRIO      = 0x5C,
   PISCSI_CMD_WRITE64      = 0x60,
   PISCSI_CMD_READ64       = 0x64,
   PISCSI_CMD_CHECKFS      = 0x70,
   PISCSI_CMD_NEXTFS       = 0x74,
   PISCSI_CMD_COPYFS       = 0x78,
   PISCSI_CMD_FSSIZE       = 0x7C,
   PISCSI_CMD_SETFSH       = 0x80,
   PISCSI_CMD_BLOCKSIZE    = 0x84,
   PISCSI_CMD_READBYTES    = 0x88,
   PISCSI_CMD_WRITEBYTES   = 0x8C,
   PISCSI_CMD_DRVNUMX      = 0x90,
   PISCSI_CMD_LOADFS       = 0x94,
   PISCSI_CMD_GET_FS_INFO  = 0x98,
   PISCSI_CMD_USED_DMA     = 0x9C,
   PISCSI_DBG_MSG          = 0x100,
   PISCSI_DBG_VAL1         = 0x110,
   PISCSI_DBG_VAL2         = 0x114,
   PISCSI_DBG_VAL3         = 0x118,
   PISCSI_DBG_VAL4         = 0x11C,
   PISCSI_DBG_VAL5         = 0x120,
   PISCSI_DBG_VAL6         = 0x124,
   PISCSI_DBG_VAL7         = 0x128,
   PISCSI_DBG_VAL8         = 0x12C,
   PISCSI_CMD_ROM          = 0x4000,
};
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

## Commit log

2021-10-22 Add schematics and gerber v01 files
    [A3660_v01-B_Cu.gbr, A3660_v01-B_Mask.gbr, A3660_v01-B_Paste.gbr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]
2021-10-23 Add schematic comment about PCLK termination resistor.
2021-10-31 Update Readme with exact version of Z-Turn board needed
2022-07-02 Update to v02
    [A3660_v01-B_Cu.gbr, A3660_v01-B_Mask.gbr, A3660_v01-B_Paste.gbr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]
2023-07-17 Update to version v021. DMA working with real CPU
    DMA in CPU emulation: Work in progress...
    [Z3660_v02-B_Cu.gbr, Z3660_v02-B_Mask.gbr, Z3660_v02-B_Paste.gbr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]
2023-08-01 Add readme to drivers and adf with the drivers.
2023-08-04 Deleted old BOM pdf file, and generated html BOM file.
2023-08-06 Correctly printed schematic with drawing sheet.
2023-08-08 Upload two versions of CPLD (DMA and no DMA)
2023-08-13 BOM revision. Capacitor C27 as NC (Not Connected)
2023-08-13 drivers makefile update: add Z3660 monitor, exclude scsiboot rom
2023-08-13 ZTop app shows some more measures (voltages and temp from LTC2990)
2023-08-13 Add feature: LED activity from SD-SCSI with JP6 and JP7
2023-08-13 Driver I2C for LTC2990 (voltage a temp measures)
2023-08-13 Updated BOM with LTC2990
2023-09-27 Update drivers. (version lowered to 1.01)
2023-09-27 Update of drivers adf, BOOT.bin, and readmes...
2023-09-28 Update z3660cfg.txt file with resistor calibration
2024-01-03 Upload kicad files
    [8817-200-170S-F.stp, Sheet1.kicad_sch, Sheet1.sch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]
2024-01-07 Update to version v0.21a
    [Sheet1.kicad_sch, Sheet1.sch, Sheet2.kicad_sch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]
2024-01-08 Update led values values to differentiate green and red.
    [Sheet5.kicad_sch, Z3660_v021a.sch]
2024-01-08 Uploaded BOM and CPL files for JLCPCB (thanks to @kavanoz).
    [BOM-Z3660_v021a.csv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]
2024-01-31 v1.02 CPLD: getting close to DMA version (but still without DMA)
2024-01-31 Update vivado and vitis projects to v1.02
    [Z3660_v02_BOM.csv, Z3660_v02_with_Zturn_BOM.xlsx, Z3660_v02_without_Zturn_BOM.xlsx]
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2024-02-09 [PCB] v0.21b Update 060 socket
    [BOM-Z3660_v021a.csv, BOM-Z3660_v021b.csv, Sheet1.kicad_sch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]
2024-02-10 Updated pick and place files for v0.21b
    [BOM-Z3660_v021b.csv, jlcpcb-mapping.csv]
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2024-03-03 Update to PCB v0.21d Minor change in footprint of fans
    [Sheet1.kicad_sch, Sheet2.kicad_sch, Sheet3.kicad_sch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]
2024-03-04 Updated pick and place files for v0.21d
    [BOM-Z3660_v021d.csv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]
2024-06-27 Upload correct version of eth driver (device.c)
2024-10-04 Hardware version v.022 adds CPLD programmer. Also a tiny PCB for v.021x
    [22-14-2044.stp, BOM-Z3660_v022.csv, Sheet1.kicad_sch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]
2024-10-04 Z3660 v.021x CPLD programmer: changed the dimmension of the board
    [BOM-Z3660_CPLD_prog.csv, CPL-Z3660_CPLD_prog.csv, Z3660_CPLD_prog-CuBottom.gbr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]
2024-10-05 Updated pick and place files and change log for the board.
    [BOM-Z3660_v022.csv, jlcpcb-mapping.csv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]
2024-11-08 Update drivers, rtl and ARM software upto version 1.03 beta 14
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2025-12-28 Upload poseidon driver (still not working)
    [usbhardware.h]
2026-04-25 z3660: support headless firmware image builds
    Add a repo-level make target and teach the Vitis makefile to build the
    FSBL, core0 firmware, core1 emulator and SD-card boot images without the
    Xilinx UI.
    Use native SDK 2018.3 bootgen on Linux, while preserving the existing
    macOS Wine bootgen.exe flow. Add a checked-in command-line BIF for Linux
    builds and copy the generated BOOT.BIN to Z3660.BIN and FAILSAFE.BIN.
    Fix Linux build failures caused by case-sensitive include paths, Xilinx
    sleep.h/newlib usleep conflicts and missing bare-metal FP environment
    defines. Ignore generated Vivado and Vitis build outputs while allowing
    the reproducible command-line BIF to be tracked.
    [main.c]
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2026-05-13 Upload PCB v0.23 version by @kavanoz
    [8817-200-170S-F.stp, BOM-Z3660_v021b.csv, BOM-Z3660_v021d.csv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]
2026-07-11 Add SD-card file manager for the boot serial console
    New self-contained module (sd_fileops.c/.h) implementing a small "SD>"
    command loop over the serial UART, operating on both SD volumes: 0: (FAT
    boot) and 1: (exFAT data, where the hdf images live under 1:/hdf/). Paths
    take an explicit volume prefix.
    Commands: DIR, COPY, REN, DEL, MKDIR, CRC, FREE, HELP and EXIT.
    COPY is a generalized, streamed version of the existing fixed BOOT.bin /
    FAILSAFE.bin / Z3660.bin copy shortcuts: it copies arbitrary files of any
    size through a chunk buffer (tried from 4 MB down to 64 KB), prints
    progress, verifies the read total against the write total, asks before
    overwriting an existing destination and can b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
2026-07-29 rtg: upload the template when BytesPerRow is zero
    Template->BytesPerRow is the offset from one template line to the next, not
    a size, so P96 passes 0 when a single line repeats down the whole rectangle.
    BytesPerRow * h is then 0 bytes and the board blits whatever the previous op
    left in the template buffer.
    Found by p96cts BltPattern-drawmodes, which P96 renders as a repeating
    one-line template under JAM2 | COMPLEMENT.
2026-07-29 rtg: leave COMPLEMENT lines to Picasso96
    struct Line does not carry the RastPort's FRST_DOT state, so an accelerated
    COMPLEMENT line cannot tell a fresh Draw from one continuing at a shared
    vertex. Drawing that vertex twice is visible under XOR.
    Found by p96cts DrawLine-complement, a closed pentagram whose five vertices
    are each shared by two Draw() calls: four pixels came back inverted. Ported
    from the ZZ9000 driver, which stopped accelerating this mode for the same
    reason.
2026-08-17 scsi: use whole-hierarchy cache maintenance at the direct-DMA sites
    The two direct-DMA paths in handle_piscsi_reg_write() maintain only L1,
    although the comments above both calls describe L1+L2 and the buffer is
    shared with the SD controller's DMA, which accesses DRAM below the PL310
    L2.
    On a WRITE, Xil_L1DCacheFlushRange() cleans the guest's bytes out of L1 but
    leaves them dirty in the L2. XSdPs_WritePolled() performs no cache
    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
2026-08-17 scsi: enlarge the fast-seek link map table to 256 items
    A FatFs link map table is [size][ncl,tcl]...[0], so N items describe
    (N - 2) / 2 fragments: SeekTbl[64] covered only 31. Past that
    f_lseek(CREATE_LINKMAP) returns FR_NOT_ENOUGH_CORE and the drive falls back
    to the generic cluster-chain walk, and 31 fragments is not hard to exceed
    for a large .hdf written to a card whose free space is already broken up.
    256 items raise the limit to 127 fragments. The cost is 768 bytes of bss per
    PISCSI_DEV and nothing else: the table is not initialised data, so BOOT.BIN
    does not grow, and every user of the table already derives its bounds from
    sizeof SeekTbl.
2026-10-11 config: parse hex letters in mac_address correctly
    get_mac_address_type() assigned instead of subtracting for a-f and tested
    only 'F' for upper case, so every hex letter was misread: 00:80:1A:01:02:04
    became 00:80:51:01:02:04, and lower case a-f all became 0xA9. The preset
    writer saves the MAC as %02X, so a MAC with a letter never survives a save
    and reload. Non-hex characters are now rejected (BAD Mac Address) instead of
    turning into garbage bytes.
2026-10-11 ZTop: accept lower case 'f' in the MAC address field
    hex2int() folded only a-e to upper case, so an 'f' typed in the MAC
    gadget became a 0 nibble.
2026-10-17 scsi: keep the CD flag per image slot, not per SCSI target
    isoN set cd_target[N] by image slot, but piscsi_init() read
    cd_target[target], so a CD worked only when its slot number equalled its
    target (the shipped iso6 + scsi4 6 maps a read-write disk), and
    iso7..iso19 wrote past cd_target[7] into adf_num[] and hdf[0]. Keep
    is_iso[20] beside hdf[20] and look it up through scsi_num[]; configs
    that already use isoN + scsiN N behave the same.
2026-10-17 core0: monitor_switch() passes a real timeout to the CIA-B accessors
    main.c declared arm_read/write_amiga_byte with the core1 two-argument
    signatures, but core0 links the mobotest.c versions, which store their
    timeout count through int *timeout. Every monitor_switch access wrote
    through a garbage pointer, and on an A4000T with monitor_switch set the
    boot hung. Use the real prototypes, pass &timeout on all four accesses,
    skip with one [MONSW] line on no bus ack, and return before touching the
    bus when monitor_switch selects nothing.
2026-10-17 scsi: never divide by a zero block size in the BLOCKS registers
    BLOCKS, BLOCKS0+4n and BLOCKS10+4n return fs / block_size unguarded.
    block_size is 0 for an unmapped unit, which the boot bus scan reads on
    every boot, and for a mapped unit whose RDB has rdb_BlockBytes 0.
    libgcc's __aeabi_uldivmod returns 0 for 0/0 and all ones for n/0, so the
    second case reports 4294967295 blocks to TD_GETGEOMETRY and READ
    CAPACITY. Route all three through piscsi_unit_blocks(), which returns 0
    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
2026-10-17 floppy: check the z3660_scsi.rom open before parsing it as hunks
    pifloppy_init() ignored the f_open and f_lseek results, so with
    z3660_scsi.rom missing it ran process_hunks() on an uninitialised stack
    FIL and printed "Unknown hunk type 00000000". Print which file failed
    and skip the parse instead. 0x2600 is left as found: it is not
    PISCSI_DRIVER_OFFSET and holds zeros in the v1.5 image.
2026-10-17 scsi: refuse a request whose f_lseek or f_write failed
    The six f_lseek calls that position the .hdf for READBYTES / READ /
    READ64 / WRITEBYTES / WRITE / WRITE64 and the two f_write calls ignored
    their FRESULT. A failed seek leaves fptr where the previous request
    ended, so the transfer read or wrote the wrong sectors and reported
    success. Refuse the request instead: nothing is transferred, used_dma
    is 0, and the failure is printed (rate limited).
2026-10-17 piscsi: find an RDB in blocks 1..15 when block 0 is empty
    The image-file scan read 64 KB per step and tested only the first four bytes,
    so an RDB in blocks 1..15 (RDB_LOCATION_LIMIT, devices/hardblocks.h) was never
    seen; Amiga UNIX disks keep the RDB at block 2. Block 0 is still decided first;
    blocks 1..15 are scanned only when block 0 is all zero, with the RDB checksum.
    Policy in rdb_scan.h; host test in test/rdb_scan_test.cpp (32 checks).
